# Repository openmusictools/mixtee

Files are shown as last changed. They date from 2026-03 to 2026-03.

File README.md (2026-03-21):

# MIXTEE

**Open-source 16-input / 8-output digital mixer with MIDI control and 16-track recording.**

Built around the Teensy 4.1, MIXTEE is a compact desktop mixer designed for electronic musicians, synth enthusiasts, and DIY audio builders. It handles mixing, monitoring, MIDI control, multitrack recording to SD card, and 16-in/8-out AES67 network audio — all in a 260 × 100 × 50 mm enclosure.

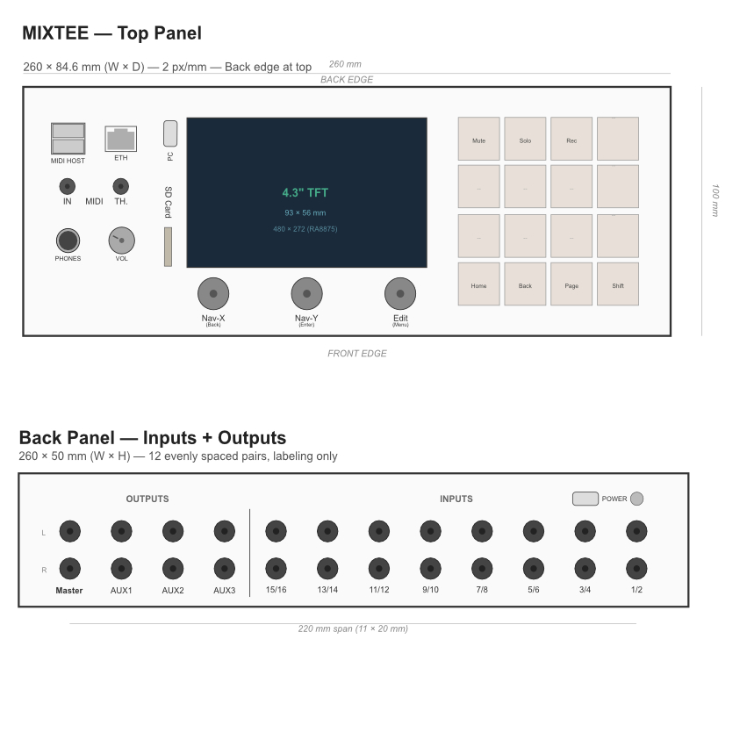
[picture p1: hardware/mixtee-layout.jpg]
MIXTEE Layout


## Features

- **16 mono inputs** (8 stereo pairs) with per-channel gain, pan, mute, solo
- **8 outputs** (master stereo + 3 aux/FX sends)
- **16-track recording** direct to SD card (48 kHz / 24-bit WAV, 8 MB PSRAM buffer)
- **DAW connectivity** (16-in / 8-out via AES67 over Ethernet)
- **MIDI control** via 2× USB host ports + TRS MIDI in/out
- **4.3" TFT display** with 3 dedicated encoders (NavX, NavY, Edit) and 16 illuminated CHOC keys
- **Compact form factor** — 260 × 100 × 50 mm, all controls on top, all audio on back

## Architecture

MIXTEE uses four AK4619VN codecs on two TDM buses, driven by the Teensy 4.1's Cortex-M7 at 600 MHz. The analog front-end features OPA1678 op-amps with Sallen-Key anti-alias and reconstruction filters. Power is supplied via USB-C (5V/5A USB PD, fallback 5V/3A). DAW connectivity uses AES67 network audio over Ethernet (100 Mbps, DP83825I PHY on Teensy).

## Repository Structure

```
mixtee/
├── README.md              ← you are here
├── LICENSE                ← MIT (firmware) + CERN-OHL-P v2 (hardware) + CC BY 4.0 (docs)
├── docs/                  ← system-level design specifications
│   ├── system-topology.md ← board summary, connector summary, back panel layout
│   ├── hardware.md        ← codecs, power system, BOM, target specs
│   ├── pin-mapping.md     ← Teensy 4.1 pin assignments, GPIO budget
│   ├── features.md        ← control interface, mixing, recording, MIDI, USB audio
│   ├── firmware.md        ← software architecture, libraries, state management
│   ├── ui-architecture.md ← view/page/module hierarchy, screen layouts
│   ├── enclosure.md       ← physical dimensions, panel layouts, jack spacing
│   ├── usb-audio.md       ← USB audio details + optional multitrack upgrade paths
│   ├── connector-parts.md ← connector MPN index
│   ├── pcb-design-rules.md ← trace widths, clearances, via sizes, manufacturing
│   └── pcbs-workflow.md   ← PCB design pipeline (SKiDL → FreeRouting → Gerbers)
├── hardware/              ← schematics, PCB, mechanical, BOM
│   ├── bom.csv            ← bill of materials
│   ├── mixtee-layout.*    ← panel layout (SVG, JPG, Affinity Designer)
│   ├── lib/               ← shared KiCad footprint library
│   └── pcbs/              ← per-board directories
│       ├── main/              ← Main Board (4-layer, not started)
│       ├── input-mother/      ← Input Mother Board (4-layer, routed)
│       ├── daughter-output/   ← Daughter/Output Board (2-layer, routed)
│       ├── io/                ← IO Board (2-layer, routed)
│       ├── keys4x4/           ← Keys4x4 PCB (2-layer, routed)
│       └── power/             ← Power Board (off-the-shelf)
│       Each board has: README.md, connections.md, architecture.md,
│       CLAUDE.md, and designs/ (KiCad files + gerbers)
└── firmware/              ← Teensy 4.1 firmware (coming in Phase 1)
```

## Documentation

### System-Level Docs

| Document | Description |
| --- | --- |
| [System Topology](docs/system-topology.md) | Board summary, connector summary, back panel layout, mechanical mounting |
| [Hardware](docs/hardware.md) | Codec architecture, power system, BOM tables, target specs |
| [Pin Mapping](docs/pin-mapping.md) | Teensy 4.1 pin assignments, GPIO budget |
| [Features](docs/features.md) | Mixing, routing, recording, MIDI control, DAW audio |
| [Firmware](docs/firmware.md) | Software architecture, audio pipeline, state management |
| [UI Architecture](docs/ui-architecture.md) | Display hierarchy, navigation model, screen layouts |
| [Enclosure](docs/enclosure.md) | Physical dimensions, panel layouts, connector placement |
| [Network Connectivity](docs/network-connectivity.md) | AES67 network audio, DAW integration, discovery protocols |
| [Connector Parts](docs/connector-parts.md) | Connector MPN index |
| [PCB Design Rules](docs/pcb-design-rules.md) | Trace widths, clearances, via sizes, stackup, manufacturing rules |

### Per-Board Docs

Each board under `hardware/pcbs/` has its own `README.md` (concept), `connections.md` (pinouts), and `architecture.md` (circuits). See the [System Topology](docs/system-topology.md) for the board summary table with links.

## Status

**Pre-prototype / Design phase.** Hardware and firmware specifications are being finalized. Phase 1 breadboard bring-up is next.

## License

MIXTEE is fully open source. Hardware is licensed under CERN-OHL-P v2 (permissive), firmware under MIT, and documentation under CC BY 4.0. See [LICENSE](LICENSE) for details.

**Author:** Juliusz Fedyk — [openaudiotools.com](https://openaudiotools.com)

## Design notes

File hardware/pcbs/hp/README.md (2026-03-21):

# PHONEE — Headphone Output Module

> **Note:** The canonical PHONEE specification lives in
> [openaudiotools/phonee](https://github.com/openaudiotools/phonee).
> This directory contains MIXTEE-specific integration context.
> Design changes should be made in PHONEE first and synced here.

**Dimensions:** ~30 × 20 mm | **Layers:** 2 | **Orientation:** Horizontal, under top panel (left zone) | **Instances:** 1

PHONEE is a **reusable headphone output module** — a standalone custom PCB designed for use across multiple audio devices (similar to [DESPEE](https://github.com/openaudiotools/despee) for displays). It carries a TPA6132A2 headphone amp, PCB-mount volume pot, and 1/4" TRS jack on a single board.

In MIXTEE, PHONEE sits in the **galvanically isolated analog domain**. It receives Master L/R audio and isolated power from Board 1-top (Input Mother TDM1) via a 4-pin JST-PH cable. Entire board runs on GND_ISO — no connection to system GND.

## Key Components

- TPA6132A2 headphone amplifier IC (SOT-23-8, ground-referenced, capless output)
- 10kΩ log potentiometer — PCB-mount (A10K)
- 1/4" TRS headphone jack (panel-mount, with detect switch)
- 4-pin JST-PH connector (signal + power input)

## Why a Reusable Module

- Keeps headphone output fully in the isolated analog domain without complicating the IO Board with split ground planes
- Single-board solution (amp + pot + jack) that can be dropped into any audio device needing a headphone output
- No off-the-shelf module combines all three components — this fills that gap
- Canonical source: [openaudiotools/phonee](https://github.com/openaudiotools/phonee)

## See Also

- [`connections.md`](connections.md) — connector pinouts (4-pin input cable, headphone jack)
- [`architecture.md`](architecture.md) — amp circuit, power, headphone detect routing
- [`../input-mother/connections.md`](../input-mother/connections.md) — Board 1-top HP cable pinout (source)

## Status

Not started. Design phase — will be developed in [openaudiotools/phonee](https://github.com/openaudiotools/phonee).

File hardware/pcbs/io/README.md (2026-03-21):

# IO Board

**Dimensions:** ~50 x 80 mm | **Layers:** 2 | **Orientation:** Horizontal, under top panel (left side) | **Instances:** 1

Handles Ethernet, USB MIDI host, and MIDI IN/OUT. All panel-mount components in the left column of the top panel. Headphone amp has moved to a standalone PHONEE module in the isolated analog domain.

## Key ICs

- FE1.1s USB 2.0 hub (SSOP-28) + 12 MHz crystal
- 2× TPS2051 USB host power switches (SOT-23-5)
- 6N138 optocoupler (DIP-8) — MIDI IN galvanic isolation

## Functional Zones

```
┌──────────────────────────────────────────────────────────────┐
│  USB-A (panel)   RJ45 (panel)                               │ y=0 (panel edge)
│                                                              │
│  FE1.1s + xtal   TPS2051x2   6N138                         │
│  15pF  15pF       caps         MIDI passives                │
│                                                              │
│  MIDI_IN (panel)  MIDI_OUT (panel)                          │
│                                                              │
│  [FFC ZIF 12-pin]  [6-pin ETH header]                      │ y=80 (interior edge)
└──────────────────────────────────────────────────────────────┘
 x=0                                                     x=50
```

## See Also

- [`connections.md`](connections.md) — FFC, Ethernet ribbon, panel-mount connector pinouts
- [`architecture.md`](architecture.md) — USB hub, MIDI, Ethernet circuit details

## Status

Fully routed via FreeRouting. Gerbers exported.

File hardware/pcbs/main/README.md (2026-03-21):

# Main Board

**Dimensions:** ~260 x 85 mm | **Layers:** 4 | **Orientation:** Horizontal, under top panel | **Instances:** 1

Central hub connecting all other boards. Houses the Teensy 4.1, galvanic isolation boundary, power management, I2C mux, and display interface. Panel-mount components (SD card) protrude through top panel cutouts. Encoders are on the DESPEE display PCB (not on this board).

## Key ICs

- Teensy 4.1 on socket headers (+ PSRAM)
- TCA9548A I2C mux (0x70) — isolates codec buses via FFC
- 2× Si8662BB-B-IS1 — 6-channel digital isolators (TDM signal isolation, 150 Mbps)
- 2× ISO1541DR — isolated bidirectional I2C (1 MHz)
- 2× Murata MEJ2S0505SC — isolated DC-DC 5V→5V_ISO (2W, 5.2 kV)
- 74LVC1G00 NAND soft-latch power circuit
- TPS22965 load switch (5A, soft-start)

## See Also

- [`connections.md`](connections.md) — all connector interfaces (FFC, JST, USB-C, display, SD, Ethernet ribbon)
- [`architecture.md`](architecture.md) — soft-latch, power distribution, I2C mux, galvanic isolation, pin assignments

## Status

Not started. Waiting on finalized pinout and input mother board validation.

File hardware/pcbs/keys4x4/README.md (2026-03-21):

# Keys4x4 PCB

**Dimensions:** ~72 x 80 mm | **Layers:** 2 | **Orientation:** Horizontal, mounted through top panel | **Instances:** 1

4×4 illuminated key grid with I2C-based matrix scanning. CHOC switches protrude through top panel cutouts, keycaps sit flush with panel surface.

## Components

- 16× Kailh CHOC hotswap sockets
- 16× WS2812B-2020 NeoPixels (daisy-chained)
- 16× 100nF ceramic decoupling caps
- 16× 1N4148 signal diodes (anti-ghosting)
- 1× MCP23017 I2C GPIO expander (0x20)
- 1× 6-pin JST-PH connector to Main Board

## See Also

- [`connections.md`](connections.md) — JST-PH pinout, NeoPixel chain
- [`architecture.md`](architecture.md) — MCP23017 key matrix wiring, key-switch mapping, NeoPixel daisy-chain

## Status

Fully routed via FreeRouting (139/139 nets). Gerbers exported.

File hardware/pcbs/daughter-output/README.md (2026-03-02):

# Daughter / Output Board (Universal)

**Dimensions:** 80 x 20 mm | **Layers:** 2 | **Orientation:** Vertical, below mother/output board | **Instances:** 5

Simplest board in the system — same PCB used for all 5 instances (2× input daughter, 2× output top, 1× output bottom). Jacks + ESD diodes + connector, no active signal processing.

## Components

- 4× 1/4" TS jacks (Switchcraft 112BPC)
- 4× BAT54 ESD clamp diodes (SOD-323)
- 1× 100nF decoupling cap (0603)
- 1× 6-pin JST-PH connector (to mother/output board above)

## See Also

- [`connections.md`](connections.md) — JST-PH pinout, jack nets
- [`architecture.md`](architecture.md) — design reuse, signal flow, routing summary

## Status

**Routing complete.** DRC 0 errors, 0 unconnected. Gerbers exported.

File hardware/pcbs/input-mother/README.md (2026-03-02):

# Input Mother Board

**Dimensions:** ~80 x 40 mm | **Layers:** 4 | **Orientation:** Vertical, mounted to back panel | **Instances:** 2

Board 1-top handles channels 1–8 (TDM1), Board 2-top handles channels 9–16 (TDM2). Same PCB design for both — I2C address selection via solder jumpers. Board 1-top also carries 4× output reconstruction filters + line drivers; Board 2-top leaves output section unpopulated.

## Key ICs

- 2× AK4619VN codec (4-in/4-out each, 8 ADC channels per board)
- 8× OPA1678 input buffer op-amps + 8× Sallen-Key anti-alias filters
- 8× ESD clamp diodes
- ADP7118 LDO (5V → 3.3V_A, per-board analog supply)

## See Also

- [`connections.md`](connections.md) — FFC, JST, jack pinouts (interface contract)
- [`architecture.md`](architecture.md) — analog stage design, LDO, I2C addressing, BOM variant
- [`ak4619-wiring.md`](ak4619-wiring.md) — AK4619VN codec reference (pin table, registers, TDM)

## Status

Routed via FreeRouting (4 unrouted, 5 DRC unconnected — plane fills resolve most). Gerbers exported.

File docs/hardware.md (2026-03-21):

# MIXTEE: Hardware

*← Back to [README](../README.md) | See also: [Features](features.md) · [Firmware](firmware.md) · [UI Architecture](ui-architecture.md) · [System Topology](system-topology.md)*

------

## Audio Codec Architecture

- **Codec:** 4× AK4619VN (4-in / 4-out per chip, unified vendor)
  - Total capacity: 16 ADC channels + 16 DAC channels (8 DAC outputs used)
  - Single vendor simplifies TDM formatting, clock distribution, and register configuration
  - TDM/I2S serial audio interface
  - I2C control interface (2 addresses via single CAD pin; TCA9548A I2C mux on main board isolates each codec board — see [AK4619VN Wiring](../hardware/pcbs/input-mother/ak4619-wiring.md))
  - 48 kHz / 24-bit target
- **Digital Interface:** TDM over I2S to Teensy 4.1

## TDM Bus Assignment

- **TDM1 (SAI1):** Codecs U1 + U2 (ADC channels 1-8, DAC channels 1-8)
  - U1: TDM slots 0-3 on SAI1_RX_DATA0 (pin 8) — inputs 1-4; slots 0-3 TX — outputs 1-4 (Main L/R + Aux1 L/R)
  - U2: TDM slots 0-3 on SAI1_RX_DATA1 (pin 32) — inputs 5-8; slots 0-3 TX — outputs 5-8 (Aux2 L/R + Aux3 L/R)
  - Each codec transmits on its own SDOUT line — no bus contention
- **TDM2 (SAI2):** Codecs U3 + U4 (ADC channels 9-16, DAC unused)
  - U3: TDM slots 0-3 on SAI2_RX_DATA0 (pin 5) — inputs 9-12
  - U4: TDM slots 0-3 on SAI2_RX_DATA1 (pin 34, bottom pad) — inputs 13-16
  - DAC sections on U3/U4 unused (available for future expansion)
- **Clock:** Teensy generates MCLK (256fs = 12.288 MHz), BCLK, and LRCLK as TDM master
  - All four codecs slave to shared clock tree
  - BCLK = 48 kHz × 16 slots × 32 bits = 24.576 MHz per TDM bus
- **Audio Library modification required:** Enable SAI multi-data-line receive via SAI_RCR3 register to read both RX_DATA0 and RX_DATA1 per bus

## MCU / DSP Core

- **Teensy 4.1** (ARM Cortex-M7 @ 600 MHz)
  - 2× I2S/TDM interfaces for 16-in/8-out audio
  - USB host capability for MIDI controllers
  - Extensive GPIO for encoders/buttons/display
  - PJRC Audio Library ecosystem (mixer objects, effects, routing)
- **DAW connectivity:** Via Ethernet (AES67) — 16-in / 8-out network audio using virtual soundcards on the host PC. See [network-connectivity.md](network-connectivity.md) §9 for DAW integration details.

------

*Analog stage design (input stage, output stage, op-amp selection): see [Input Mother Board architecture](../hardware/pcbs/input-mother/architecture.md).*

------

## Power System

5V @ 5A via USB PD (off-the-shelf STUSB4500 breakout). Worst-case draw ~2.91A, ~50% headroom. See **[Power System](power.md)** for full details (input, budget, distribution, protection, soft-latch circuit).

- **DAW connectivity:** Via Ethernet (AES67) — 16-in / 8-out network audio via RJ45 MagJack on IO Board. See [network-connectivity.md](network-connectivity.md) §9 for stream layout and recommended software.

*USB host hub details: see [IO Board architecture](../hardware/pcbs/io/architecture.md).*

*Headphone amplifier details: see [PHONEE architecture](../hardware/pcbs/hp/architecture.md).*

*Ethernet details: see [IO Board architecture](../hardware/pcbs/io/architecture.md).*

*MIDI IN circuit details: see [IO Board architecture](../hardware/pcbs/io/architecture.md).*

*MIDI OUT circuit details: see [IO Board architecture](../hardware/pcbs/io/architecture.md).*

*Galvanic isolation details: see [Main Board architecture](../hardware/pcbs/main/architecture.md#galvanic-isolation).*

------

## PCB Layer Stackup

| Board | Layers | Stackup | Rationale |
|---|---|---|---|
| Main Board | **4-layer** | Sig / GND / PWR / Sig | TDM clock integrity (24.576 MHz BCLK), galvanic isolation boundary (GND + GND_ISO islands), power distribution |
| IO Board | **2-layer** | Sig / GND | USB Full-Speed (12 Mbps), post-PHY Ethernet analog, MIDI — no high-speed digital |
| Power Module | Off-the-shelf | — | STUSB4500 USB PD breakout (purchased module, no custom PCB) |
| Input Mother Board | **4-layer** | Sig / GND_ISO / PWR_ISO / Sig | AK4619VN codecs + analog input stages + TDM signals; entirely on GND_ISO (isolated domain) |
| Input Daughter Board | **2-layer** | Sig / GND_ISO | Simple board: jacks + ESD diodes + connector; inherits isolation from mother board |
| Output Board | **2-layer** | Sig / GND_ISO | Simple board: jacks + ESD diodes + connector; inherits isolation from mother board |
| PHONEE | **2-layer** | Sig / GND_ISO | TPA6132A2 headphone amp + PCB-mount volume pot + TRS jack; entirely on GND_ISO; reusable external module ([openaudiotools/phonee](https://github.com/openaudiotools/phonee)) |
| Keys4x4 PCB | **2-layer** | Sig / GND | Switches + LEDs only, no high-speed signals |

------

## Noise Mitigation Strategy

### Galvanic Isolation (Primary)

The primary noise mitigation is **galvanic isolation** between the digital domain (Main Board, IO Board, Keys4x4 PCB) and the analog domain (Input Mother Boards, Daughter/Output Boards, PHONEE). No shared copper between domains — all signals and power cross the boundary through isolators:

- **Si8662BB-B-IS1** digital isolators (×2) for TDM signals (150 Mbps, 6-channel)
- **ISO1541DR** isolated I2C (×2) for codec/MCP23008 control
- **MEJ2S0505SC** isolated DC-DC converters (×2) for analog domain power

This eliminates USB ground loops, switching noise, and NeoPixel current spikes from the analog signal path entirely — not just attenuated, but physically absent.

### Power Integrity

1. **Bulk capacitor (1000–2200 µF)** across 5V/GND near NeoPixels (buffers current spikes from up to 960 mA worst-case draw)
2. **Isolated DC-DC (MEJ2S0505SC)** provides galvanic separation between digital and analog power — replaces ferrite bead approach
3. **Post-filter on analog boards:** ferrite bead (600Ω @ 100 MHz) + 10 µF ceramic after 5V_ISO, before ADP7118 LDO input. Combined PSRR >100 dB at DC-DC switching frequency
4. **Local decoupling** at every IC and subsystem boundary (0.1 µF ceramic + bulk)
5. **NeoPixel series resistor (300–500 Ω)** in data line near first pixel (reduces ringing)

### Grounding

- **Digital domain (Main Board):** Single continuous GND plane with star topology for high-current returns (USB, NeoPixels, TFT backlight)
- **Analog domain (Mother Boards, PHONEE):** Continuous GND_ISO plane, entirely isolated from digital GND
- **Main Board isolation boundary:** GND_ISO exists only as small copper islands around isolator Side 2 pins and FFC pads. **≥1 mm clearance** between GND and GND_ISO copper on all layers
- **No ground connection** between domains — isolation integrity must be maintained through layout

### Layout

- **Physical separation:** USB hub/switching away from audio codecs and outputs (on separate boards)
- **Isolation component placement:** MEJ2S0505SC, Si8662BB, ISO1541 placed near each FFC connector on Main Board
- **Keep DC-DC away from signal isolators:** MEJ2S0505SC switching noise could couple into Si8662BB signal pins
- **Short audio traces:** minimize analog signal path length on Mother Boards

### Firmware-Based Noise Mitigation

- **Cap NeoPixel global brightness** (30% default recommended — reduces noise and power; hardware is sized for uncapped operation in case builders remove the limit)
- **Smooth parameter changes** (no abrupt steps in gain/pan)
- **USB host power management** (ability to power-cycle ports via software)
- **I2C mute sequencing:** MCP23008 mute outputs held low during boot; high after DSP stabilizes (~500 ms)

------

## Bill of Materials

The canonical BOM is [`hardware/bom.csv`](../hardware/bom.csv). Per-board component details are in each board's `architecture.md`.

------

## Target Specifications

### Audio Performance (Target Goals)

- **Sample Rate:** 48 kHz
- **Bit Depth:** 24-bit
- **Latency:** <5 ms round-trip (ADC → processing → DAC)
- **THD+N:** <0.01% (codec-dependent, AK4619VN: 0.001% typ at 1 kHz)
- **Dynamic Range:** >100 dB (codec-dependent)
- **Crosstalk:** <-80 dB @ 1 kHz

### Recording Performance (Target Goals)

- **Channels:** 16 simultaneous (post-ADC, pre-mixer)
- **Format:** 48 kHz / 24-bit WAV (RF64 for files >4 GB)
- **Data Rate:** 2.3 MB/s sustained
- **Max Session Length:** Limited by SD card capacity (~3.5 hrs on 32 GB, ~7 hrs on 64 GB)
- **Buffer Tolerance:** >3 seconds of SD write stall without dropout (8 MB PSRAM)
- **Zero-dropout target:** No missed samples during normal operation with recommended SD card class

### Physical (Estimated)

- **Dimensions:** 260×100×50 mm (W×D×H) — compact desktop format
- **Weight:** ~1-1.5 kg (depending on enclosure material)
- **Power Consumption:** 5V @ ~2.2A typical, ~2.91A worst-case (uncapped NeoPixels); 5A supply via USB PD

### Panel Layout (v2.0)

**Enclosure:** 260 × 100 × 50 mm (W × D × H). See [enclosure.md](enclosure.md) for full detail.

**Top panel (260 × 84.6 mm — all controls and connectivity):**

Left zone (Main Board):
- Full-size SD card slot (left of display, vertically aligned with bottom edge of screen, slot opens upward)
- 1× Custom display PCB (ESP32-S3-WROOM-1-N16R8 + 4.3" 800×480 LCD panel; designed to MIXTEE enclosure dimensions)
- 3× rotary encoders (NavX + NavY + Edit): horizontal row below display, mounted on DESPEE display PCB (not wired to Main Board)

Center:
- 16× CHOC key switches (4×4 grid): top-aligned with display

Left column (IO Board + PHONEE):
- MIDI HOST dual USB-A (stacked)
- ETH RJ45 (Ethernet)
- MIDI IN + MIDI OUT (3.5mm TRS Type A)
- Headphone output (from PHONEE module, isolated analog domain)
- PHONES label + VOL pot (PCB-mount on PHONEE)

**Back panel (260 × 50 mm — all audio I/O + USB-C + power):**

- 24× 1/4" TS jacks: 12 evenly spaced stereo pairs (L top row, R bottom row), 20 mm center-to-center
- Order left to right (looking at back): Master, AUX1, AUX2, AUX3, 15/16, 13/14, 11/12, 9/10, 7/8, 5/6, 3/4, 1/2
- No physical gaps between output and input groups — separation by labeling only
- PWR USB-C (power only, 5V/5A USB PD): right side of back panel, on dedicated Power Board
- POWER button (momentary, screw-collar): next to PWR USB-C on back panel, wired to Main Board soft-latch

**No front, left, or right side panels with connectors.** All I/O accessible from top and back.

**Validate** with 1:1 panel template printout during Phase 1 before committing to enclosure fabrication. See [`mixtee-layout.svg`](../hardware/mixtee-layout.svg) for detailed panel drawings.

### User Experience

- **Boot Time:** <3 seconds to ready
- **UI Responsiveness:** <50 ms encoder/button to visual feedback (encoders are local to DESPEE — sub-frame LVGL latency for navigation; semantic events forwarded to Teensy over UART)
- **MIDI Latency:** <10 ms CC message to parameter change
- **Hot-plug:** MIDI controllers safe to connect/disconnect during operation

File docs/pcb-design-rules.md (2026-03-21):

# MIXTEE: PCB Design Rules

*← Back to [README](../README.md) | See also: [System Topology](system-topology.md) · [Hardware](hardware.md)*

------

## Manufacturing Target

Primary: **JLCPCB** or **PCBWay** standard capabilities. All design rules chosen to be within standard process limits (no advanced/special process charges).

------

## Trace Widths

| Net Class | Trace Width | Use |
|---|---|-----|
| Default (digital signal) | 0.25 mm (10 mil) | General digital signals, I2C, SPI, GPIO |
| Audio_Analog | 0.30 mm (12 mil) | Codec analog I/O, op-amp paths, reconstruction filter traces |
| Power | 0.5–1.0 mm (20–40 mil) | 5V, 3.3V, GND power distribution; width depends on current |
| USB_Diff | 0.2 mm (8 mil) | USB D+/D- differential pair; width set by 90Ω impedance target |

------

## Clearances

| Parameter | Value | Notes |
|---|---|---|
| Trace-to-trace (minimum) | 0.15 mm (6 mil) | JLCPCB standard minimum |
| Trace-to-pad | 0.15 mm | |
| Pad-to-pad | 0.15 mm | |
| USB differential pair gap | Per impedance calculator | Target 90Ω differential; use stackup-specific calculator |
| Analog-to-digital signal spacing | ≥0.5 mm preferred | Keep analog traces away from digital switching signals |
| Courtyard-to-courtyard | 0.25 mm | Component placement clearance |

------

## Via Sizes

| Via Type | Drill Diameter | Annular Ring | Use |
|---|---|---|-----|
| Standard signal | 0.3 mm (12 mil) | 0.15 mm | General signal vias |
| Power | 0.4 mm (16 mil) | 0.2 mm | 5V, 3.3V, GND power vias |
| Thermal via array | 0.3 mm | 0.15 mm | Under QFN exposed pads (AK4619VN, STUSB4500); 4-9 vias per pad |

------

## Copper Weight

| Layer Position | Weight | Notes |
|---|---|---|
| Outer layers (Top, Bottom) | 1 oz (35 µm) | Standard, sufficient for power and signal |
| Inner layers (GND, PWR) | 0.5 oz (17.5 µm) | Standard 4-layer inner core |

**4-layer stackup (Main Board, Input Mother Board):**

| Layer | Function | Copper |
|---|---|---|
| L1 (Top) | Signal + components | 1 oz |
| L2 | GND plane (continuous) | 0.5 oz |
| L3 | Power plane (5V / 3.3V) | 0.5 oz |
| L4 (Bottom) | Signal + components | 1 oz |

**2-layer stackup (IO Board, Daughter/Output, Keys4x4 PCB):**

| Layer | Function | Copper |
|---|---|---|
| L1 (Top) | Signal + components | 1 oz |
| L2 (Bottom) | GND plane + some signal routing | 1 oz |

------

## USB Differential Pair

| Parameter | Target |
|---|---|
| Impedance | 90Ω differential |
| Trace width | Per stackup calculator (~0.2 mm typical on 4-layer) |
| Pair spacing (edge-to-edge) | Per stackup calculator |
| Length matching | ±0.1 mm between D+ and D- |
| Routing | Avoid vias; route on single layer if possible |
| Keep-out | No other traces within 3× trace width of pair edges |

------

## Grounding Strategy

### Digital Domain (Main Board, IO Board, Keys4x4 PCB)

- **Single continuous GND plane** on L2 (4-layer) or L2 (2-layer)
- **Star topology** for high-current returns: USB host VBUS, NeoPixels, TFT backlight returns converge near power entry point
- **Component placement** enforces separation: power/USB at one end → Teensy/UI center → isolation boundary at opposite end

### Analog Domain (Input Mother Boards, Daughter/Output, PHONEE)

- **Single continuous GND_ISO plane** — entirely isolated from digital GND
- **Short return paths** for audio signals — keep analog traces close to their ground reference
- All boards in the analog domain have no copper connection to system GND

### Isolation Boundary (Main Board only)

- GND_ISO exists on the Main Board as **small copper islands** around isolator Side 2 output pins and FFC pads
- **≥1 mm clearance** between GND and GND_ISO copper on all layers (creepage requirement)
- Place MEJ2S0505SC, Si8662BB, ISO1541 near each FFC connector
- Keep MEJ2S0505SC (switching DC-DC) physically separated from Si8662BB signal pins

### General

- **Thermal relief** on through-hole pads connected to ground plane (4 spokes, 0.3 mm spoke width)

------

## QFN Pad Design

For QFN packages (AK4619VN QFN-32, STUSB4500 QFN-24):

- **Exposed pad:** Solder paste coverage ~60-70% (windowed stencil pattern to prevent tombstoning)
- **Thermal vias:** 4-9 vias (0.3mm drill) in exposed pad, connected to ground plane
- **Via-in-pad:** Fill and cap if budget allows; otherwise use via tenting on bottom side
- **Pad extension:** Per manufacturer recommendation; no solder mask on exposed pad area

------

## Silkscreen

- **Minimum line width:** 0.15 mm (6 mil)
- **Minimum text height:** 1.0 mm
- **Reference designators:** On all components
- **Board markings:** Board name, revision, date, CERN-OHL-P v2 notice, openaudiotools.com
- **Polarity indicators:** On all polarized components (diodes, electrolytic caps, ICs)
- **Pin 1 markers:** On all ICs

------

## Board Outline

- **Edge clearance:** ≥0.3 mm from board edge to nearest copper
- **Mounting holes:** M3 (3.2 mm drill) or M2.5 (2.7 mm drill) with 6 mm pad, connected to GND
- **Corner radius:** 1.0 mm minimum on all boards (prevents stress cracks)
- **Panel tabs:** V-score or tab-route for production panels (discuss with fab house)

------

## Design Rule Check (DRC) Settings

Apply these as KiCad net class rules:

```
Net class: Default
  Track width: 0.25mm
  Clearance: 0.2mm
  Via size: 0.6mm (0.3mm drill)

Net class: Power
  Track width: 0.5mm
  Clearance: 0.2mm
  Via size: 0.8mm (0.4mm drill)

Net class: Audio_Analog
  Track width: 0.3mm
  Clearance: 0.25mm
  Via size: 0.6mm (0.3mm drill)

Net class: USB_Diff
  Track width: 0.2mm
  Clearance: 0.15mm
  Differential pair gap: (per impedance calc)
```

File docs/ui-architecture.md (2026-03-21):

# MIXTEE: UI Architecture

*← Back to [README](../README.md) | See also: [Features](features.md) · [Hardware](hardware.md) · [Firmware](firmware.md)*

------

## Overview

> **The [DESPEE](https://github.com/openaudiotools/despee) display module (ESP32-S3) is a device-agnostic LVGL display engine.** It has no knowledge of MIXTEE, channels, or mixing — it only knows how to render widgets. The Teensy is the brain: it reads UI definitions from `ui.json` on the SD card, translates them into binary widget commands, and streams them to the ESP32 over UART. This architecture is reusable across MIXTEE, SYNTEE, and future devices.

> For the binary serial protocol specification, see [Display Protocol](display/protocol.md). For the SD card update mechanism, see [SD Update](sd-update.md).

The MIXTEE display UI is built on a modular, hierarchical framework designed for two goals: fast access to the most-used mixing parameters (gain, level, mute) with minimal button presses, and extensibility so that community contributors can add new processing modules without reworking the navigation engine.

The signal path is hardcoded in the DSP audio graph (fixed at compile time). UI modules provide windows into different points of that fixed graph — rearranging or adding modules on screen does not affect DSP processing order.

No internal FX for now. The mixer does not include built-in effects (reverb, delay, compression). Aux sends route to external FX gear. Internal FX may be added in a future revision as additional modules.

------

## Display Engine Architecture

### Rendering Split

| Responsibility | Owner | Notes |
|---|---|---|
| UI layout definitions | `ui.json` on SD card | Parsed by Teensy at boot |
| Widget creation commands | Teensy | Translates JSON → binary CREATE_WIDGET protocol |
| Focus group definitions | Teensy | Defines encoder groups via CREATE_FOCUS_GROUP / ADD_TO_GROUP at boot |
| LVGL widget rendering | ESP32-S3 display engine | Generic renderer, no device knowledge |
| Encoder input + navigation/focus | ESP32-S3 display engine | 3× on-board encoders drive LVGL encoder groups natively; forwards semantic events |
| Meter data streaming | Teensy | METER_BATCH at 30 Hz (~4.6 KB/s) |
| Parameter updates | Teensy | SET_VALUE/SET_TEXT/SET_STATE on change |
| Touch input | ESP32-S3 → Teensy | Coordinate-based events (TOUCH_DOWN/UP/DRAG) |
| Touch interpretation | Teensy | Maps coordinates to UI elements via widget bindings |
| UI state sync | Teensy | Processes SELECTION_CHANGED/VALUE_CHANGED/PAGE_CHANGED from ESP32 → updates internal state (DSP params, selected channel, current page) |
| State replication | Teensy | Continuous push: every parameter change → SET_VALUE to display, regardless of visible page. Periodic sync: cycles all widgets every ~6s as insurance against dropped frames. See [Display Protocol § State Synchronization](display/protocol.md#state-synchronization-model) |

### ui.json Format

The UI layout is defined in a JSON file on the SD card (`/SYSTEM/ui.json`), loaded by the Teensy at boot. This is what makes the same display engine work for different devices — MIXTEE, SYNTEE, etc. each ship their own `ui.json`.

```json
{
  "device": "MIXTEE",
  "version": "1.0.0",
  "display": { "width": 800, "height": 480 },
  "colors": { "bg": "#000000", "fg": "#FFFFFF", "accent": "#FF0000" },
  "pages": [
    {
      "id": 0, "name": "overview",
      "widgets": [
        { "id": 100, "type": "label", "x": 10, "y": 5, "w": 40, "h": 20, "text": "CH1" },
        { "id": 101, "type": "bar", "x": 10, "y": 30, "w": 20, "h": 200, "min": 0, "max": 1000 },
        { "id": 102, "type": "meter", "x": 35, "y": 30, "w": 15, "h": 200, "min": 0, "max": 1000 }
      ]
    }
  ],
  "bindings": {
    "meters": [{ "channel": 0, "widget": 102 }],
    "params": [{ "param": "ch1_gain", "widget": 110, "type": "value" }]
  }
}
```

**Key fields:**
- `pages[]` — each page contains widget definitions with absolute positioning
- `bindings.meters[]` — maps audio channel indices to meter widget IDs (for METER_BATCH routing)
- `bindings.params[]` — maps Teensy-side parameter names to widget IDs (for SET_VALUE/SET_TEXT routing)

**Focus groups:** `ui.json` also defines encoder focus groups — which widgets belong to each group and in what order. The Teensy sends CREATE_FOCUS_GROUP and ADD_TO_GROUP commands after widget creation, then SET_ENCODER_CONFIG to assign physical encoders to roles. At runtime, SET_ACTIVE_GROUP switches encoder targets as the user navigates between views/pages.

```json
{
  "focus_groups": [
    {
      "id": 0, "name": "overview_nav",
      "widgets": [100, 101, 102, 103, 104, 105, 106, 107]
    },
    {
      "id": 1, "name": "overview_edit",
      "widgets": [110, 111, 112, 113, 114, 115, 116, 117]
    }
  ],
  "encoders": [
    { "index": 0, "role": "navigation", "default_group": 0 },
    { "index": 1, "role": "navigation", "default_group": 0 },
    { "index": 2, "role": "editing", "default_group": 1 }
  ]
}
```

**Size:** ~15–25 KB for full MIXTEE UI. ArduinoJson streaming parser handles this in ~5 ms.

### Widget Types

| Type | LVGL mapping | Use case |
|---|---|---|
| Container | lv_obj | Grouping, backgrounds |
| Label | lv_label | Channel names, values, headers |
| Meter | lv_bar (vertical) | Level meters (peak + RMS) |
| Knob | lv_arc | Gain, pan controls |
| Slider | lv_slider (horizontal) | Pan sliders |
| Bar | lv_bar (vertical) | EQ bands, send levels |
| Button | lv_btn | Mute, solo, rec indicators |
| Icon | lv_img | Status icons |
| Rect | lv_obj + style | Colored rectangles, separators |
| Page | lv_obj (screen) | Full-screen page containers |

### Boot-Time Widget Creation

All pages and widgets are created at startup via CREATE_WIDGET commands. Pages are switched at runtime via SET_VISIBLE — no dynamic widget creation during operation. This avoids LVGL memory fragmentation.

The widget table on the ESP32 is a flat array indexed by widget ID (max ~128 entries), providing O(1) lookup for 30 Hz meter updates.

------

## Hierarchy

```
View
  └→ Page
       └→ Module
            └→ Component
                 └→ Param
```

**View:** A top-level screen context representing a major section of the mixer. Views are navigated at the Global level using the Nav encoder.

**Page:** A vertical layer within a view. Each page fills the full 480×272 display. Pages within a view are scrolled using PAGE + Nav. All pages in a view share a persistent channel name strip header.

**Module:** A self-contained UI block within a page, representing one stage of signal processing for one channel. Modules are laid out horizontally (one per channel) within a page. At the Page level, Nav encoder selects between modules.

**Component:** A single processing element within a module (e.g., the Low band of an EQ module). At the Module level, Nav encoder selects between components.

**Param:** An individual adjustable value within a component (e.g., level, frequency, Q). At the Component level, Nav encoder selects params, Edit encoder adjusts the selected param.

------

## Views

| View | Contents | Pages |
| --- | --- | --- |
| Overview | Read-only metering of all 16 inputs + 4 output buses | 1 (no sub-pages) |
| Inputs 1–8 | Channel strips for inputs 1–8 | Page 1: Main strip, Page 2: EQ + Sends |
| Inputs 9–16 | Channel strips for inputs 9–16 | Page 1: Main strip, Page 2: EQ + Sends |
| Outputs | Output bus strips (Aux1, Aux2, Aux3, Main) | Page 1: Main strip |
| Recorder Setup  | Recording configuration and status | Page 1: Settings |

------

## Overview (Read-Only)

The Overview is a non-interactive display of all channels and buses. It shows vertical level meters (peak + RMS) for all 16 inputs plus Aux1, Aux2, Aux3, and Master. Mute/solo status and record arm indicators are visible per channel. No parameter editing from this view — it is purely visual for monitoring the full mix at a glance.

The Overview is the Home destination. Pressing the Home button from any depth returns here immediately (hard reset, navigation stack cleared).

When recording is active, the Overview shows elapsed time, file size, and buffer health.

For output buses, all except Master are FX sends. The Overview distinguishes these visually.

------

## Input Views (Inputs 1–8 / Inputs 9–16)

Each input view displays 8 channels. The two input views are structurally identical, just controlling different channel groups.

### Page 1: Main Strip

Each channel shows (top to bottom):

- **Channel name/number** (persistent header row, always visible across all pages)
- **Gain knob** (radial indicator; default param for this module — Edit encoder adjusts immediately at Page level)
- **Pan slider** (horizontal bar, center-detented)
- **Peak indicator** (P)
- **Level meter** (vertical bar, peak + RMS with horizontal tick marks)
- **Mute button** (M): hollow = disengaged, filled = muted
- **Solo button** (S): only visible on stereo-linked channels in place of second Mute
- **Record arm** (O): hollow circle = not armed, filled red circle = armed

**Mono vs. Stereo layout:**

- Mono pair: two independent channel strips side by side, each 60 px wide within a 120 px pair slot
- Stereo pair: single combined strip at 120 px, shared gain knob (displayed as split circle indicating L/R balance), single pan (becomes balance), shared mute, solo visible, single record arm

### Page 2: EQ + Sends

Accessed by PAGE + Nav down from Page 1. The channel name/number header persists.

**EQ Module (upper section):**

- 3 vertical bars per channel labeled L, M, H (Low, Mid, High)
- Bar height represents gain (center = flat/0 dB, up = boost, down = cut)
- Range: ±12 dB

**Send Module (lower section):**

- 3 vertical bars per channel labeled A1, A2, A3 (Aux 1, Aux 2, Aux 3)
- Bar height represents send level (bottom = off, top = full)

Maybe up to 2 modules per page — the exact vertical split between EQ and Sends depends on available pixel height after the header.

------

## Output View

Each output bus (Aux1, Aux2, Aux3, Main) has a simplified channel strip:

- Bus name header
- Peak indicators (L/R)
- Stereo level meter (L + R vertical bars)
- Mute indicator
- Record arm (for stem recording, future)

Output strips are wider than input strips since there are only 4 buses to fill the display width.

------

## Recorder Setup View

Full-screen settings page showing a parameter/value list:

- Record mode (Immediate / Armed)
- Arm threshold level
- File format info (channels, sample rate, bit depth)
- SD card status (capacity, free space)
- Current session info when recording

------

## Navigation Details

Navigation logic runs on the ESP32-S3 via LVGL encoder groups. The Teensy defines focus groups at boot and switches them at runtime via SET_ACTIVE_GROUP commands. The ESP32 handles focus traversal, value editing, and page switching locally, sending data updates (SELECTION_CHANGED, VALUE_CHANGED, PAGE_CHANGED) to the Teensy over UART.

### View Boundary Crossing

When the Nav encoder moves past the last channel in an input view, it seamlessly crosses into the neighboring view:

- **Inputs 1–8, right past ch 8** → Inputs 9–16, focus channel 9
- **Inputs 9–16, right past ch 16** → Outputs, focus first bus
- **Inputs 9–16, left past ch 9** → Inputs 1–8, focus channel 8
- **Outputs, left past first bus** → Inputs 9–16, focus channel 16

The current **page level is preserved** across boundary crossings. If you are on the EQ+Sends page for Inputs 1–8 and cross into Inputs 9–16, you land on the EQ+Sends page. If the destination view has fewer pages than the current page index, clamp to the last available page.

Navigation stops at the outer boundaries (left edge of Inputs 1–8, right edge of Outputs/Recorder Setup).

### Channel Name Strip

Every page within an input or output view displays a persistent channel name strip as the top row. For now, names are simply channel numbers (1, 2, 3/4, 5, 6, 7/8 for inputs; AUX1, AUX2, AUX3, MST for outputs). This header is the spatial anchor — it remains constant as you scroll through pages, so you always know which channels you are editing.

### Depth-Independent Buttons

**Mute, Solo, and Record** buttons always act on the currently selected channel, regardless of navigation depth. The "selected channel" is a global state variable set whenever a channel strip is focused at the Page level, and it persists as you drill into modules and components.

### Context Behavior Summary

| Context | Nav ↻ | PAGE + Nav ↻ | Push Nav | Edit ↻ | Push Edit |
| --- | --- | --- | --- | --- | --- |
| Global | Navigate views | Navigate pages | Enter page | × | × |
| Page | Select modules | Navigate pages | Enter module | Edit default module param | Enter module |
| Module | Select components  | Navigate pages | Enter component | Edit default component param | Enter component |
| Component | Select params | Navigate pages | × | Edit selected param | × |

------

## Module Architecture (Firmware)

Modules are self-contained UI+parameter units. Each module knows:

- Its component count (e.g., EQ module has 3: Low, Mid, High)
- Its default parameter (the param adjusted by Edit encoder at Page level without drilling in)
- How to draw its channel strip segment
- How to handle Edit encoder input at each depth

This architecture supports community extensibility. A contributor adds a new Module subclass, registers it on a page, and it integrates with the existing navigation engine automatically.

### Current Modules

**Input channels:**

| Module | Components | Default Param | Signal Stage |
| --- | --- | --- | --- |
| Main (Gain/Pan) | Gain, Pan | Gain | Input gain + panning |
| Level/Mute | Level, Mute, Solo | Level | Output level + muting |
| EQ | Low, Mid, High | — | 3-band fixed EQ |
| Sends | Send 1, Send 2, Send 3  | Send 1 | Aux bus send levels  |

*Note: The Main module is an exception — it holds both input-side (Gain, Pan) and output-side (Level, Mute) params for fast access. The signal path order (Gain → Pan → EQ → Sends → Level → Mute → Bus) is hardcoded in the DSP graph regardless of module display order.*

**Output buses:**

| Module | Components | Default Param | Signal Stage |
| --- | --- | --- | --- |
| Bus Master | Level, Mute | Level | Bus output level |

------

## Design Principles

### Modularity

The UI framework is designed so that open-source contributors can add new pages and modules for further signal processing without modifying the navigation engine. The module interface is the extension point.

### Signal Path Encoding

The signal path should be hardcoded. The order of both modules and components on screen does not have to match the DSP processing order — just the separation of signal stages matters for the user's mental model. The actual processing order is fixed in the audio graph.

### Minimal Chrome

The display prioritizes channel data over navigation UI. The channel name strip and module content fill the screen. Navigation state is communicated through which elements are highlighted/focused, not through dedicated nav bars or breadcrumbs.

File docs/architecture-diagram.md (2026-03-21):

# MIXTEE: Hardware Architecture Diagram

*Back to [README](../README.md) | See also: [System Topology](system-topology.md) | [Hardware](hardware.md)*

------

## System Block Diagram

```mermaid
%%{init: {"flowchart": {"curve": "stepAfter"}} }%%
graph TB
    subgraph DIGITAL["Digital Domain - GND"]
        direction TB

        subgraph POWER_MOD["Power Module - off-the-shelf"]
            STUSB4500["STUSB4500\nUSB PD 5V/5A"]
        end

        subgraph MAIN["Main Board - 4-layer"]
            direction TB
            TPS22965["TPS22965\nLoad Switch"]
            MAIN_IO["SD Card SDIO\n74LVC1G00 Soft-Latch\nPC USB-C"]
            TEENSY["Teensy 4.1\nCortex-M7 600 MHz\nSAI1 + SAI2 TDM\nI2C - SPI0 - SDIO"]
            TCA["TCA9548A\nI2C Mux 0x70"]

            subgraph ISO_BLOCK["Isolation Boundary - x2 each"]
                direction LR
                SI8662["Si8662BB\nTDM Isolator\n6-ch 150 Mbps"]
                ISO1541["ISO1541\nI2C Isolator"]
                MEJ2["MEJ2S0505SC\nIsolated DC-DC\n5V to 5V_ISO"]
            end
        end

        subgraph IO["IO Board - 2-layer"]
            direction TB
            USB_HOST["FE1.1s Hub\n2x TPS2051\nDual USB-A"]
            MIDI["6N138 Opto\n3.5mm TRS\nMIDI IN + OUT"]
            RJ45["RJ45 MagJack\nEthernet"]
        end

        subgraph KEY["Keys4x4 PCB - 2-layer"]
            KEY_CONTENTS["MCP23017 0x20\n16x WS2812B NeoPixels\n16x CHOC Switches"]
        end

        subgraph PERIPHERALS["Peripherals"]
            direction TB
            ESP32["ESP32-S3\nCustom Display PCB\nWROOM-1-N16R8\n4.3in 800x480 LCD\n3x Encoders (NavX/NavY/Edit)"]
            PWR_BTN["Power Button\nmomentary"]
        end
    end

    subgraph ANALOG["Analog Domain - GND_ISO - galvanically isolated"]
        direction TB

        subgraph MOTHER1["Board 1-top - Input Mother TDM1 - 4-layer"]
            ADP_1["ADP7118 LDO\n5V_ISO to 3.3V_A"]
            U1["AK4619VN U1\nADC 1-4 / DAC 1-4"]
            U2["AK4619VN U2\nADC 5-8 / DAC 5-8"]
            MCP23008["MCP23008 0x21"]
            TS5A["TS5A3159\n4x Analog Mute Switch"]
            OPAMP_1["OPA1678 Op-Amps\nInput + Output stages"]
        end

        subgraph MOTHER2["Board 2-top - Input Mother TDM2 - 4-layer\n(input only, output DNP)"]
            ADP_2["ADP7118 LDO\n5V_ISO to 3.3V_A"]
            U3["AK4619VN U3\nADC 9-12"]
            U4["AK4619VN U4\nADC 13-16"]
            OPAMP_2["OPA1678 Op-Amps\nInput stages"]
        end

        subgraph DAUGHTERS["Daughter / Output Boards - 2-layer - ESD only"]
            D_IN["1-bot + 2-bot\nInput Daughters\n8x TS input jacks\nESD protection"]
            D_OUT["O-top + O-bot\nOutput Boards\n8x TS output jacks\nESD protection"]
        end

        HP_BOARD["PHONEE - 2-layer\nTPA6132A2 Amp\nPCB-mount Pot - 1/4in TRS"]
    end

    %% Power distribution
    STUSB4500 -. "2-pin JST-PH\n5V + GND" .-> TPS22965
    TPS22965 -. "5V_DIG" .-> MAIN_IO
    TPS22965 -. "5V_DIG" .-> TEENSY
    TPS22965 -. "5V" .-> MEJ2
    MEJ2 -. "5V_ISO isolated" .-> ADP_1
    MEJ2 -. "5V_ISO isolated" .-> ADP_2

    %% TDM audio (SAI1 / TDM1)
    TEENSY == "SAI1 TDM1\nBCLK 24.576 MHz\nLRCLK MCLK TX0 RX0 RX1" ==> SI8662
    SI8662 == "FFC 20-pin #1\nTDM1 isolated" ==> U1
    SI8662 == "TDM1" ==> U2

    %% TDM audio (SAI2 / TDM2)
    TEENSY == "SAI2 TDM2\nBCLK 24.576 MHz\nLRCLK MCLK TX0 RX0 RX1" ==> SI8662
    SI8662 == "FFC 20-pin #2\nTDM2 isolated" ==> U3
    SI8662 == "TDM2" ==> U4

    %% I2C topology
    TEENSY -- "I2C Wire\nSDA/SCL" --> TCA
    TCA -- "Ch 0" --> ISO1541
    ISO1541 -- "Isolated I2C\nvia FFC #1" --> U1
    ISO1541 -- "I2C" --> U2
    ISO1541 -- "I2C" --> MCP23008
    TCA -- "Ch 1" --> ISO1541
    ISO1541 -- "Isolated I2C\nvia FFC #2" --> U3
    ISO1541 -- "I2C" --> U4

    %% Keys4x4 PCB (single 6-pin cable)
    TEENSY -- "6-pin JST-PH\nI2C + NeoPixel + INT + 5V" --> KEY_CONTENTS

    %% IO Board cables
    TEENSY -- "12-pin FFC\nUSB Host + MIDI + ETH + 5V" --> IO
    TEENSY -- "6-pin ribbon\nETH TX/RX diff pairs" --> RJ45

    %% Peripherals
    TEENSY -- "Serial1 UART\npins 0/1\nwidgets + encoder events" --> ESP32
    PWR_BTN -- "sense\npins 40/41" --> TEENSY

    %% Analog input path
    D_IN -- "JST-PH 6-pin\nanalog in" --> OPAMP_1
    D_IN -- "JST-PH 6-pin\nanalog in" --> OPAMP_2
    OPAMP_1 -- "buffered" --> U1
    OPAMP_1 -- "buffered" --> U2
    OPAMP_2 -- "buffered" --> U3
    OPAMP_2 -- "buffered" --> U4

    %% Analog output path (Board 1-top)
    U1 -- "DAC out" --> OPAMP_1
    U2 -- "DAC out" --> OPAMP_1
    OPAMP_1 -- "line driver out" --> TS5A
    MCP23008 -. "GPIO mute control" .-> TS5A
    TS5A -- "10-pin JST-PH\n8ch post-mute" --> D_OUT
    TS5A -- "4-pin JST-PH\nMaster L/R + 5V_ISO" --> HP_BOARD

    %% Headphone detect return
    HP_BOARD -. "HP detect\nvia 4-pin cable" .-> MCP23008

    classDef digital fill:#1a1a2e,stroke:#4a9eff,color:#e0e0e0
    classDef analog fill:#1a2e1a,stroke:#4aff7f,color:#e0e0e0
    classDef isolation fill:#2e1a1a,stroke:#ff4a4a,color:#ffe0e0,stroke-width:3px
    classDef power fill:#2e2e1a,stroke:#ffcc4a,color:#e0e0e0

    class TEENSY,TCA,MAIN_IO digital
    class USB_HOST,RJ45,MIDI digital
    class KEY_CONTENTS digital
    class ESP32,PWR_BTN digital

    class U1,U2,U3,U4,OPAMP_1,OPAMP_2,ADP_1,ADP_2 analog
    class MCP23008,TS5A analog
    class D_IN,D_OUT analog
    class HP_BOARD analog

    class SI8662,ISO1541,MEJ2 isolation
    class STUSB4500,TPS22965 power
```

------

## Legend

| Line style | Meaning |
|---|---|
| `==` thick solid | TDM audio (24.576 MHz BCLK) |
| `--` solid | Control / data (I2C, SPI, USB, Serial, GPIO) |
| `-.` dotted | Power distribution, passive connections, detect signals |

| Node color | Domain |
|---|---|
| Blue border | Digital domain (GND) |
| Green border | Analog domain (GND_ISO) |
| Red border, thick | Galvanic isolation boundary components |
| Yellow border | Power entry / switching |

------

## Signal Path Summary

**Audio input:** 1/4" TS jack > ESD diode (daughter board) > JST-PH cable > op-amp buffer + anti-alias filter (mother board) > AK4619VN ADC > TDM > Si8662BB isolator > FFC 20-pin > Teensy SAI RX

**Audio output:** Teensy SAI TX > FFC 20-pin > Si8662BB isolator > AK4619VN DAC > reconstruction filter + output op-amp > TS5A3159 mute switch > 10-pin JST-PH cable > 1/4" TS jack (output board)

**Headphone:** DAC output (Board 1-top) > TS5A3159 > 4-pin JST-PH > PHONEE module (TPA6132A2 amp > PCB-mount volume pot > 1/4" TRS jack). Detect switch returns to MCP23008 GP6 via same cable.

**DAW audio:** Ethernet (AES67) > RJ45 MagJack (IO Board) > 6-pin ribbon > Teensy DP83825I PHY > QNEthernet stack > RTP encode/decode. 16-in / 8-out to DAW via virtual soundcard. See [network-connectivity.md](network-connectivity.md) §9.

**Isolation boundary:** 2x Si8662BB (TDM), 2x ISO1541 (I2C), 2x MEJ2S0505SC (power) -- all on Main Board, crossing via FFC 20-pin cables to mother boards

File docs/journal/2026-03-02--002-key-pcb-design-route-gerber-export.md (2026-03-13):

## 2026-03-02 — Key PCB: Design, Route, Gerber Export

### What was done
Created the Key PCB from scratch using `gen_pcb.py` (programmatic KiCad S-expression generator), routed via FreeRouting autoroute, and exported Gerbers. Board is fully routed with 0 errors and 0 unconnected items.

### Board specs
- **Dimensions:** 72 × 80 mm, 2-layer (originally 72×72, extended to 80mm to fit MCP23017 in bottom strip)
- **Components (67):** 16 Kailh CHOC hotswap sockets, 16 WS2812B-2020 NeoPixels, 16 NeoPixel decoupling caps (0603), 16 1N4148 anti-ghosting diodes (SOD-123), 1 MCP23017 GPIO expander (SOIC-28), 1 MCP decoupling cap, 1 JST-PH 6-pin connector
- **Nets (45):** GND, 5V, SDA, SCL, INT, NEO_DIN, NEO_D0–D14, COL0–3, ROW0–3, SW1_D–SW16_D
- **GND zone:** B.Cu full pour

### Layout
- 4×4 switch grid at 18mm pitch, centered in upper 72×72 area
- NeoPixels + caps below each switch center (3.5mm offset)
- Diodes to the right of each switch (rightmost column rotated 90° to avoid board edge)
- MCP23017 (U1) in bottom 8mm strip at (36, 73) rotated 90°
- JST-PH connector (J1) at (5, 75)
- NeoPixel chain: serpentine order [1,2,3,4,8,7,6,5,9,10,11,12,16,15,14,13]

### Pipeline
1. **gen_pcb.py** → generates `.kicad_pcb`, `.kicad_pro`, `fp-lib-table`
2. **pcbnew Python** → `ExportSpecctraDSN()`
3. **DSN patch** → split `kicad_default` into `Default` (0.2mm trace, 0.21mm clearance) and `Power` (0.4mm trace)
4. **FreeRouting** → autoroute (139/139 connections, 8.4 seconds)
5. **pcbnew Python** → `ImportSpecctraSES()`
6. **kicadmixelpixx MCP** → `open_project`, `refill_zones`, `save_project`
7. **kicad-cli** → DRC, Gerber + drill export

### Bugs found and fixed

**1. KiCad pad `(size)` is NOT rotated by footprint rotation**

When MCP23017 was placed at 90° rotation, pads defined as `(size 1.55 0.6)` stayed 1.55mm in board X — but pins were now spaced 1.27mm in board X. Adjacent pads overlapped by 0.28mm (10 shorts, 14 clearance violations, 24 solder mask bridge errors).

Verified via pcbnew Python: `pad.GetBoundingBox()` showed 1.55mm width in board X regardless of footprint rotation. `pad.GetOrientationDegrees()` returned 0° (absolute), not 90°.

Fix: swap pad size to `(size 0.6 1.55)` when footprint rotation is 90°/270°. The `(size)` in `.kicad_pcb` S-expressions is in **board coordinates**, not the footprint's local frame — pad positions `(at)` DO transform with rotation, but `(size)` does NOT.

**2. MCP23017 placement collisions (3 iterations)**

Initially placed U1 at board center (36, 36) — pins overlapped with SW10, D10, C7. Extended board from 72×72 to 72×80mm and moved U1 to bottom strip at (36, 73) rotated 90° (pins along X axis).

**3. LED/cap placement near board edge**

Bottom row LEDs at y=70.5 (switch y=63 + 7.5mm offset) too close to y=72 edge. Reduced LED_OFFSET from (0, 7.5) to (0, 3.5).

**4. FreeRouting clearance rounding**

First FreeRouting run with 0.2mm DSN clearance produced one trace at 0.198mm from SW14 pad (0.002mm under DRC threshold). Bumped DSN clearance to 0.21mm for margin — second run passed cleanly.

### DRC breakdown (post-route)

| Type | Count | Notes |
|---|---|---|
| **Errors** | **0** | (1 starved_thermal on J1 GND, cosmetic) |
| **Unconnected** | **0** | All 139 connections routed |
| text_height | 49 | Generated ref text sizes |
| lib_footprint_mismatch | 35 | Custom vs library footprints |
| lib_footprint_issues | 32 | Custom lib path resolution |
| silk_over_copper | 9 | Silk on exposed pads |
| silk_overlap | 2 | Adjacent component silk |
| silk_edge_clearance | 1 | Edge silk proximity |

### Files produced
- `hardware/pcbs/key/gen_pcb.py` — PCB generator script
- `hardware/pcbs/key/mixtee-key-pcb.kicad_pcb` — routed PCB
- `hardware/pcbs/key/mixtee-key-pcb.kicad_pro` — project file
- `hardware/pcbs/key/mixtee-key-pcb.dsn` — Specctra DSN
- `hardware/pcbs/key/mixtee-key-pcb.ses` — FreeRouting session
- `hardware/pcbs/key/gerbers/` — 29 Gerber layers + drill file

### Next steps
- Add NPTH mounting holes back to CHOC socket footprints (omitted for routing)
- Consider adding courtyard outlines and silkscreen labels to custom footprints
- Review NeoPixel chain signal integrity (serpentine path lengths)

---

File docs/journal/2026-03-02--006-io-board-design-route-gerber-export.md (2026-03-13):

## 2026-03-02 — IO Board: Design, Route, Gerber Export

### What was done
Created the IO Board from scratch using `gen_pcb.py`, routed via FreeRouting autoroute with multi-class DSN patching, and exported Gerbers. Board handles USB MIDI host hub, Ethernet, MIDI IN/OUT, and headphone amp connectivity.

### Board specs
- **Dimensions:** 50 x 80 mm, 2-layer
- **Components (33):** FE1.1s USB hub (SSOP-28), 2x TPS2051 USB power switches (SOT-23-5), 6N138 optocoupler (DIP-8), 12MHz crystal (3225), 12 capacitors, 5 resistors, 1 diode (SOD-123), USB-A dual stacked, RJ45 MagJack, 2x 3.5mm TRS MIDI jacks, FFC 12-pin ZIF, 6-pin ETH header, 4-pin HP header, HP TRS jack, 3-pin HP amp output header, dual-gang volume pot
- **Nets (37):** GND, 5V_DIG, V33, USB_UP/DN1/DN2 D+/D-, VBUS1/2, XTAL, ETH pairs (pre/post coupling cap), MIDI signals, HP signals
- **GND zone:** B.Cu full pour

### Layout zones (y=0 panel edge, y=80 interior)
- **y=0–15:** Panel-mount connectors — USB-A (12,8), RJ45 (38,10)
- **y=16–35:** ICs — FE1.1s (14,24), TPS2051 x2 (30/38,22), 6N138 (38,34), crystal + decoupling
- **y=36–55:** MIDI — SJ-3523 jacks (10/30,42), MIDI resistors/diode
- **y=55–65:** Headphone — TRS jack (6,58), volume pot (28,56), HP headers (42,48/62)
- **y=70–80:** Interior connectors — FFC 12-pin (14,76), ETH header (32,76), ETH coupling caps

### Net class strategy
Three DSN net classes with different clearances to handle SSOP-28 pin pitch constraints:

| Class | Nets | Trace width | Clearance (DSN) | Clearance (DRC) |
|---|---|---|---|---|
| Default | 25 signal nets | 0.25mm | 0.22mm | 0.20mm |
| Power | GND, 5V_DIG, V33, 5V_A, VBUS1/2 | 0.5mm | 0.22mm | 0.20mm |
| USB_Diff | USB_UP/DN1/DN2 D+/D- | 0.2mm | 0.16mm | 0.15mm |

USB nets need tighter clearance (0.16mm DSN / 0.15mm DRC) because FE1.1s SSOP-28 has 0.65mm pin pitch — only 0.25mm gap between pads, too tight for 0.2mm clearance. USB nets assigned to USB_Diff class in `.kicad_pro` so KiCad DRC uses 0.15mm clearance instead of Default 0.2mm.

### Pipeline
1. **gen_pcb.py** → `.kicad_pcb`, `.kicad_pro` (with net-to-class assignments), `fp-lib-table`
2. **pcbnew Python** → `ExportSpecctraDSN()`
3. **DSN patch** → split into Default/Power/USB_Diff with per-class clearances
4. **FreeRouting** → autoroute (0 unrouted, 5 passes, ~5 seconds)
5. **pcbnew Python** → `ImportSpecctraSES()`
6. **kicadmixelpixx MCP** → `open_project`, `refill_zones`, `save_project`
7. **kicad-cli** → DRC, Gerber + drill export

### Bugs found and fixed

**1. J7/J9 header overlap (first routing attempt)**

HP breakout header J7 (4-pin, 42,58, rot=90) and HP amp output header J9 (3-pin, 42,52, rot=90) had through-hole pads overlapping — only 0.92mm between pad centers with 1.75mm diameter pads. FreeRouting: 19 unrouted.

Fix: moved J7 from y=58 to y=62, J9 from y=52 to y=48. Second FreeRouting run: 0 unrouted.

**2. R4/J9 clearance violation (persistent across iterations)**

R4 (MIDI_OUT_SRC resistor) too close to J9 pad 3 (GND). KiCad rotation convention (90° = clockwise) places J9 pin 3 closer than expected. Initially at (40,46), moved to (40,42) — still 0.069mm clearance. Final fix: moved R4 to (34,46), well clear of J9 pad envelope.

**3. USB clearance vs SSOP-28 pitch conflict**

FreeRouting with 0.21mm clearance for all classes: 2 unrouted USB connections. SSOP-28 0.65mm pitch - 0.4mm pad width = 0.25mm gap, too narrow for 0.21mm clearance + trace. Solution: separate USB_Diff class with 0.16mm clearance in DSN, and net assignments in `.kicad_pro` so KiCad DRC applies 0.15mm clearance to USB nets.

### DRC breakdown (post-route)

| Type | Count | Severity | Notes |
|---|---|---|---|
| clearance | 1 | error | 5V_DIG track vs J4 pad: 0.1977mm vs 0.20mm (2.3um under, FreeRouting rounding) |
| copper_edge_clearance | 1 | error | ETH_RXP via near board edge: 0.375mm vs 0.50mm default |
| starved_thermal | 3 | error | J1 GND pads + VR1 GND: zone can't create enough thermal spokes |
| unconnected | 1 | — | VR1 pad A3 (GND) — zone fill isolation |
| lib_footprint_mismatch | 25 | warning | Generated vs library footprints (expected) |
| silk_over_copper | 15 | warning | Silk on exposed pads |
| silk_overlap | 14 | warning | Adjacent component silk |
| lib_footprint_issues | 8 | warning | Custom lib path |
| silk_edge_clearance | 4 | warning | Edge silk proximity |
| track_dangling | 1 | warning | Short GND track fragment |

All errors are cosmetic/marginal — 0 shorts, 0 USB clearance violations, all connections routed.

### Files produced
- `hardware/pcbs/io/gen_pcb.py` — PCB generator (33 components, 37 nets)
- `hardware/pcbs/io/mixtee-io-board.kicad_pcb` — routed PCB
- `hardware/pcbs/io/mixtee-io-board.kicad_pro` — project with USB_Diff net assignments
- `hardware/pcbs/io/mixtee-io-board.dsn` — Specctra DSN
- `hardware/pcbs/io/mixtee-io-board.ses` — FreeRouting session
- `hardware/pcbs/io/gerbers/` — 29 Gerber layers + drill file

### Next steps
- Verify FE1.1s pinout against actual datasheet (marked NEEDS VERIFICATION in gen_pcb.py)
- Consider moving ETH_RXP via inward to resolve edge clearance
- Add GND vias near J1/VR1 to fix starved thermal connections
- Main Board and Input Mother Board designs remain

---

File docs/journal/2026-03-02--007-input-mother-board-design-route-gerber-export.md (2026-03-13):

## 2026-03-02 — Input Mother Board: Design, Route, Gerber Export

### What was done
Created the Input Mother Board from scratch using `gen_pcb.py`, routed via FreeRouting autoroute with 3-class DSN patching, and exported Gerbers. This is the project's first 4-layer board. It handles 8 ADC channels (4 L + 4 R) via 2× AK4619VN codecs with Sallen-Key anti-alias filters.

### Board specs
- **Dimensions:** 80 × 40 mm, 4-layer (F.Cu signal, In1.Cu GND plane, In2.Cu V33_A plane, B.Cu signal)
- **Components (71):** 2× AK4619VN codecs (QFN-32, 5×5mm, 0.5mm pitch), 4× OPA1678 dual op-amps (SOIC-8), 1× ADP7118 LDO (SOIC-8), 4× Switchcraft 112BPC TS jacks, 1× FFC 16-pin ZIF, 1× JST-PH 6-pin, 8× ESD diodes (SOD-323), 4× AC coupling caps (0805), 32× filter passives (0603), 8× codec decoupling caps, 4× LDO caps, 2× PDN pull-up resistors
- **Nets (65):** Audio (40): AIN_*_AC, JACK_*, FN1_*, FOUT_*, DAIN_R*, FILT_IN_*, U*_AVDRV/VCOM; Power (4): GND, 5V_A, 5V_DIG, V33_A; Digital (8): MCLK, BCLK, LRCLK, SDIN1, SDOUT1/2, SDA, SCL
- **Zone fills:** GND on In1.Cu + B.Cu, V33_A on In2.Cu
- **2 instances:** Board 1-top (ch 1–8) and Board 2-top (ch 9–16) — same PCB, different TDM bus

### New footprints (vs previous boards)
- **QFN-32** — 5×5mm body, 0.5mm pitch, 32 pads (0.3×0.8mm) + 3.5×3.5mm exposed ground pad with 3×3 thermal via array (9 vias, 0.3mm drill)
- **SOIC-8** — 1.27mm pitch, 5.4mm pad-to-pad span, 1.5×0.6mm pads
- **FFC-16** — adapted from IO Board's 12-pin (16 pads at 1.0mm pitch + 2 mounting pads)

### Layout (y=0 interior, y=40 panel edge)

```
x=0                                                              x=80
┌──────────────────────────────────────────────────────────────────────┐
│  U3(LDO,6,3)  J5(FFC-16,30,2)           J6(JST-PH-6,65,2)        │ y=0
│  R17(16,4)     U1(AK4619,20,7)   R18(56,4)  U2(AK4619,60,7)      │
│  decoupling                       decoupling           D5-D8(77,y) │
│  C1-C4(AC coupling, y=12)                                          │
│                                                                     │
│  U4(OPA,8,17)  U5(OPA,24,17)  U6(OPA,44,17)  U7(OPA,64,17)      │ y=17
│  filter passives in columns ±6mm from each op-amp                   │
│                                                                     │
│  J1(10,40)    J2(30,40)         J3(50,40)     J4(70,40)           │ y=40
└──────────────────────────────────────────────────────────────────────┘
```

### Net class strategy
Three DSN net classes:

| Class | Nets | Trace width | Clearance (DSN) |
|---|---|---|---|
| Audio_Analog | 40 signal nets | 0.3mm | 0.26mm |
| Power | GND, 5V_A, 5V_DIG, V33_A | 0.5mm | 0.21mm |
| Default | MCLK, BCLK, LRCLK, SDIN1, SDOUT1/2, SDA, SCL | 0.25mm | 0.21mm |

### Pipeline
1. **gen_pcb.py** → `.kicad_pcb`, `.kicad_pro`, `fp-lib-table` (71 components, 65 nets, 4-layer)
2. **pcbnew Python** → `ExportSpecctraDSN()`
3. **DSN patch** → split into Audio_Analog/Power/Default with per-class widths and clearances
4. **FreeRouting** → autoroute (4 unrouted — FreeRouting 4-layer bugs, 30 passes, ~38 sec)
5. **pcbnew Python** → `ImportSpecctraSES()`
6. **kicadmixelpixx MCP** → `open_project`, `refill_zones` (3 zones), `save_project`
7. **kicad-cli** → DRC, Gerber + drill export (4 copper layers + silk/mask/paste/edge)

### Bugs found and fixed

**1. Board resized from 80×30mm to 80×40mm**

Original 30mm depth placed 112BPC jack tip pads at y≈12 (17.78mm from barrel at y=30), right in the codec/filter zone. With passive columns at y=14–21, there was no clearance. Extended to 40mm, pushing jacks to y=40 and tip pads to y≈22, well clear of the filter zone at y=14–21.

**2. QFN-32 exposed pad thermal vias**

AK4619VN requires thermal connection from exposed ground pad to ground plane. Added 3×3 grid of 0.3mm drill vias through all 4 layers, spaced 1.05mm apart within the 3.5mm pad area.

**3. KiCad pad size rotation (again)**

Same bug as Key PCB: `(size sx sy)` in `.kicad_pcb` is in board coordinates, doesn't rotate with footprint. Fixed fp_c0805, fp_c0603, fp_r0603 to swap pad dimensions when rotation is 90°/270°.

**4. AC coupling cap overlap (CW rotation convention)**

C1 at (13,12) with rot=90 — KiCad CW convention places pad 2 at board (13,11) not (13,13). C25 at (15,10) pad overlapped C1. Fixed by moving C25 to (16,10) and C27 to (56,10).

**5. Multiple pad overlap fixes**

- C29 at (2,5) overlapped U3 pin 4 → moved to (2,6.5)
- C30/C31 pads touching at x=13.5 → moved C31 from (15,2) to (16,2)
- D5-D8 overlapping filter passives → moved to vertical column at x=77, y=4/6/8/10

### DRC breakdown (post-route)

| Type | Count | Notes |
|---|---|---|
| **Shorts** | **0** | All pad overlaps resolved |
| **Clearance** | **0** | |
| **Unconnected** | **5** | U1 GND pad (track gap), V33_A ×3 (track gaps), SCL ×1 (track gap) — plane fills handle GND/V33_A |
| copper_edge_clearance | 5 | FreeRouting vias near board edge (0.32–0.42mm vs 0.50mm) |
| lib_footprint_mismatch | 66 | Custom footprints vs KiCad library |
| silk_over_copper | 58 | Silk on exposed pads |
| silk_overlap | 32 | Adjacent component silk |
| silk_edge_clearance | 17 | Edge silk proximity |
| lib_footprint_issues | 5 | Custom lib path |

### FreeRouting 4-layer notes

First multi-layer board in this project. FreeRouting has known bugs with 4-layer boards:
- `ArrayIndexOutOfBoundsException: Index 4 out of bounds for length 4` — intermittent
- `NullPointerException` in expansion room handling — intermittent
- `p_index out of range` warnings during optimization

Results are non-deterministic: same DSN produces 2–63 unrouted depending on which errors are hit. Best run achieved 4 unrouted. The remaining 5 DRC unconnected items are minor track gaps that copper plane fills resolve (3× V33_A, 1× GND) or can be hand-touched in KiCad (1× SCL).

### Files produced
- `hardware/pcbs/input-mother/gen_pcb.py` — PCB generator (~1250 lines, 71 components, 65 nets)
- `hardware/pcbs/input-mother/mixtee-input-mother.kicad_pcb` — routed 4-layer PCB
- `hardware/pcbs/input-mother/mixtee-input-mother.kicad_pro` — project file
- `hardware/pcbs/input-mother/mixtee-input-mother.dsn` — Specctra DSN with net classes
- `hardware/pcbs/input-mother/mixtee-input-mother.ses` — FreeRouting session
- `hardware/pcbs/input-mother/gerbers/` — 11 Gerber layers + drill + job file (14 files)

### Next steps
- Hand-fix SCL track gap in KiCad (0.42mm gap near U1 pad 28)
- Phase 2: Output reconstruction section for Board 1-top variant (+~20 components)
- Main Board design remains

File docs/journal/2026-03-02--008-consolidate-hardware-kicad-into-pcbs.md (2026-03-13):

# Consolidate `hardware/kicad/` into `hardware/pcbs/`

### What was done
Eliminated the `hardware/kicad/` directory by merging all KiCad project files into `hardware/pcbs/{board}/` alongside existing README.md files. Each board folder now has everything in one place (docs + design files + gerbers).

### Moves

| Source | Destination |
|---|---|
| `hardware/kicad/lib/` | `hardware/lib/` |
| `hardware/kicad/mixtee-daughter-output/*` | `hardware/pcbs/daughter-output/` |
| `hardware/kicad/mixtee-input-mother/*` | `hardware/pcbs/input-mother/` |
| `hardware/kicad/mixtee-io-board/*` | `hardware/pcbs/io/` |
| `hardware/kicad/mixtee-key-pcb/*` | `hardware/pcbs/key/` |

### Path updates
- **fp-lib-table** (4 files): `${KIPRJMOD}/../lib/` → `${KIPRJMOD}/../../lib/`
- **gen_pcb.py** (4 files): same fp-lib-table path fix in writer code
- **DSN files** (4 files): absolute path on line 1
- **Journal entries** (5 files): all `hardware/kicad/mixtee-*` → `hardware/pcbs/*`

### Removed
- `hardware/kicad/mixtee-power/` (empty placeholder — power board is off-the-shelf, `pcbs/power/README.md` exists)
- `hardware/kicad/` directory entirely

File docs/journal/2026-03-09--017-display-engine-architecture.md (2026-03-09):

# Display Engine Architecture

**Date:** 2026-03-09

## Summary

Designed and documented the display engine architecture for MIXTEE. The ESP32-S3 becomes a **device-agnostic LVGL widget rendering engine** with no device-specific knowledge. The Teensy is the brain: reads UI definitions from SD card, streams binary widget commands to the display over UART, and handles all firmware updates (including reflashing the ESP32 itself).

## Key Decisions

| Decision | Rationale |
|---|---|
| Device-agnostic display engine | Same ESP32 firmware reusable across MIXTEE, SYNTEE, and future devices |
| COBS-encoded binary protocol at 921600 baud | Unambiguous framing, 15x headroom over meter data rate |
| All widgets created at boot, switched via SET_VISIBLE | Avoids LVGL memory fragmentation |
| Flat widget table (array indexed by ID, max ~128) | O(1) lookup for 30 Hz meter updates |
| ui.json on SD card parsed by Teensy | Decouples UI layout from firmware; UI-only updates without reflash |
| Single SD card update mechanism (FlasherX + esp-serial-flasher) | Non-technical users (musicians) can update by copying files to SD |
| Pins 9/10 for ESP32 EN/GPIO0 bootloader control | Enables Teensy-controlled ESP32 reflash without external tools |
| 6-pin display header (was 4-pin) | Added ESP32_EN + GPIO0 for reflash; spare pins drop 11 → 9 |

## Pin Changes

| Pin | Old | New |
|-----|-----|-----|
| 9 | Spare | ESP32_EN (display reset) |
| 10 | Spare | ESP32_GPIO0 (display boot mode) |

Spare pins: 11 → 9 (pins 11, 12, 13, 14, 30, 35, 37, 38, 39).

## Protocol Summary

| Range | Category | Key commands |
|---|---|---|
| 0x01-0x07 | Lifecycle | HANDSHAKE, READY, CLEAR_ALL, BOOT_COMPLETE, HEARTBEAT, ACK/NACK |
| 0x10-0x16 | Widget creation | CREATE_WIDGET, DELETE_WIDGET, SET_PROPERTY, SET_VISIBLE, CREATE_PAGE, SWITCH_PAGE |
| 0x20-0x24 | Runtime data | METER_BATCH, SET_VALUE, SET_TEXT, SET_STATE, SET_COLOR |
| 0x30-0x32 | Touch (ESP32 to Teensy) | TOUCH_DOWN, TOUCH_UP, TOUCH_DRAG |
| 0x40-0x41 | Update | ENTER_BOOTLOADER, UPDATE_PROGRESS |

METER_BATCH: 24 meters x 6 bytes = 144 bytes/frame at 30 Hz = ~4.6 KB/s.

## SD Card Update Flow

1. User copies `/UPDATE/` folder (manifest.json, teensy.hex, display.bin, ui.json) to SD card
2. Teensy boots, detects manifest, verifies device ID + checksums
3. Teensy self-updates via FlasherX (writes upper flash first, vector table last)
4. Teensy reflashes ESP32 via esp-serial-flasher (GPIO0 LOW + EN pulse + UART stream, ~16s)
5. Copies ui.json to `/SYSTEM/ui.json`, renames `/UPDATE/` to `/UPDATE_DONE/`
6. Normal boot resumes

## Files Changed

| File | Change |
|---|---|
| `docs/pin-mapping.md` | Pins 9/10 assigned, spare count 11 to 9 |
| `hardware/pcbs/main/connections.md` | Display header 4-pin to 6-pin |
| `hardware/pcbs/main/architecture.md` | Added ESP32 reflash circuit section, updated GPIO table |
| `docs/firmware.md` | Added FlasherX, esp-serial-flasher, display engine protocol, SD update boot sequence |
| `docs/ui-architecture.md` | Added display engine architecture, widget types, ui.json format |
| `docs/features.md` | Added SD card update feature, updated display section |
| `docs/hardware.md` | Updated display module BOM entry (6-pin header) |
| `docs/system-topology.md` | Updated connector summary (display 4 to 6 pin) |
| `docs/usb-audio.md` | Updated stale pin 9/10 spare references |
| `CLAUDE.md` | Updated architecture summary, libraries, cross-references |

## New Files

| File | Content |
|---|---|
| `docs/display-engine.md` | Full protocol spec: COBS framing, command set, widget types, property keys, error handling |
| `docs/sd-update.md` | Update mechanism: package format, manifest, boot sequence, FlasherX, esp-serial-flasher, error handling |

## Risks

| Risk | Mitigation |
|---|---|
| ESP32 module doesn't expose EN/GPIO0 | Verify before module selection (Waveshare 4.3" does expose these) |
| Power loss during FlasherX | Upper-flash-first write + HalfKay ROM = always USB-recoverable |
| ESP32 reflash too slow | 921600 baud = ~16s for 1.5 MB; NeoPixel progress indicator |
| ui.json parse slows boot | ~5 ms parse + ~200 ms UART stream = <500 ms total |

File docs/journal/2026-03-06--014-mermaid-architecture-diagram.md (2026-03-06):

# 014 - Mermaid Hardware Architecture Diagram

**Date:** 2026-03-06

## Summary

Created a comprehensive Mermaid flowchart diagram at `docs/architecture-diagram.md` showing the full MIXTEE hardware architecture. Consolidated nodes to reduce horizontal spread.

## What was done

- Single Mermaid `graph TB` diagram covering all 7 board types + off-the-shelf modules
- Two top-level subgraphs: Digital Domain (GND) and Analog Domain (GND_ISO)
- Galvanic isolation boundary clearly shown via red-bordered Si8662BB, ISO1541, MEJ2S0505SC nodes
- Signal paths differentiated by line style: thick (TDM audio), solid (control/data), dotted (power)
- Node color-coding: blue (digital), green (analog), red (isolation), yellow (power)
- Signal path summary section for quick reference

### Node consolidation (width fix)

Merged related items into multi-line nodes to reduce horizontal pressure:

| Area | Before | After |
|---|---|---|
| IO Board | 6 nodes (FE1.1s, USB-A, RJ45, 6N138, TPS2051, MIDI jacks) | 3 nodes (USB_HOST, MIDI, RJ45) |
| Key PCB | 3 nodes (MCP23017, NeoPixels, CHOC) | 1 node (KEY_CONTENTS) |
| Daughters | 4 nodes (1-bot, 2-bot, O-top, O-bot) | 2 nodes (D_IN, D_OUT) |
| HP Board | 3 nodes (amp, pot, jack) | 1 node (HP_BOARD) |
| Main Board | 8 nodes + ISO block | 5 nodes + ISO block (SD/LDO/Latch/USB-C merged into MAIN_IO) |
| Mother boards | MCP23008 + TS5A3159 separate | merged into single MCP23008 node |
| Loose nodes | ESP32, encoders, PWR_BTN floating | grouped in PERIPHERALS subgraph |

Total nodes reduced from ~37 to ~24.

## File modified

- `docs/architecture-diagram.md`

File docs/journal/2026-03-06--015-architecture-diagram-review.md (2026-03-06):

# Architecture Diagram Review & Corrections

**Date:** 2026-03-06
**Scope:** `docs/architecture-diagram.md`
**Source docs cross-referenced:** All board `connections.md` files, `main/connections.md` (XMOS section)

## Correctness Fixes

| # | Issue | Before | After |
|---|---|---|---|
| 1 | HP Board connection source | `MCP23008 -- "HP audio" --> HP_BOARD` | `TS5A -- "4-pin JST-PH" --> HP_BOARD` |
| 2 | TS5A3159 missing as node | Audio routed through MCP23008 (I2C expander) | Separate `TS5A` node; MCP23008 sends GPIO control, TS5A carries audio |
| 3 | 10-pin output cable unlabeled | `MCP23008 -- "unmuted out" --> D_OUT` | `TS5A -- "10-pin JST-PH\n8ch post-mute" --> D_OUT` |
| 4 | Key PCB cable split into two lines | Separate `I2C 0x20` and `NeoPixel pin 6` lines | Single `6-pin JST-PH\nI2C + NeoPixel + INT + 5V` line |
| 5 | IO Board cable topology | Individual signal lines (ETH, USB, MIDI) direct to components | `12-pin FFC` to IO subgraph + separate `6-pin ribbon` for ETH diff pairs |
| 6 | HP detect return missing | No return path shown | `HP_BOARD -. "HP detect\nvia 4-pin cable" .-> MCP23008` |

## Completeness Improvements

| # | Addition |
|---|---|
| 7 | MCP23008 address label: `0x21` (was embedded in mute text) |
| 8 | Board 2-top labeled `(input only, output DNP)` |
| 9 | TCA9548A channel labels: Ch 0 / Ch 1 (already present, kept) |
| 10 | TDM tap label: `9-signal TDM tap\n(pre-isolator, high-Z)` |
| 11 | XMOS return audio: `Return audio (8ch)\nTBD: pin 9 SAI1_RX_DATA2?` |
| 12 | BCLK frequency on TDM lines: `BCLK 24.576 MHz` |
| 13 | D_IN/D_OUT clarified: `Input Daughters` / `Output Boards` |

## Legend Update

- Dotted line meaning expanded: "Power distribution, passive connections, detect signals"
- MCP23008 GPIO mute control now uses dotted line (control, not audio)

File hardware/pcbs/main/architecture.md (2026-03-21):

# Main Board — Architecture

---

## Power

Soft-latch circuit, load switch, rail distribution (5V_DIG / 5V_ISO), protection, and power sequencing are documented in **[Power System](../../docs/power.md)**.

---

## TCA9548A I2C Mux

- Address **0x70** on main I2C bus (Wire, pins 18/19)
- Isolates each Input Mother Board onto its own channel:
  - **Ch 0** → FFC to Board 1-top (U1 @ 0x10, U2 @ 0x11)
  - **Ch 1** → FFC to Board 2-top (U3 @ 0x10, U4 @ 0x11)
- Resolves AK4619VN 2-address limitation
- MCP23017 (0x20, Keys4x4 PCB) sits upstream — always accessible
- External pull-ups: 4.7k ohm to 3.3V upstream of mux

---

## Galvanic Isolation (Digital ↔ Analog Domain Boundary)

The FFC cables to the Input Mother Boards are the **galvanic isolation boundary**. No shared copper exists between the digital domain (Main Board) and the analog domain (Mother Boards, Daughter/Output Boards, PHONEE). All isolation components sit on the Main Board side, near each FFC connector.

### Per-FFC Isolation Set (×2 — one per TDM bus)

| Component | Function | Key Spec |
|---|---|---|
| **Murata MEJ2S0505SC** | Isolated DC-DC 5V→5V_ISO | 2W (400 mA), 5.2 kV isolation, SIP-7 TH |
| **Si8662BB-B-IS1** | 6-channel digital isolator (TDM) | 150 Mbps, 4 forward + 2 reverse, SOIC-16W |
| **ISO1541DR** | Isolated bidirectional I2C | 1 MHz, SOIC-8 |

### Si8662BB Channel Assignment

| Channel | Direction | Signal |
|---|---|---|
| A (fwd) | Main→Analog | MCLK |
| B (fwd) | Main→Analog | BCLK |
| C (fwd) | Main→Analog | LRCLK |
| D (fwd) | Main→Analog | TDM TX_DATA (Teensy→codec SDIN) |
| E (rev) | Analog→Main | TDM RX_DATA0 (codec 1 SDOUT) |
| F (rev) | Analog→Main | TDM RX_DATA1 (codec 2 SDOUT) |

### Timing

BCLK = 24.576 MHz → 40.7 ns period, 20.3 ns half-period. Si8662BB propagation = ~7.5 ns typical. Round-trip (BCLK out + SDOUT back) = ~15 ns + codec internal delay (~10 ns) = ~25 ns. Valid within the 40.7 ns BCLK period. The BB (high-speed) grade is mandatory.

### ISO1541 I2C Isolation

Bidirectional I2C isolator on SDA/SCL lines. Connects between TCA9548A mux output (per-channel) and the FFC. Supports 1 MHz — adequate for AK4619VN and MCP23008 I2C traffic.

### MEJ2S0505SC Isolated Power

5V system rail → 5V_ISO (isolated output). 400 mA capacity per converter. Board 1-top fully populated draws ~200 mA (2× codecs 40 mA + 12× op-amps 60 mA + ADP7118 + MCP23008 + 4× TS5A3159 + HP amp ~50 mA) — provides 2× margin.

### GND_ISO

GND_ISO exists on the Main Board only as small copper islands around isolator Side 2 output pins and FFC pads. **≥1 mm clearance** between GND and GND_ISO copper on all layers. Keep MEJ2S0505SC (switching DC-DC) physically separated from Si8662BB signal pins to minimize switching noise coupling.

---

## ESP32-S3 Reflash Circuit

Teensy pins 9 and 10 provide hardware control over the ESP32-S3 display module's boot mode, enabling firmware updates from SD card without user intervention.

### Circuit

| Teensy Pin | Signal | Connection | Notes |
|---|---|---|---|
| 9 | ESP32_EN | Module EN pin | Active-high enable (module has internal pull-up). Teensy drives LOW to hold reset, releases (HIGH-Z or HIGH) to boot. |
| 10 | ESP32_GPIO0 | Module GPIO0/BOOT pin | Drive LOW before EN release → UART bootloader mode. Leave HIGH/float → normal app boot. |

### Reflash Sequence (triggered by SD card update)

1. Teensy asserts ESP32_GPIO0 LOW (pin 10)
2. Teensy pulses ESP32_EN LOW for ~100 ms, then releases (pin 9)
3. ESP32-S3 boots into UART download mode
4. Teensy streams `display.bin` via Serial1 at 921600 baud using `esp-serial-flasher` library
5. Flash time: ~16 seconds for 1.5 MB binary
6. Teensy releases ESP32_GPIO0 (HIGH-Z), pulses ESP32_EN to reboot into normal app mode
7. Normal display engine handshake resumes

### Header Change

Display header expanded from 4-pin to 6-pin JST-PH to carry ESP32_EN and ESP32_GPIO0 signals. See [connections.md](connections.md#esp32-s3-display-header-6-pin).

---

## TS5A3159 Pop Suppression — Moved to Input Mother Board

The 4× TS5A3159 analog mute switches have been **moved to Board 1-top** (Input Mother Board, TDM1) to keep the entire analog output signal path within the isolated domain. They are controlled via a **MCP23008 I2C GPIO expander** (address 0x21) on Board 1-top, accessed through the already-isolated I2C bus. Board 2-top (input-only) does not populate the MCP23008/TS5A3159 section.

**Freed Teensy GPIO pins:** 30, 35, 37, 38, 39 (5 pins returned to spare pool — 4 mute + 1 headphone detect via MCP23008).

See [Input Mother Board architecture](../input-mother/architecture.md) for TS5A3159 and MCP23008 details.

---

## Teensy Pin Assignments

### Peripheral pins (fixed)

- **SAI1 (TDM1):** pins 7, 8, 20, 21, 23, 32
- **SAI2 (TDM2):** pins 2, 3, 4, 5, 33 (bottom), 34 (bottom)
- **SPI0:** pins 11, 12, 13 *(spare — XMOS removed)*; pin 10 reassigned to ESP32_GPIO0
- **I2C (Wire):** pins 18, 19
- **Serial3 RX (MIDI IN):** pin 15
- **Serial4 TX (MIDI OUT):** pin 17
- **SDIO (SD card):** bottom pads 42–47
- **USB Host:** bottom pads (D+, D-, VBUS, GND)
- **Ethernet:** bottom pads (TX+/-, RX+/-, LED, GND)

### GPIO assignments

| Pin | Function |
|-----|---|
| 0, 1 | Serial1 — ESP32-S3 display UART |
| 6 | NeoPixel data out |
| 9 | ESP32_EN (display reset) |
| 10 | ESP32_GPIO0 (display boot mode) |
| 14 | *(spare — was RA8875 RESET)* |
| 16 | *(spare — was Encoder 3 Edit push, moved to DESPEE)* |
| 22 | MCP23017 INT |
| 24, 25, 28 | *(spare — was Encoder 1 NavX A/B/push, moved to DESPEE)* |
| 26, 27 | *(spare — was Encoder 3 Edit A/B, moved to DESPEE)* |
| 29, 31, 36 | *(spare — was Encoder 2 NavY A/B/push, moved to DESPEE)* |
| 30 | *(spare — was TS5A3159 mute, moved to isolated domain)* |
| 35 | *(spare — was TS5A3159 mute AUX1, bottom pad)* |
| 37 | *(spare — was TS5A3159 mute AUX2)* |
| 38 | *(spare — was TS5A3159 mute AUX3)* |
| 39 | *(spare — was headphone detect, now via MCP23008 on Board 1-top)* |
| 40 | Power button sense |
| 41 | KEEP_ALIVE |

**Total edge pins:** 42. **Consumed by peripherals:** 18 (SAI ×12, I2C ×2, Serial1/ESP32 ×2, Serial3 RX ×1, Serial4 TX ×1). **GPIO:** 6 used (4 original + 2 ESP32 boot control), 18 spare (pins 11, 12, 13, 14, 16, 24, 25, 26, 27, 28, 29, 30, 31, 35, 36, 37, 38, 39). Encoders moved to DESPEE display module — ESP32-S3 reads them locally via GPIO.

---

[Back to README](README.md)

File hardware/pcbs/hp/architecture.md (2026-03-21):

# PHONEE — Architecture

*← Back to [README](README.md)*

------

## Headphone Amplifier

- **TPA6132A2** (TI, SOT-23-8) — ground-referenced stereo headphone driver
- Capless output — no AC coupling caps needed on jack
- 25 mW into 32 Ω, 0.01% THD+N typical
- Single 3.3–5V supply (from 5V_ISO via input cable)
- Output through PCB-mount 10kΩ log pot (volume) to headphone TRS jack

### BOM (amp section)

| Part | Quantity | Package | Notes |
|---|---|---|---|
| TPA6132A2 | 1 | SOT-23-8 | ~$1.50 |
| 10kΩ log pot (A10K) | 1 | PCB-mount | Volume control |
| 1/4" TRS jack (w/ detect) | 1 | Panel-mount TH | Switchcraft 35RASMT2BHNTRX or equiv |
| 0.1µF ceramic cap | 2 | 0402/0603 | Decoupling |
| 1µF ceramic cap | 2 | 0402/0603 | Input coupling |
| 10µF ceramic cap | 1 | 0805 | Bulk decoupling |

------

## Power

- **Input:** 5V_ISO via 4-pin JST-PH cable pin 3
- **Ground:** GND_ISO — entire board on isolated ground, no connection to system GND
- **Consumption:** ~30 mA (TPA6132A2 + minimal passives)
- Decoupling: 10 µF + 0.1 µF ceramic near IC power input

------

## Headphone Detect

The TRS jack includes a detect switch (normally closed to GND_ISO, open when plug inserted). In MIXTEE, the detect signal is routed back to Board 1-top where it connects to **MCP23008 GP6** (I2C GPIO expander at address 0x21). Teensy reads the detect state via I2C polling (~100 Hz).

This eliminates the need for a dedicated Teensy GPIO pin (pin 39 freed) and avoids routing a detect signal across the isolation barrier. Other devices using PHONEE can route the detect signal as needed.

------

## Design Notes

- 2-layer PCB, minimal routing
- Entire ground plane is GND_ISO (in MIXTEE; other devices may use system GND)
- No high-speed digital signals on this board
- Mounting: panel-mount via headphone jack nut + pot nut (both protrude through enclosure panel)
- Keep analog signal traces short — TPA6132A2 placed near input connector

------

[Back to README](README.md)

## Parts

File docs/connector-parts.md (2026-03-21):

# MIXTEE: Connector Part Numbers

*← Back to [README](../README.md) | See also: [System Topology](system-topology.md) · [Hardware](hardware.md)*

------

## MPN Index

Quick reference for connector part numbers across all boards. For detailed pinouts and usage, see each board's `connections.md`.

| Part | MPN | Manufacturer | Board(s) | Notes |
|---|-----|---|---|---|
| USB-C (PC) | USB4105-GF-A | GCT | Main | Data only, mid-mount SMD |
| USB-A dual stacked | 67298-4090 | Amphenol | IO | 2× MIDI host ports |
| FFC 20-pin ZIF | TBD (Molex 502586 series, 20-pin) | Molex | Main (×2), Input Mother (×2) | 1.0mm pitch, bottom-contact; galvanic isolation boundary |
| FFC 12-pin ZIF | TBD (Molex 502586 series) | Molex | Main, IO | 1.0mm pitch, bottom-contact |
| JST-PH 6-pin | B6B-PH-K-S | JST | Main, Keys4x4, Mother/Daughter | 2.0mm pitch, through-hole |
| JST-PH 10-pin | B10B-PH-K-S | JST | Input Mother (1-top), Daughter-Output (O-top) | Output analog cable |
| 1/4" TS jack | 112BPC | Switchcraft | Input Mother, Daughter-Output | 24× total (16 in + 8 out) |
| 1/4" TRS jack (HP) | 35RASMT2BHNTRX | Switchcraft | HP | Stereo headphone, detect switch |
| 3.5mm TRS (MIDI) | SJ-3523-SMT | CUI Devices | IO | MIDI IN + MIDI OUT Type A |
| RJ45 MagJack | TBD | TBD | IO | 10/100 Ethernet, integrated magnetics |
| 6-pin header (ETH) | TBD | TBD | Main, IO | 2.54mm, Ethernet ribbon |
| JST-PH 4-pin (HP cable) | B4B-PH-K-S | JST | Input Mother (1-top), HP | HP amp signal + power cable |
| SD card socket | 472192001 | Molex | Main | Full-size, panel-mount |
| Rotary encoder | PEC11R-4215F-S0024 | Bourns | DESPEE (×3) | 24 detents, push switch; mounted on DESPEE display PCB (moved from Main Board) |
| Power button | TBD | TBD | Back panel | Screw-collar momentary |
| CHOC hotswap | CPG135001S30 | Kailh | Keys4x4 (×16) | CHOC v1/v2 compatible |

## Cable Assemblies

| Cable | Type | Pins | Length |
|---|---|---|---|
| Main ↔ Input Mother (×2) | FFC 1.0mm | 20 | 40–50mm |
| Main ↔ IO Board | FFC 1.0mm | 12 | 100–120mm |
| Ethernet ribbon | 6-pin 2.54mm | 6 | ~100mm |
| Mother ↔ Daughter (×3) | JST-PH harness | 6 | 15–20mm |
| 1-top → O-top | JST-PH harness | 10 | ~80mm |
| Main ↔ Keys4x4 PCB | JST-PH harness | 6 | 30–40mm |
| 1-top → PHONEE | JST-PH harness | 4 | 40–60mm |

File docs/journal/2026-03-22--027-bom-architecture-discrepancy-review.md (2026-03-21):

# 027 — BOM architecture discrepancy review

**Date:** 2026-03-22
**Scope:** `hardware/bom.csv`, `docs/hardware.md`, board architecture docs

## Summary

Cross-referenced `hardware/bom.csv`, the markdown BOM tables in `docs/hardware.md`, and all per-board `architecture.md` files. Found 10 discrepancies — fixed 5 in code, deferred 2 to GitHub issues, resolved 3 by removing redundant tables. Key design change: moved the 2.5V virtual ground buffer from the Main Board to the Input Mother Boards, since it can't cross the galvanic isolation boundary.

## What changed

| Change | Files |
|---|---|
| Move virtual ground buffer to Input Mother Boards; remove Main Board ADP7118 LDO | `hardware/bom.csv`, `docs/hardware.md`, `hardware/pcbs/main/architecture.md`, `hardware/pcbs/main/README.md`, `hardware/pcbs/input-mother/architecture.md`, `hardware/pcbs/input-mother/ak4619-wiring.md`, `docs/system-topology.md`, `docs/architecture-diagram.md` |
| Correct OPA1678 count: 17/16 → 26 (Board 1-top: 17, Board 2-top: 9) | `hardware/bom.csv`, `docs/hardware.md` |
| ADP7118 count: 3 → 2; precision resistors: 2 → 4 | `hardware/bom.csv`, `docs/hardware.md` |
| Add missing MIDI IN jack | `docs/hardware.md` |
| Remove Ethernet coupling caps (MagJack has integrated magnetics) | `hardware/bom.csv`, `docs/hardware.md`, `hardware/pcbs/io/architecture.md`, `hardware/pcbs/io/connections.md` |
| Split Power & Connectivity into separate sections | `docs/hardware.md` |
| Replace duplicate BOM tables with pointer to `hardware/bom.csv` | `docs/hardware.md` |
| List PHONEE and DESPEE as external modules, not individual components | `hardware/bom.csv` |
| Schottky diodes 25 → 24 (HP jack ESD now in PHONEE BOM) | `hardware/bom.csv` |

## Deferred

- **Polyfuse location** (Main Board vs Power Board): [openaudiotools/about#17](https://github.com/openaudiotools/about/issues/17)
- **Power budget math** (line items don't sum to stated totals): [openaudiotools/about#18](https://github.com/openaudiotools/about/issues/18)

## Context

The virtual ground buffer was documented on the Main Board so it could serve both Input Mother Boards from one location. However, the mother boards are in the galvanically isolated analog domain — no analog signal can cross the FFC isolation boundary. Each mother board now generates its own 2.5V reference locally using a precision resistor divider + one OPA1678 section, powered by its existing ADP7118 LDO. This eliminated the Main Board's ADP7118 instance entirely.

The duplicate BOM tables in `docs/hardware.md` were a recurring source of drift (counts, categories, missing items). Replaced with a single pointer to `hardware/bom.csv` as the canonical source, with per-board details in each board's `architecture.md`.

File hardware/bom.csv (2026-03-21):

Category | Part | Quantity | Package | Alternate | Unit Cost (USD) Est. | Total Cost (USD) Est. | Notes
Core Processing | Teensy 4.1 | 1 | Module |  | 30.00 | 30.00 | ARM Cortex-M7 @ 600 MHz; USB host; 2x TDM/I2S; built-in SD slot (SDIO)
Core Processing | PSRAM 8 MB (QSPI) | 1 | QSPI BGA |  | 4.00 | 4.00 | IPS6404LSQ or APS6404L; solder to Teensy 4.1 bottom QSPI pads; multitrack recording buffer
Core Processing | AK4619VN | 4 | QFN-32 (5x5mm 0.5mm pitch) |  | 20.00-30.00 | 80.00-120.00 | 4-in/4-out audio codec; U1-U2 full (ADC+DAC); U3-U4 ADC only; I2C control; TDM audio
UI Components | DESPEE display module (4.3 inch) | 1 | Module |  | 15.00-20.00 | 15.00-20.00 | openaudiotools/despee — external module (ESP32-S3-WROOM-1-N16R8 + bare 800x480 LCD + 3x encoders); 6-pin JST-PH UART link to Teensy; own BOM in despee repo
UI Components | Custom key PCB | 1-2 | PCB |  | 5.00-10.00 | 5.00-10.00 | CHOC hotswap sockets + WS2812B-2020 + MCP23017 + 100nF caps; 4x4 grid
UI Components | Kailh CHOC hotswap sockets | 16 | SMD |  | 0.30 | 4.80 | Soldered to custom key PCB
UI Components | WS2812B-2020 NeoPixels | 16 | SMD |  | 0.25 | 4.00 | Daisy-chained DOUT-DIN; single data pin; per-key RGB LED
UI Components | 100nF ceramic cap (key LEDs) | 16 | 0402/0603 |  | 0.02 | 0.32 | Decoupling per WS2812B
UI Components | MCP23017 I2C GPIO expander | 1 | SOIC-28 / DIP-28 |  | 1.50 | 1.50 | 4x4 key scan matrix; on Keys4x4 PCB; address 0x20
UI Components | CHOC v2 key switches | 16 | Through-hole |  | 1.00 | 16.00 | User-supplied or included; hotswap into custom PCB
Power & Connectivity | TCA9548A I2C mux | 1 | TSSOP-24 |  | 1.50 | 1.50 | I2C bus switch; isolates codec boards; address 0x70
Power & Connectivity | STUSB4500 breakout module (off-the-shelf) | 1 | Module |  | 10.00-15.00 | 10.00-15.00 | SparkFun PD Board or equivalent; USB-C PWR input; back panel; NVM configured for 5V only
Power & Connectivity | FE1.1s USB 2.0 hub IC | 1 | SSOP-28 |  | 1.50 | 1.50 | IO Board; upstream via FFC from Teensy USB host; 2 downstream to USB-A
Power & Connectivity | 12 MHz crystal | 1 | HC49/SMD |  | 0.50 | 0.50 | IO Board; FE1.1s clock source; 15 pF load capacitors
Power & Connectivity | TPS2051 power switch | 2 | SOT-23-5 |  | 1.50 | 3.00 | IO Board; USB host port per-port VBUS current limiting (500 mA each)
Power & Connectivity | USB-A dual stacked socket | 1 | Through-hole (Amphenol 67298-4090) |  | 4.00 | 4.00 | IO Board; 2x USB-A host ports for MIDI controllers; top panel
Power & Connectivity | 3.5mm TRS jack (MIDI IN) | 1 | SMD (CUI SJ-3523-SMT) |  | 1.50 | 1.50 | IO Board; MIDI IN Type A (Tip=sink Ring=source Sleeve=shield); top panel
Power & Connectivity | FFC 20-pin ZIF connector (Main-Mother) | 4 | SMD 1.0mm pitch |  | 0.60 | 2.40 | Main Board (x2) + Input Mother Board (x2); 20-pin 1.0mm FFC for galvanically isolated interconnect
Power & Connectivity | FFC 20-pin cable (Main-Mother) | 2 | 1.0mm pitch 40-50mm |  | 0.60 | 1.20 | Main to Input Mother Board interconnect cables (x2)
Power & Connectivity | FFC 12-pin ZIF connector (Main-IO) | 2 | SMD 1.0mm pitch |  | 0.50 | 1.00 | Main Board (x1) + IO Board (x1); 12-pin 1.0mm FFC for Main-IO interconnect
Power & Connectivity | FFC 12-pin cable (Main-IO) | 1 | 1.0mm pitch 100-120mm |  | 0.50 | 0.50 | Main to IO Board interconnect cable
Power & Connectivity | RJ45 MagJack (integrated magnetics) | 1 | Through-hole panel-mount |  | 3.00-5.00 | 3.00-5.00 | IO Board; Ethernet 10/100 Mbps; integrated transformer + LEDs; top panel
Power & Connectivity | 6-pin header (Ethernet ribbon) | 2 | Through-hole 2.54mm pitch |  | 0.30 | 0.60 | Main Board + IO Board; carries ETH TX/RX differential pairs
Power & Connectivity | 6-pin ribbon cable (Ethernet) | 1 | 2.54mm pitch ~100mm |  | 0.50 | 0.50 | Main Board to IO Board Ethernet connection
Power & Connectivity | Momentary push button (panel mount screw-collar) | 1 | Panel mount screw-collar |  | 2.00-4.00 | 2.00-4.00 | Back panel; next to PWR USB-C; wired to Main Board soft-latch
Power & Connectivity | Full-size SD card socket | 1 | Through-hole/SMD (Molex 472192001) |  | 2.00-3.00 | 2.00-3.00 | SDIO routed from Teensy bottom pads 42-47; top panel; built-in micro-SD slot unused
Galvanic Isolation | Murata MEJ2S0505SC (isolated DC-DC) | 2 | SIP-7 TH |  | 6.00 | 12.00 | 5V to 5V_ISO; 2W (400 mA); 5.2 kV isolation; 1 per FFC on Main Board
Galvanic Isolation | Si8662BB-B-IS1 (6-ch digital isolator) | 2 | SOIC-16W |  | 4.00 | 8.00 | 150 Mbps; 4 fwd + 2 rev channels; TDM signal isolation; 1 per FFC on Main Board
Galvanic Isolation | ISO1541DR (isolated I2C) | 2 | SOIC-8 |  | 2.50 | 5.00 | Bidirectional I2C isolator; 1 MHz; 1 per FFC on Main Board
Audio I/O & Analog | Switchcraft 112BPC (1/4 inch TS jack) | 24 | PCB-mount through-hole |  | 1.25 | 30.00 | 16 inputs + 8 outputs; 12.7mm mounting hole; back panel
Audio I/O & Analog | PHONEE headphone module | 1 | Module |  | 8.00-12.00 | 8.00-12.00 | openaudiotools/phonee — external module (TPA6132A2 amp + 10k log pot + 1/4 inch TRS jack); 4-pin JST-PH from Board 1-top; own BOM in phonee repo
Audio I/O & Analog | OPA1678 (dual op-amp) | 26 | SOIC-8 |  | 1.20 | 31.20 | Board 1-top: 8 input buffer + 8 anti-alias + 8 reconstruction + 8 line driver + 1 VG buffer = 33 sections (17 ICs); Board 2-top: 8 input buffer + 8 anti-alias + 1 VG buffer = 17 sections (9 ICs); NJM4580 acceptable as budget substitute
Audio I/O & Analog | TS5A3159 analog switch | 4 | SOT-23-5 |  | 1.00 | 4.00 | Pop suppression; SPST per output stereo pair; on Board 1-top (isolated domain); controlled via MCP23008 I2C; low Ron ~1 ohm; 5V tolerant
Audio I/O & Analog | MCP23008 I2C GPIO expander | 1 | SOIC-18 |  | 1.00 | 1.00 | Board 1-top; controls TS5A3159 mute + codec PDN + headphone detect; address 0x21
Audio I/O & Analog | 6N138 optocoupler | 1 | DIP-8 |  | 1.00 | 1.00 | IO Board; MIDI IN galvanic isolation; industry standard at 31.25 kbaud
Audio I/O & Analog | 1N4148 signal diode (MIDI) | 1 | DO-35 / SOD-323 |  | 0.05 | 0.05 | IO Board; MIDI IN optocoupler LED reverse protection
Audio I/O & Analog | Resistor 220 ohm (MIDI IN) | 1 | 0603/0805 |  | 0.01 | 0.01 | IO Board; MIDI IN series current limiting resistor
Audio I/O & Analog | Resistor 470 ohm (MIDI IN pullup) | 1 | 0603/0805 |  | 0.01 | 0.01 | IO Board; 6N138 output pull-up to 3.3V
Power & Connectivity | 3.5mm TRS jack (MIDI OUT) | 1 | SMD (CUI SJ-3523-SMT) |  | 1.50 | 1.50 | IO Board; MIDI OUT Type A (Tip=sink Ring=source Sleeve=shield); top panel
Passives & Protection | Resistor 33 ohm (MIDI OUT) | 1 | 0603/0805 |  | 0.01 | 0.01 | IO Board; MIDI OUT series resistor (Tip to MIDI_TX via FFC)
Passives & Protection | Resistor 10 ohm (MIDI OUT) | 1 | 0603/0805 |  | 0.01 | 0.01 | IO Board; MIDI OUT source resistor (3.3V to Ring)
Power Regulation | ADP7118 LDO | 2 | SOIC-8 |  | 2.50 | 5.00 | 5V_ISO to 3.3V_A ultra-low-noise analog rail; <10 uV RMS; 1 per Input Mother Board
Power Regulation | TPS22965 load switch | 1 | SOT-23-6 / WSON-6 |  | 1.50 | 1.50 | Soft-start / inrush limiting; 5A continuous; controlled slew rate
Power Regulation | 10 mohm shunt resistor | 1 | 2512/2010 |  | 0.30 | 0.30 | Current measurement test point on main 5V rail
Power Regulation | 74LVC1G00 NAND gate | 1 | SOT-23-5 |  | 0.30 | 0.30 | Soft-latch power SR latch; cleaner than 2x BSS138; fewer parts
Power Regulation | Precision resistor 10k 0.1% | 4 | 0603/0805 |  | 0.10 | 0.40 | 2.5V virtual ground resistor divider (1 matched pair per Input Mother Board)
Passives & Protection | Electrolytic capacitor 1000-2200 uF | 2 | Through-hole |  | 0.75 | 1.50 | NeoPixel bulk capacitor + power entry bulk; sized for uncapped LED brightness
Passives & Protection | Ceramic capacitor 0.1 uF | 60 | 0402/0603/0805 |  | 0.02 | 1.20 | Local decoupling everywhere (ICs + op-amps + codec AVDD/DVDD)
Passives & Protection | Ferrite bead | 5 | 0805 |  | 0.15 | 0.75 | Post-isolation filter on each Mother Board (x2) + USB GND + misc
Passives & Protection | Resistor 300-500 ohm | 1 | 0805 |  | 0.02 | 0.02 | NeoPixel data line series resistor (reduces ringing)
Passives & Protection | Polyfuse 2.5A/5A | 1 | Through-hole/SMD |  | 0.50 | 0.50 | Main Board 5V rail input; overcurrent protection (power module may include its own)
Passives & Protection | 1N4148 signal diode (key matrix) | 16 | SOD-323 |  | 0.05 | 0.80 | Anti-ghosting diodes for 4x4 key matrix on Keys4x4 PCB
Passives & Protection | Schottky clamp diodes | 24 | SOD-323/SOT-23 |  | 0.10 | 2.40 | ESD protection on all audio TS jacks (16 input + 8 output); PHONEE headphone jack ESD is in phonee BOM
Passives & Protection | Film capacitors 3.3nF | 24 | 0603/0805 |  | 0.05 | 1.20 | Anti-alias + reconstruction Sallen-Key filters
Passives & Protection | Film capacitors 6.8nF | 24 | 0603/0805 |  | 0.05 | 1.20 | Anti-alias + reconstruction Sallen-Key filters
Passives & Protection | Resistors 1k ohm | 60 | 0603/0805 |  | 0.01 | 0.60 | Filter networks; input voltage dividers; misc
Passives & Protection | Resistors misc values | 20 | 0603/0805 |  | 0.01 | 0.20 | Input attenuation dividers; output series (100 ohm); misc
Passives & Protection | AC coupling caps 10 uF | 16 | 0805/through-hole |  | 0.10 | 1.60 | Input DC blocking (10 uF + 10k = ~1.6 Hz HPF)
Passives & Protection | AC coupling caps 47 uF | 8 | Through-hole |  | 0.15 | 1.20 | Output DC blocking
Passives & Protection | Ceramic capacitor 10 uF (post-isolation filter) | 2 | 0805 |  | 0.10 | 0.20 | Post-MEJ2S0505SC filter on each Mother Board; before ADP7118 LDO input
Passives & Protection | Ceramic capacitor 15 pF | 2 | 0402/0603 |  | 0.02 | 0.04 | IO Board; FE1.1s crystal load capacitors
Passives & Protection | Soft-latch passives (R + C misc) | 1 | 0603/0805 |  | 0.50 | 0.50 | Debounce cap; RC timeout network; pull-up/pull-down resistors for latch
Fabrication | PCB fabrication (prototype) | 1 |  |  | 35.00-70.00 | 35.00-70.00 | Main (4L) + IO (2L) + input mother (4L) + daughter/output (2L) + keys4x4 (2L); prototype qty; PHONEE + DESPEE + power module are external/off-the-shelf
Fabrication | Enclosure (DIY/3D print or kit) | 1 |  |  | 20.00-50.00 | 20.00-50.00 | 260x100x50 mm (WxDxH)
User Supplied | SD card (UHS-I U3 / V30) | 1 | Full-size SD |  | 8.00-15.00 |  | User-supplied; 32-64 GB recommended; pre-format 64 KB clusters

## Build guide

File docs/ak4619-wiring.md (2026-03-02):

# AK4619VN Codec Wiring

This document has moved to the Input Mother Board directory:

**[hardware/pcbs/input-mother/ak4619-wiring.md](../hardware/pcbs/input-mother/ak4619-wiring.md)**

The codec wiring reference is board-specific to the Input Mother Board. All pin tables, I2C addressing, TDM interface details, register initialization, and per-codec connection tables are in the linked file.

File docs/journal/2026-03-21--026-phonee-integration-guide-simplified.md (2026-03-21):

# 026 — PHONEE integration guide simplified

**Date:** 2026-03-21
**Scope:** `d:\projects\openaudiotools\phonee\docs\integration-guide.md`

## Summary

Simplified the PHONEE integration guide from a tutorial-style document with three grounding strategy subsections and three detect routing options down to a concise reference. The guide now describes what the connector exposes, what the board expects, and recommends galvanic isolation since PHONEE is an analog signal output stage where ground noise is directly audible. Also removed the `hardware/` directory from the phonee repo (no PCB files yet — docs only for now).

## What changed

| File | Change |
|---|---|
| `phonee/docs/integration-guide.md` | Replaced ~150-line tutorial with ~60-line reference: input connector table, detect switch behavior, isolation recommendation, mechanical notes, MIXTEE example |
| `phonee/hardware/` | Removed (premature — no KiCad files yet; BOM table already in `docs/architecture.md`) |
| `phonee/README.md` | Removed BOM link (pointed to deleted `hardware/bom.csv`) |

## Context

The original guide enumerated grounding strategies (shared, star, isolated) and detect routing options (GPIO, I2C expander, ignore) as if teaching PCB design. The user's feedback was clear: just describe the interface and recommend isolation. Host-specific integration details belong in the host project's docs (e.g., MIXTEE's `hardware/pcbs/hp/`), not in PHONEE's canonical repo.

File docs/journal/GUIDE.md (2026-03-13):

## Journal

This project maintains a development journal in `docs/journal/`.
Entries are named `YYYY-MM-DD--NNN-description.md` (e.g., `2026-03-13--004-fix-plugin-installation.md`).

### Commands

| Command | What it does |
|---|---|
| `/journal` | Write a new entry — title is auto-generated from the conversation |
| `/journal <title>` | Write a new entry with an explicit title |
| `/journal search <query>` | Search entries by filename and content |
| `/journal last [N]` | Show the last N entries (default 1) |
| `/journal check` | Find entries relevant to the current conversation |
| `/journal init` | Set up the journal directory and CLAUDE.md @import |
| `/journal help` | Print command reference |

### When to use the journal

- **Before starting work:** Run `/journal check` to surface past decisions relevant to the files or topics you're about to touch.
- **Before architectural decisions:** Run `/journal search <topic>` to see if the topic was discussed before.
- **After completing work:** Run `/journal` to capture what was done and why.

### Examples

```
/journal                          # auto-title from conversation
/journal Switched to monorepo     # explicit title
/journal search auth              # find past auth decisions
/journal last 3                   # review last 3 entries
/journal check                    # what's relevant right now?
```

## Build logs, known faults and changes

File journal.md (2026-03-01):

# MIXTEE Development Journal

## 2026-03-01 — Daughter/Output Board Trace Routing

### What was done
Added programmatic trace routing to `hardware/kicad/gen_daughter_output.py`. The board has 6 nets (AIN1–4, +5VA, GND) across 10 components on an 80×20mm 2-layer PCB.

### Routing strategy
- **AIN1**: All F.Cu — L-route from J1 to J2.T, vertical down to D1.K
- **AIN2–4**: F.Cu stub from J1 → via → B.Cu hop → via → F.Cu fan-out to jack T pad and diode K pad
- **+5VA**: F.Cu L-route from J1 to C1
- **GND**: Short F.Cu stubs from SMD diode/cap pads to vias connecting to B.Cu ground zone

Helper functions added: `trace_seg()` and `via_pad()` for generating KiCad S-expression segments and vias.

### Bugs found and fixed

**1. J1 rotation convention (rotation=90 → 270)**

KiCad uses **clockwise** rotation for positive angles in PCB coordinates. With `rotation=90`, J1's pins were mirrored — pin 1 (AIN1) ended up at y=115 (bottom) instead of y=105 (top). Every trace shorted to the wrong J1 pin.

Fix: changed J1 rotation from 90° to 270°. With 270°, the pin-to-absolute transform is `(px, py) → (-py, px)` giving pin 1 at (104, 105) as intended.

**2. Jack S pads extending beyond board edge (jack_y 104 → 106)**

With jacks at y=104, the top S pads (at relative `(0, -3)`) had centers at y=101 — their 3mm diameter circles extended 0.5mm above the board edge (y=100). DRC flagged board-edge clearance violations.

Fix: moved jacks from `jack_y = oy + 4.0` to `oy + 6.0`. Top S pad centers now at y=103, fully inside the board with 1.5mm margin. All trace coordinates updated to match.

### Current state
- Signal traces and vias: all 6 nets routed, 0 unconnected after zone fill
- Remaining DRC items: 2 shorting violations (AIN1 trace at y=106 passes through J2.S pad at (108.92, 106); AIN2 B.Cu hop at y=107 passes near J3.S pad) — need to reroute AIN1 horizontal and AIN2 B.Cu to avoid jack S pad areas
- GND vias flagged as "dangling" because `kicad-cli` DRC doesn't fill zones — these resolve when zones are filled in KiCad GUI
- lib_footprint_mismatch warnings are expected (our simplified footprints vs full KiCad library)

### Next steps
- ~~Fix AIN1 horizontal trace to avoid J2.S pad~~ → resolved via FreeRouting (see 2026-03-02)
- ~~Fix AIN2 B.Cu hop to avoid J3.S pad~~ → resolved via FreeRouting
- ~~Verify clean DRC (0 errors) after fixes~~ → done
- Consider adding silkscreen labels and courtyard outlines to custom footprints

---

## 2026-03-02 — Daughter/Output Board: FreeRouting Autoroute + Gerber Export

### What was done
Scrapped the manual trace routing from gen_pcb.py (which had 2 shorting errors at jack S pads) and replaced it with a FreeRouting autoroute via Specctra DSN/SES round-trip. Fixed silkscreen clipping DRC warnings in the process. Board is now fully routed and Gerbers are exported.

### Pipeline used

1. **Silkscreen fix** — Custom `Switchcraft_112BPC` footprint silk rectangle extended past all 4 board edges when jacks were placed at y=20 with 90° rotation. Clipped from `(-4, -6.35)→(22, 10)` to `(0.5, -6.35)→(19.5, 9.5)` in both the `.kicad_mod` library file and all 4 inline instances in the `.kicad_pcb`. Also moved board title text from y=22 to y=18.5.

2. **DSN export** — Used KiCad's pcbnew Python API (`pcbnew.ExportSpecctraDSN()`) since `kicad-cli` doesn't support DSN export. Patched the DSN to split the single `kicad_default` net class into three classes matching the project settings:
   - `Audio_Analog` (AIN1-4): 0.3mm width, 0.25mm clearance
   - `Power` (+5VA): 0.5mm width
   - `kicad_default` (GND): 0.25mm width

3. **FreeRouting** — Loaded DSN, ran autoroute, exported SES. FreeRouting produced 44 trace segments using both F.Cu and B.Cu with vias, correctly respecting net class widths.

4. **SES import** — `pcbnew.ImportSpecctraSES()` to bring routes back into the PCB.

5. **Post-routing validation** — Opened project via kicadmixelpixx MCP (`open_project`), refilled GND zone (`refill_zones`), saved (`save_project`), verified components (`get_component_list`), queried traces (`query_traces`). DRC via kicad-cli: **0 errors, 0 unconnected, 26 cosmetic warnings**.

6. **Gerber export** — `kicad-cli pcb export gerbers` + `pcb export drill`. 7 Gerber layers + drill + job file in `gerbers/`.

### Tooling notes

- **kicadmixelpixx MCP (SWIG backend)**: works well for `open_project`, `get_component_list`, `refill_zones`, `save_project`, `query_traces`. DRC and Gerber export tools wrap `kicad-cli` and fail if it's not on PATH. `get_board_2d_view` needs Cairo DLL.
- **kicad-cli** (at `D:\programs\KiCad\9.0\bin\kicad-cli.exe`): not on PATH by default. Used with full path for DRC and Gerber export. No DSN export subcommand in KiCad 9.
- **pcbnew Python** (at `D:\programs\KiCad\9.0\bin\python.exe`): has `ExportSpecctraDSN()` and `ImportSpecctraSES()` — the only scriptable path for Specctra round-trip.

### DRC breakdown (post-route)

| Type | Count | Notes |
|---|---|---|
| silk_overlap | 10 | Adjacent jack silkscreens + board title text |
| lib_footprint_mismatch | 6 | Generated footprints vs KiCad library |
| silk_edge_clearance | 4 | J2/J3 ref text at board edge, J5 silk past top |
| lib_footprint_issues | 4 | Custom lib path resolution in kicad-cli |
| silk_over_copper | 2 | Silk segments over exposed pads |
| **Errors** | **0** | |
| **Unconnected** | **0** | |

### Files produced
- `hardware/kicad/mixtee-daughter-output/mixtee-daughter-output.dsn` — Specctra DSN with net classes
- `hardware/kicad/mixtee-daughter-output/mixtee-daughter-output.ses` — FreeRouting session
- `hardware/kicad/mixtee-daughter-output/gerbers/` — 7 Gerber + drill + job (9 files)

---

## 2026-03-02 — Key PCB: Design, Route, Gerber Export

### What was done
Created the Key PCB from scratch using `gen_pcb.py` (programmatic KiCad S-expression generator), routed via FreeRouting autoroute, and exported Gerbers. Board is fully routed with 0 errors and 0 unconnected items.

### Board specs
- **Dimensions:** 72 × 80 mm, 2-layer (originally 72×72, extended to 80mm to fit MCP23017 in bottom strip)
- **Components (67):** 16 Kailh CHOC hotswap sockets, 16 WS2812B-2020 NeoPixels, 16 NeoPixel decoupling caps (0603), 16 1N4148 anti-ghosting diodes (SOD-123), 1 MCP23017 GPIO expander (SOIC-28), 1 MCP decoupling cap, 1 JST-PH 6-pin connector
- **Nets (45):** GND, 5V, SDA, SCL, INT, NEO_DIN, NEO_D0–D14, COL0–3, ROW0–3, SW1_D–SW16_D
- **GND zone:** B.Cu full pour

### Layout
- 4×4 switch grid at 18mm pitch, centered in upper 72×72 area
- NeoPixels + caps below each switch center (3.5mm offset)
- Diodes to the right of each switch (rightmost column rotated 90° to avoid board edge)
- MCP23017 (U1) in bottom 8mm strip at (36, 73) rotated 90°
- JST-PH connector (J1) at (5, 75)
- NeoPixel chain: serpentine order [1,2,3,4,8,7,6,5,9,10,11,12,16,15,14,13]

### Pipeline
1. **gen_pcb.py** → generates `.kicad_pcb`, `.kicad_pro`, `fp-lib-table`
2. **pcbnew Python** → `ExportSpecctraDSN()`
3. **DSN patch** → split `kicad_default` into `Default` (0.2mm trace, 0.21mm clearance) and `Power` (0.4mm trace)
4. **FreeRouting** → autoroute (139/139 connections, 8.4 seconds)
5. **pcbnew Python** → `ImportSpecctraSES()`
6. **kicadmixelpixx MCP** → `open_project`, `refill_zones`, `save_project`
7. **kicad-cli** → DRC, Gerber + drill export

### Bugs found and fixed

**1. KiCad pad `(size)` is NOT rotated by footprint rotation**

When MCP23017 was placed at 90° rotation, pads defined as `(size 1.55 0.6)` stayed 1.55mm in board X — but pins were now spaced 1.27mm in board X. Adjacent pads overlapped by 0.28mm (10 shorts, 14 clearance violations, 24 solder mask bridge errors).

Verified via pcbnew Python: `pad.GetBoundingBox()` showed 1.55mm width in board X regardless of footprint rotation. `pad.GetOrientationDegrees()` returned 0° (absolute), not 90°.

Fix: swap pad size to `(size 0.6 1.55)` when footprint rotation is 90°/270°. The `(size)` in `.kicad_pcb` S-expressions is in **board coordinates**, not the footprint's local frame — pad positions `(at)` DO transform with rotation, but `(size)` does NOT.

**2. MCP23017 placement collisions (3 iterations)**

Initially placed U1 at board center (36, 36) — pins overlapped with SW10, D10, C7. Extended board from 72×72 to 72×80mm and moved U1 to bottom strip at (36, 73) rotated 90° (pins along X axis).

**3. LED/cap placement near board edge**

Bottom row LEDs at y=70.5 (switch y=63 + 7.5mm offset) too close to y=72 edge. Reduced LED_OFFSET from (0, 7.5) to (0, 3.5).

**4. FreeRouting clearance rounding**

First FreeRouting run with 0.2mm DSN clearance produced one trace at 0.198mm from SW14 pad (0.002mm under DRC threshold). Bumped DSN clearance to 0.21mm for margin — second run passed cleanly.

### DRC breakdown (post-route)

| Type | Count | Notes |
|---|---|---|
| **Errors** | **0** | (1 starved_thermal on J1 GND, cosmetic) |
| **Unconnected** | **0** | All 139 connections routed |
| text_height | 49 | Generated ref text sizes |
| lib_footprint_mismatch | 35 | Custom vs library footprints |
| lib_footprint_issues | 32 | Custom lib path resolution |
| silk_over_copper | 9 | Silk on exposed pads |
| silk_overlap | 2 | Adjacent component silk |
| silk_edge_clearance | 1 | Edge silk proximity |

### Files produced
- `hardware/kicad/mixtee-key-pcb/gen_pcb.py` — PCB generator script
- `hardware/kicad/mixtee-key-pcb/mixtee-key-pcb.kicad_pcb` — routed PCB
- `hardware/kicad/mixtee-key-pcb/mixtee-key-pcb.kicad_pro` — project file
- `hardware/kicad/mixtee-key-pcb/mixtee-key-pcb.dsn` — Specctra DSN
- `hardware/kicad/mixtee-key-pcb/mixtee-key-pcb.ses` — FreeRouting session
- `hardware/kicad/mixtee-key-pcb/gerbers/` — 29 Gerber layers + drill file

### Next steps
- Add NPTH mounting holes back to CHOC socket footprints (omitted for routing)
- Consider adding courtyard outlines and silkscreen labels to custom footprints
- Review NeoPixel chain signal integrity (serpentine path lengths)

---

## 2026-03-02 — Split Main Board into Main Board + IO Board

### What was done
Architectural split: moved headphone, USB hub (MIDI host), and MIDI I/O circuits from the Main Board onto a new dedicated IO Board. Updated 8 documentation files to reflect the change.

### Motivation
- Main board (~260×85mm) had all processing, power, UI, and IO on one PCB
- IO-facing components (headphone, USB hub, MIDI) are physically clustered in the top panel right column
- Splitting simplifies main board layout, shortens panel-mount wiring, and allows independent revision

### Key design decisions

| Decision | Rationale |
|---|---|
| SD card stays on Main Board (left of display) | Near Teensy SDIO pads, avoids routing high-speed SDIO over FFC |
| PC USB-C stays on Main Board (back panel) | Avoids routing 480 Mbps USB HS over FFC; placed next to PWR USB-C |
| IO Board gets HP amp, USB hub, MIDI only | All USB Full-Speed (12 Mbps) or low-speed serial — FFC-friendly |
| 12-pin 1.0mm FFC interconnect | Analog HP L/R (guarded by GND), USB FS D+/D−, MIDI RX/TX, HP detect, power |
| IO Board is 2-layer (~50×80mm) | No high-speed digital; USB FS + headphone analog + MIDI serial |

### Board count change
- Before: 5 unique PCB designs, 9 physical boards
- After: **6 unique PCB designs, 10 physical boards**

### Main ↔ IO FFC pinout (12-pin 1.0mm)

| Pin | Signal | Notes |
|-----|---|---|
| 1 | HP_L | Analog, codec DAC output |
| 2 | HP_R | Analog, codec DAC output |
| 3 | GND (guard) | Between analog and digital |
| 4 | USB_HOST_D+ | FE1.1s upstream, 12 Mbps FS |
| 5 | USB_HOST_D− | FE1.1s upstream |
| 6 | GND (USB) | USB return |
| 7 | MIDI_RX | Serial3 pin 15, 31.25 kbaud |
| 8 | MIDI_TX | Serial4 pin 17, 31.25 kbaud |
| 9 | HP_DETECT | GPIO pin 39 |
| 10 | 5V_DIG | USB hub, MIDI circuits |
| 11 | 5V_A | HP amp clean power |
| 12 | GND | Main return |

### Files updated (8)

| File | Changes |
|---|---|
| `docs/pcb-architecture.md` | New IO Board section, updated overview/summary/connectors/mounting, back panel diagram with 2× USB-C |
| `docs/hardware.md` | USB hub/HP amp/MIDI sections annotated IO Board, PCB stackup table, BOM tables (~15 lines), panel layout |
| `docs/enclosure.md` | Back panel: added PC USB-C. Left zone: added SD slot. Right column: simplified as IO Board |
| `docs/pin-mapping.md` | MIDI/USB Host/HP detect annotated with FFC routing, new Main↔IO FFC pinout table |
| `hardware/bom.csv` | 16 lines updated with "IO Board", 2 new lines (FFC connector + cable), fabrication updated |
| `docs/connector-parts.md` | USB-A/HP TRS/MIDI TRS → IO Board, PC USB-C → back panel, new FFC 12-pin rows |
| `docs/ak4619-wiring.md` | Power architecture paragraph: HP amp on IO Board via FFC |
| `docs/pcb-design-rules.md` | IO Board added to 2-layer stackup list |
| `CLAUDE.md` | Architecture summary: 6 PCBs, IO Board, PC USB-C back panel |

### Verification
- Grepped all docs for stale "5 unique" / "9 physical" references — none found
- FFC pinout in `pin-mapping.md` matches `pcb-architecture.md` exactly (12 pins)
- All IO Board components in `bom.csv` have "IO Board" annotation
- PC USB-C consistently says "back panel" (not "top panel") across all files

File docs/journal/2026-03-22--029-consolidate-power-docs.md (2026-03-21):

# 029 — Consolidate power documentation into docs/power.md

**Date:** 2026-03-22
**Scope:** `docs/power.md`, `docs/hardware.md`, `hardware/pcbs/main/architecture.md`, `hardware/pcbs/power/`, `docs/system-topology.md`, `CLAUDE.md`

## Summary

Consolidated all power-related documentation from 6+ locations into a single `docs/power.md`. Deleted the `hardware/pcbs/power/` directory (4 files) since the power board is an off-the-shelf STUSB4500 breakout with no custom PCB. Also fixed two open issues: reconciled power budget math (openaudiotools/about#18) and resolved polyfuse board location conflict (openaudiotools/about#17).

## What changed

| Change | Detail |
|---|---|
| Created `docs/power.md` | Consolidated power reference: USB PD input, power path diagram, budget table, rail distribution, protection, soft-latch circuit, power button wiring |
| Added "Why 5V?" info block | GitHub `> [!NOTE]` admonition explaining why higher PD voltage offers no benefit |
| Slimmed `docs/hardware.md` | Replaced full Power System section (~45 lines) with 2-line summary + link to `docs/power.md` |
| Slimmed `main/architecture.md` | Removed soft-latch, power distribution, protection, and power sequencing sections; replaced with link to `docs/power.md` |
| Deleted `hardware/pcbs/power/` | Removed README.md, architecture.md, connections.md, CLAUDE.md (content absorbed into `docs/power.md`) |
| Updated `system-topology.md` | Power Module row and connector summary now link to `docs/power.md` |
| Updated `CLAUDE.md` | Board table, documentation loading guide, and cross-reference table updated for new power doc location |
| Fixed power budget (issue #18) | Worst-case: 2.67A → 2.91A; reserve: 3.20A → 3.49A; target specs: 3.4A → 2.91A |
| Fixed polyfuse location (issue #17) | Documented on Main Board (matches BOM); was incorrectly listed as Power Board in `main/architecture.md` |

## Context

Power documentation was scattered across `hardware/pcbs/power/` (4 lightweight files for an off-the-shelf module), `docs/hardware.md` (budget, distribution, input), and `hardware/pcbs/main/architecture.md` (soft-latch, TPS22965, protection, sequencing). This made it hard to get a complete picture without reading 3+ files. Since the power board has no custom PCB, a dedicated board directory was unnecessary. The new `docs/power.md` is the single canonical reference for all power system documentation.

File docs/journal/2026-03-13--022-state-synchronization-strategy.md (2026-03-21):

# 022 — State synchronization strategy for Teensy↔ESP32

**Date:** 2026-03-13
**Scope:** `despee/docs/protocol.md`, `despee/docs/integration-guide.md`, `docs/display/protocol.md`, `docs/firmware.md`, `docs/ui-architecture.md`

## Summary

Documented the state synchronization strategy between Teensy (source of truth for DSP parameters) and ESP32 (LVGL display engine). Chose a "continuous push + periodic full sync" model that keeps all widget values current regardless of which page is visible, eliminating stale-value problems on page switch.

## What changed

| File | Change |
|---|---|
| `despee/docs/protocol.md` | Added "State Synchronization Model" section: continuous push, periodic sync, bandwidth budget table, encoder echo rules, PAGE_CHANGED handling |
| `despee/docs/integration-guide.md` | Added "State Synchronization" section with code examples for continuous push, encoder value clamping, and periodic sync_tick() |
| `docs/display/protocol.md` | Mirrored state sync section from DESPEE canonical with Teensy-specific language |
| `docs/firmware.md` | Expanded UI Update Loop with continuous push and periodic sync bullet points |
| `docs/ui-architecture.md` | Added "State replication" row to Rendering Split table |

## Context

The problem: when state changes on the Teensy side (MIDI CC, state restore, etc.) while the ESP32 shows a different page, widget values go stale. Four options were analyzed:

- **A. Pull model** — rejected (adds request-response complexity to fire-and-forget protocol)
- **B. Push-on-navigate** — rejected (visible pop-in, doesn't handle gradual drift)
- **C. Continuous replication** — chosen (simple, zero page-switch latency, trivial bandwidth cost)
- **D. Periodic full sync** — chosen as insurance layer on top of C

Key design decisions:
- Encoder-originated changes are NOT echoed back (ESP32 already shows correct value), unless Teensy clamps/quantizes
- Periodic sync spreads one widget per 50 ms (~20/sec), completing full UI cycle every ~6s
- Total bandwidth: ~5.6% of UART capacity (including meters + sync + sporadic param changes)
- No new protocol commands needed — uses existing SET_VALUE/SET_TEXT/SET_STATE

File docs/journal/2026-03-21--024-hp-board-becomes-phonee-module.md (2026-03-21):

# 024 — HP Board becomes PHONEE reusable headphone module

**Date:** 2026-03-21
**Scope:** `hardware/pcbs/hp/`, all cross-referencing docs, `hardware/bom.csv`

## Summary

Redesigned the HP Board as **PHONEE** — a reusable headphone output module (like DESPEE for displays). Replaces the off-the-shelf TPA6132/MAX97220 breakout approach with a custom PCB carrying TPA6132A2 IC, PCB-mount 10kΩ log pot, and 1/4" TRS jack on a single board. PHONEE will live in its own repo at [openaudiotools/phonee](https://github.com/openaudiotools/phonee).

## What changed

| File(s) | Change |
|---|---|
| `hardware/pcbs/hp/{README,architecture,connections,CLAUDE}.md` | Renamed to PHONEE; replaced breakout module with TPA6132A2 IC; updated pot to PCB-mount; added BOM table |
| `CLAUDE.md` | Updated board table, key hardware ICs, module descriptions |
| `docs/system-topology.md` | Board summary, connector summary, reuse section, mounting section |
| `docs/hardware.md` | Stackup table, noise mitigation, grounding, BOM tables, panel layout |
| `docs/architecture-diagram.md` | Mermaid subgraph label, signal path summary |
| `docs/enclosure.md` | Section heading and module description |
| `docs/connector-parts.md` | Cable table |
| `docs/pcb-design-rules.md` | Analog domain grounding section |
| `hardware/bom.csv` | Replaced breakout module line with TPA6132A2 IC; updated pot and jack notes; updated fabrication line |
| `hardware/pcbs/io/{README,architecture,connections,CLAUDE}.md` | Updated HP Board references to PHONEE |
| `hardware/pcbs/input-mother/{connections,architecture}.md` | Updated HP Board references to PHONEE |
| `hardware/pcbs/main/architecture.md` | Updated HP Board references to PHONEE |

## Decisions

| Decision | Choice | Rationale |
|---|---|---|
| Module vs in-repo | Own project (like DESPEE) | Reusable across devices; same pattern as display module |
| Amp IC | TPA6132A2 | Best balance: capless output, SOT-23-8 (smallest), ~$1.70 total amp BOM, fewest components |
| Volume pot | PCB-mount | Single-board solution; board positions at panel via jack nut + pot nut |
| Name | PHONEE | Follows DESPEE naming convention |

## Context

No off-the-shelf module combines headphone amp + volume pot + 1/4" TRS jack on one small PCB. The previous plan used a breakout module mounted on a carrier board, but this was neither compact nor reusable. PHONEE fills the gap as a drop-in headphone output module for any audio device.

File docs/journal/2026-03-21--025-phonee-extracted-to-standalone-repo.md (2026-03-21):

# 025 — PHONEE extracted to standalone repo

**Date:** 2026-03-21
**Scope:** `d:\projects\openaudiotools\phonee\` (new repo), `hardware/pcbs/hp/README.md` (canonical-source note)

## Summary

Extracted PHONEE headphone output module into its own standalone repository at `openaudiotools/phonee`, following the same pattern as DESPEE. The standalone repo contains device-agnostic documentation (architecture, connections, integration guide with grounding/isolation strategies). MIXTEE's `hardware/pcbs/hp/` retains device-specific integration context with a canonical-source note pointing to the standalone repo.

## What was created

| File | Content |
|---|---|
| `phonee/README.md` | Project overview, specs, links |
| `phonee/CLAUDE.md` | Agent guidance (passive analog module, no firmware) |
| `phonee/LICENSE` | Triple license (CERN-OHL-P v2, CC BY 4.0, MIT) |
| `phonee/docs/architecture.md` | TPA6132A2 circuit, signal path, BOM, power, PCB notes — device-agnostic |
| `phonee/docs/connections.md` | Input connector, TRS jack, pot pinouts — generic signal names (Audio L/R, VCC, GND) |
| `phonee/docs/integration-guide.md` | Power options, grounding strategies (shared/isolated/star), detect routing (GPIO/I2C/ignore), input requirements, mechanical integration, MIXTEE example |
| `phonee/hardware/bom.csv` | PHONEE-only BOM (~$5.60 total) |

## What changed in MIXTEE

| File | Change |
|---|---|
| `hardware/pcbs/hp/README.md` | Added canonical-source note pointing to openaudiotools/phonee |

## Key design decisions

- **Device-agnostic docs:** PHONEE docs use generic names (Audio L/R, VCC, GND) — no MIXTEE-specific terms (Master L/R, 5V_ISO, GND_ISO, Board 1-top)
- **Integration guide** covers three grounding strategies (shared, isolated, star) and three detect routing options (direct GPIO, I2C expander, ignore)
- **MIXTEE as example:** The integration guide includes a concrete example of how MIXTEE integrates PHONEE (isolated domain, MCP23008 detect)
- **Canonical-source pattern:** Same as DESPEE — design changes go to phonee repo first, MIXTEE syncs

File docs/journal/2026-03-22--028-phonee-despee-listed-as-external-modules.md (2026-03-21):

# 028 — PHONEE and DESPEE listed as external modules in BOM

**Date:** 2026-03-22
**Scope:** `hardware/bom.csv`

## Summary

Replaced individual PHONEE component lines (TRS jack, pot, TPA6132A2) and the DESPEE encoder stub with single module-level entries in the MIXTEE BOM. Each module's own repo now owns its component-level BOM. Schottky diode count dropped from 25 to 24 (headphone jack ESD moved to PHONEE BOM). Fabrication line updated to exclude PHONEE PCB.

## What changed

| Change | Detail |
|---|---|
| PHONEE in bom.csv | 3 component lines → 1 module line (`openaudiotools/phonee`) |
| DESPEE in bom.csv | Merged display line + removed stale encoder qty-0 line → 1 module line (`openaudiotools/despee`) |
| Schottky diodes | 25 → 24 (HP jack ESD is PHONEE's responsibility) |
| Fabrication line | Removed PHONEE (2L) from PCB fab list; noted as external alongside DESPEE and power module |

## Context

PHONEE and DESPEE are reusable modules with their own repositories. Listing their internal components in MIXTEE's BOM created dual-maintenance and drift risk. MIXTEE's BOM now treats them the same way it treats the off-the-shelf STUSB4500 power module — as a purchased/assembled unit with a cost estimate and a pointer to the canonical source.

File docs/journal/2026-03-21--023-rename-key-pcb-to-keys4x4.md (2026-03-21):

# 023 — Rename Key PCB to Keys4x4

**Date:** 2026-03-21
**Scope:** `hardware/pcbs/key/` → `hardware/pcbs/keys4x4/`, all cross-referencing docs

## Summary

Renamed the Key PCB board directory and all references across the codebase from "Key PCB" / `pcbs/key/` to "Keys4x4 PCB" / `pcbs/keys4x4/`. The rename avoids ambiguity between the board name and generic uses of "key" (e.g., key switches, keycaps). Journal entries were left unchanged as historical records.

## What changed

| File(s) | Change |
|---|---|
| `hardware/pcbs/key/` → `hardware/pcbs/keys4x4/` | Directory renamed via `git mv` |
| `hardware/pcbs/keys4x4/{README,architecture,connections,CLAUDE}.md` | Board title updated from "Key PCB" to "Keys4x4 PCB" |
| `hardware/pcbs/keys4x4/designs/gen_pcb.py` | Docstring and silk screen text updated |
| `CLAUDE.md` | Board table path, architecture summary, cross-ref table |
| `README.md` | Repo structure tree |
| `docs/system-topology.md` | Board summary table, connector summary, reuse section, mounting section |
| `docs/pin-mapping.md` | I2C section, GPIO key matrix section, architecture link, FFC link |
| `docs/architecture-diagram.md` | Mermaid subgraph label and comment |
| `docs/enclosure.md` | Section heading and scanning description |
| `docs/hardware.md` | Stackup table, noise mitigation, BOM tables (MCP23017, 1N4148) |
| `docs/features.md` | Key scanning reference |
| `docs/pcb-design-rules.md` | 2-layer stackup list, digital domain grounding |
| `docs/connector-parts.md` | MPN table (JST-PH, CHOC), cable table |
| `docs/pcbs-workflow.md` | PDF example path |
| `hardware/bom.csv` | MCP23017 and diode notes, fabrication line |
| `hardware/pcbs/main/{connections,architecture,CLAUDE}.md` | JST-PH section, I2C mux note, do-not-read path |
| `hardware/pcbs/{daughter-output,io,hp,input-mother,power}/CLAUDE.md` | Do-not-read path references |

## Context

The name "Key PCB" was ambiguous — "key" could refer to switches, keycaps, or the board itself. "Keys4x4" explicitly describes the 4×4 key matrix grid, making it immediately clear what the board does. This is a naming-only change with no functional impact.

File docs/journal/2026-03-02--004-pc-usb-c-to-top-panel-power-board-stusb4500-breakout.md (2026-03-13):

## 2026-03-02 — PC USB-C to Top Panel, Power Board, STUSB4500 Breakout

### What was done
Two commits (`acfc9be`, `76ba381`) restructured the power and PC USB-C layout:

1. **PC USB-C moved to top panel** — Data-only USB-C receptacle moved from back panel to top panel left zone (on Main Board, near SD card slot). Eliminates 480 Mbps USB HS routing to back panel.
2. **Dedicated Power Board added** — Originally power input was on the Main Board. Moved to a separate vertical back-panel PCB for mechanical isolation.
3. **Power Board → off-the-shelf STUSB4500 breakout** — Replaced custom Power Board PCB with a purchased STUSB4500 USB PD breakout module (SparkFun or equivalent). Simplifies build — no custom power PCB needed.
4. **SD card repositioned** — Full-size SD card slot moved to left of display, vertically aligned with bottom edge of screen.

### Key decisions

| Decision | Rationale |
|---|---|
| PC USB-C on top panel (not back) | Shorter USB HS traces; back panel now audio-only + power |
| STUSB4500 breakout (purchased) | USB PD negotiation is well-solved; no reason to design custom |
| SD left of display | Near Teensy SDIO bottom pads; intuitive user access |

### Files updated
12 files across docs, hardware, and layout images. Created `hardware/pcbs/power/README.md`.

---

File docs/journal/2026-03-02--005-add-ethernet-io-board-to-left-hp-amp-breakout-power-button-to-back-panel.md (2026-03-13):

## 2026-03-02 — Add Ethernet, IO Board to Left, HP Amp Breakout, Power Button to Back Panel

### What was done
Major layout revision (`77106c0`): added Ethernet, moved IO Board from right to left side of top panel, replaced on-board TPA6132A2 headphone amp with off-the-shelf breakout module, moved power button from top panel to back panel.

### Design changes

| Change | Before | After |
|---|---|---|
| IO Board position | Top panel, right side | Top panel, left side |
| Headphone amp | TPA6132A2 IC on IO Board | Off-the-shelf TPA6132/MAX97220 breakout module (~$2–5) |
| Power button | Top panel (IO Board) | Back panel, screw-collar momentary (next to PWR USB-C) |
| Ethernet | None | Native Teensy 4.1 (DP83825I PHY) via RJ45 MagJack on IO Board |

### New Main ↔ IO FFC pinout (12-pin 1.0mm)

| Pin | Signal | Notes |
|-----|---|---|
| 1 | ETH_TX+ | Differential pair, from Teensy bottom pads |
| 2 | ETH_TX- | Differential pair |
| 3 | GND (guard) | Shield between Ethernet pairs |
| 4 | ETH_RX+ | Differential pair |
| 5 | ETH_RX- | Differential pair |
| 6 | GND (guard) | Shield between Ethernet/USB |
| 7 | USB_HOST_D+ | FE1.1s upstream, USB FS 12 Mbps |
| 8 | USB_HOST_D- | FE1.1s upstream |
| 9 | MIDI_RX | Serial3 pin 15, 31.25 kbaud |
| 10 | MIDI_TX | Serial4 pin 17, 31.25 kbaud |
| 11 | 5V_DIG | USB hub, MIDI, Ethernet circuits |
| 12 | GND | Main return |

HP_L/HP_R now route from Main Board directly to breakout module (not via FFC). Headphone detect via short wire to Teensy GPIO pin 39.

### Ethernet architecture
- Teensy 4.1 has DP83825I 10/100 PHY on-board with bottom pads (TX+, TX-, RX+, RX-, LED, GND)
- 6-pin ribbon cable from Main Board header → IO Board header
- 0.1µF coupling caps on IO Board between PHY output and RJ45 MagJack transformer
- Post-PHY analog signals — cable-tolerant, 2-layer PCB sufficient, no impedance control needed

### Top panel layout (left to right)

```
LEFT (IO Board)    CENTER (Main Board)           RIGHT (Key PCB)
MIDI HOST (USB-A)  SD Card  ┌─────────────────┐  Mute Solo Rec  —
ETH (RJ45)                  │    4.3" TFT     │   —    —    —   —
MIDI IN  TH.               │  93×56mm RA8875 │   —    —    —   —
PHONES   VOL                └─────────────────┘  Home Back Page Shift
                   Nav-X    Nav-Y    Edit
```

### Files updated (14)

| File | Changes |
|---|---|
| `docs/pcb-architecture.md` | IO Board → left, Ethernet, new FFC pinout, power button back panel, board summary |
| `docs/pin-mapping.md` | Ethernet bottom pads section, new FFC pinout, GPIO notes |
| `docs/hardware.md` | Replaced TPA6132A2 with breakout, added Ethernet section, BOM, panel layout |
| `docs/enclosure.md` | IO Board left column, power button back panel |
| `docs/connector-parts.md` | RJ45 MagJack, Ethernet headers, HP breakout header, cable entries |
| `docs/ak4619-wiring.md` | Updated HP amp reference (breakout, not TPA6132A2 IC) |
| `docs/features.md` | Power button → back panel |
| `hardware/bom.csv` | Replaced TPA6132A2 line, added RJ45/Ethernet/breakout parts |
| `hardware/mixtee-layout.*` | Updated panel layout images (afdesign, jpg, svg) |
| `hardware/pcbs/main/README.md` | Ethernet routing section, 6-pin header, power button note |
| `hardware/pcbs/io/README.md` | **Created** — IO Board Stage 1 spec |
| `CLAUDE.md` | Architecture summary updated |

### Verification
- Grepped for stale "right side/column" IO Board references — none
- Grepped for stale TPA6132A2 references — all updated to breakout module
- Power button consistently "back panel" across all 14 files
- FFC pinout matches between `pcb-architecture.md` and `pin-mapping.md`
- Layout images match doc descriptions

### Next steps
- ~~IO Board SKiDL netlist (Stage 2) — FE1.1s pin mapping needs verification against KiCad symbol~~ → done (inline in gen_pcb.py)
- ~~IO Board gen_pcb.py (Stage 3–4) — 50×80mm, panel-mount components along left edge~~ → done
- ~~IO Board routing via FreeRouting (Stage 5–7)~~ → done

---

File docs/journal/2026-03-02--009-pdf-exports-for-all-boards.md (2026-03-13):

# PDF Exports for All Existing Boards

### What was done
Generated multi-layer PDF exports for all 4 completed boards using `kicad-cli pcb export pdf`. These sit next to each `.kicad_pcb` file so contributors can review layouts on GitHub without KiCad.

### Exports

| Board | Layers | Size |
|---|---|---|
| Daughter/Output (2L) | F.Cu, B.Cu, F.SilkS, B.SilkS, F.Mask, B.Mask, Edge.Cuts | 28 KB |
| Key PCB (2L) | same 7 layers | 128 KB |
| IO Board (2L) | same 7 layers | 107 KB |
| Input Mother (4L) | + In1.Cu, In2.Cu (9 layers) | 244 KB |

All exports used `--drill-shape-opt 2` (small drill marks).

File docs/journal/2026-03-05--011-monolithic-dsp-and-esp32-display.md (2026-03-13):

# Monolithic DSP Architecture + ESP32-S3 Display Offload

**Date:** 2026-03-05

## Summary

Research session analyzed Teensy 4.1 RAM usage, audio block pool mechanics, PSRAM speed limitations, and explored alternative platforms. Two concrete architectural decisions emerged:

1. **Monolithic ChannelStrip objects** — replace ~270 individual PJRC Audio Library objects with ~80 custom objects
2. **ESP32-S3 integrated display module** — offload all display rendering from Teensy to an ESP32-S3 module with built-in LCD

## Teensy 4.1 Memory Architecture

| Region | Size | Speed | Use |
|---|---|---|-----|
| DTCM (tightly coupled) | 512 KB | 0-wait-state | Audio buffers, stack, hot variables |
| OCRAM (FlexRAM) | 512 KB | ~2 cycle | General heap, large arrays |
| PSRAM (external QSPI) | 8 MB | ~330 cycles random | Recording ring buffer only |

**Key finding:** PSRAM is unsuitable for DSP buffers due to ~330-cycle random access latency. Current spec fits in ~1 MB (DTCM + OCRAM), but the audio object count (~270 in a naive implementation) is the real scalability risk — per-object dispatch overhead (virtual calls, block alloc/free, connection traversal) dominates at that count.

## Monolithic ChannelStrip Approach

Combine gain, pan, 3-band EQ (biquads), send taps, level, mute, and peak/RMS metering into a single `AudioChannelStrip` object per channel. Metering computed inline during processing — no separate AudioAnalyzePeak/AudioAnalyzeRMS objects.

| Metric | Before (naive) | After (monolithic) |
|---|---|---|
| Audio objects | ~270 | ~80 |
| Object dispatch overhead | ~50–100% of block time | ~2–3% |
| Block pool pressure | High (each connection = alloc + free) | Low (internal buffers) |

Object breakdown: 16 ChannelStrip + 40 AudioMixer4 (bus summing) + 2 AudioInputTDM + 2 AudioOutputTDM + 16 AudioRecordQueue + misc.

## ESP32-S3 Display Offload

Replace bare 4.3" TFT + RA8875 controller with an ESP32-S3 integrated display module (e.g., Waveshare ESP32-S3-Touch-LCD-4.3 or Elecrow 4.3" CrowPanel).

**What it frees on Teensy:**
- SPI0 bus (4 pins: CS, MOSI, MISO, SCK)
- 2 GPIO pins (RA8875 INT + RESET)
- 7–27% CPU (display rendering was the most intensive non-audio task)
- SPI bus contention with audio eliminated

**Communication:** UART (2 wires: TX/RX) at 30 Hz for meter data (~6 KB/s). Parameter state sent on change. Lightweight, non-blocking, DMA-capable.

**ESP32-S3 runs LVGL** — a professional embedded UI framework with hardware-accelerated rendering, smooth animations, and anti-aliased fonts. Resolution upgrade possible (800×480 on Waveshare vs. 480×272 on RA8875).

## Platform Comparison (Explored, Not Adopted)

| Platform | Verdict | Blocker |
|---|---|---|
| Raspberry Pi | Rejected | No native TDM/I2S multi-channel; Linux latency |
| STM32H7 | Best upgrade path | Only needed if internal effects required |
| XMOS | Pro/commercial tier | Overkill for current scope |
| Daisy Seed (STM32H750) | Blocked | Only 1 free SAI port (other used by onboard codec) |
| Double-Teensy | Deferred | Effects not in current scope; revisit if needed |

## Decisions

- **Adopt monolithic ChannelStrip DSP objects** for current phase
- **Adopt ESP32-S3 integrated display module** to replace RA8875 TFT
- **External effects only** via aux sends (no internal FX processing)
- **Second Teensy / Daisy Seed deferred** — effects expansion not in current scope

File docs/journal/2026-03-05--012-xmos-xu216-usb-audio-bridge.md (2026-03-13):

# XMOS XU216 USB Audio Bridge — 24ch Multichannel to DAW

**Date:** 2026-03-05

## Summary

Added an XMOS XU216 USB Audio Class 2 bridge to the Main Board design. MIXTEE now provides 24-in / 8-out multichannel audio + USB MIDI over a single USB-C connection to the PC. This replaces the previous plan of stereo-only USB audio (UAC1) via Teensy's native USB.

## Motivation

- All 24 channels (16 pre-mix inputs + 8 bus outputs) needed in DAW for multitrack recording and mixing
- Teensy-only USB audio limited to stereo (UAC1) or max 8ch on Windows (firmware UAC2 + native driver cap)
- XMOS is the industry-standard approach (used by Focusrite, MOTU, SSL, Behringer)
- Cross-platform: class-compliant on macOS/Linux, Thesycon ASIO driver on Windows (included in XMOS reference design)

## Architecture

| Aspect | Detail |
|---|---|
| Chip | XU216-256-TQ128-C20 (~$5, 128-pin TQFP, 256KB RAM) |
| Audio to PC | 24ch: 16 ADC inputs + 8 bus outputs via passive TDM tap |
| Audio from PC | 8ch return (data line TBD — pin 9 candidate) |
| MIDI | USB MIDI composite; forwarded to Teensy via SPI0 (pins 10–13) |
| USB port | PC USB-C re-routed from Teensy → XMOS |
| Clocking | Teensy stays TDM master; XMOS runs TDM slave / USB adaptive |
| Firmware | Open-source [xmos/sw_usb_audio](https://github.com/xmos/sw_usb_audio) |
| Total added cost | ~$8 (XU216 + crystals + flash + LDO + caps + ESD) |
| Power impact | +~200 mA on 5V rail (1.0V core + 3.3V I/O) |

## Pin Changes

| Pin(s) | Before | After |
|---|---|---|
| 0, 1 | Spare (Serial1 debug) | Serial1 — ESP32-S3 display UART |
| 9 | Spare (was RA8875 INT) | Candidate: XMOS return audio (SAI1_RX_DATA2) |
| 10–13 | Spare (freed SPI0) | SPI0 — XMOS control bus (MIDI forwarding) |

## Open Items

- [ ] Validate pin 9 IOMUX for SAI1_RX_DATA2 (return audio path)
- [ ] XMOS TDM slave configuration with 2 independent TDM buses (different BCLK sources from SAI1 vs SAI2)
- [ ] SPI MIDI forwarding protocol spec (packet format, error handling)
- [ ] PCB layout: XMOS placement near USB-C connector, crystal routing, power plane partitioning

## Files Updated

- `docs/usb-audio.md` — rewritten as XMOS-primary
- `docs/hardware.md` — BOM tables, power budget, PC USB-C description
- `docs/pin-mapping.md` — pin reassignments, XMOS connections, verification checklist
- `docs/firmware.md` — XMOS communication in priority model
- `docs/system-topology.md` — XMOS added to main board summary
- `hardware/pcbs/main/architecture.md` — XMOS subsystem section
- `hardware/pcbs/main/connections.md` — PC USB-C rerouting, XMOS↔Teensy connections
- `hardware/bom.csv` — XMOS + support components
- `docs/features.md` — USB audio section updated
- `CLAUDE.md` — architecture summary updated

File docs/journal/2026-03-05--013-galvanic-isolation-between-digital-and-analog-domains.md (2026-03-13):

## 2026-03-05 — Galvanic Isolation Between Digital and Analog Domains

Added galvanic isolation at the FFC boundary between Main Board (digital domain) and Input Mother Boards (analog domain). No shared copper between domains.

### Isolation Components (per FFC, ×2)

| Component | Purpose | Key Spec |
|---|---|---|
| Murata MEJ2S0505SC | Isolated DC-DC 5V→5V_ISO | 2W (400 mA), 5.2 kV, SIP-7 TH |
| Si8662BB-B-IS1 | 6-ch digital isolator (TDM) | 150 Mbps, 4 fwd + 2 rev, SOIC-16W |
| ISO1541DR | Isolated bidirectional I2C | 1 MHz, SOIC-8 |

**BOM addition:** ~$30 total (including passives and upgraded FFC connectors).

### Key Changes

| Change | Details |
|---|---|
| FFC 16→20 pin | 7× GND_ISO pins for low-impedance isolated return paths |
| TS5A3159 moved to Board 1-top | Output mute stays in isolated analog domain |
| MCP23008 added to Board 1-top | Controls mute (GP0-3), codec PDN (GP4-5), headphone detect (GP6); address 0x21 |
| HP Board (NEW) | Standalone headphone amp in isolated domain, powered from Board 1-top via 4-pin cable |
| HP amp removed from IO Board | IO Board now digital-only (USB hub, MIDI, Ethernet) |
| 5 Teensy GPIO pins freed | 30, 35, 37, 38 (mute), 39 (headphone detect) — now spare |
| XMOS TDM tap unchanged | Pre-isolator tap on Main Board digital side |

### Files Updated (27 files)

**Primary:** `input-mother/connections.md`, `main/connections.md`, `main/architecture.md`, `input-mother/architecture.md`, `io/architecture.md`, `io/connections.md`, `io/README.md`, `pin-mapping.md`, `hardware.md`, `system-topology.md`, `bom.csv`

**New:** `hp/README.md`, `hp/connections.md`, `hp/architecture.md`, `hp/CLAUDE.md`

**Secondary:** `pcb-design-rules.md`, `firmware.md`, `usb-audio.md`, `ak4619-wiring.md`, `enclosure.md`, `connector-parts.md`, `daughter-output/connections.md`

**CLAUDE.md files:** Root `CLAUDE.md`, `main/CLAUDE.md`, `input-mother/CLAUDE.md`, `io/CLAUDE.md`, `main/README.md`, `input-mother/README.md`

### Timing Check

BCLK = 24.576 MHz → 40.7 ns period. Si8662BB propagation ~7.5 ns. Round-trip (BCLK out + SDOUT back) ~25 ns including codec delay. Within 40.7 ns period — BB (high-speed) grade mandatory.

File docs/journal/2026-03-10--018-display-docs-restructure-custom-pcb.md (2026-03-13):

# 018 — Display Docs Restructure: Custom PCB Approach

**Date:** 2026-03-10
**Scope:** Documentation restructure + hardware approach change

## What Changed

### Hardware approach: integrated module → custom PCB

Replaced the off-the-shelf ESP32-S3 integrated display module (Waveshare/Elecrow dev board) with a **custom display PCB** design:

- **MCU:** ESP32-S3-WROOM-1-N16R8 (16 MB flash, 8 MB PSRAM)
- **LCD:** Bare 4.3" 800×480 capacitive touch panel (40-pin RGB interface)
- **Touch:** GT911 or CST340 (integrated in LCD FPC)

**Why custom PCB:**
- Guaranteed EN/GPIO0 access (critical for SD card update reflash)
- Board outline designed to MIXTEE enclosure dimensions
- PWM-dimmable backlight
- Lower BOM cost at volume (~$8–12 vs ~$20–25 for dev board)
- No single-vendor supply risk

### Documentation restructure

Created `docs/display/` directory and reorganized:

| Old path | New path | Notes |
|---|---|---|
| `docs/display-engine.md` | `docs/display/protocol.md` | Moved, nav links updated |
| `docs/display-rationale.md` | `docs/display/rationale.md` | Rewritten with custom PCB approach |

### New content in rationale.md

- Recommended hardware section (custom PCB specs, comparison table)
- PCB and firmware notes (FPC routing, backlight driver, boot control, decoupling)
- "Why not a secondary Teensy?" FAQ — HalfKay is USB-only (no UART reflash path), cost/capability comparison table
- Preserved detailed "Why a single update flow" section, updated for custom PCB

### Cross-reference updates

All files that referenced old paths or "integrated display module" updated:

- `docs/firmware.md` — links + terminology
- `docs/ui-architecture.md` — link
- `docs/sd-update.md` — link + risks table (EN/GPIO0 concern removed, custom PCB guarantees it)
- `docs/features.md` — display section rewritten
- `docs/hardware.md` — BOM table, power budget, panel layout
- `docs/architecture-diagram.md` — mermaid node label
- `hardware/pcbs/main/connections.md` — connector description
- `CLAUDE.md` — Architecture at a Glance, cross-ref table

## Verification

- Zero "Waveshare"/"Elecrow"/"integrated display module" in docs (except rationale.md historical context)
- Zero old paths (`display-engine.md`, `display-rationale.md`) in docs
- WROOM-1-N16R8 references confirmed in features, hardware, rationale, architecture-diagram

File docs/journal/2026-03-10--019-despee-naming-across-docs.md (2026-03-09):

# 019 — DESPEE naming across docs

**Date:** 2026-03-10
**Scope:** Documentation naming cleanup

## What changed

Named DESPEE explicitly everywhere the custom ESP32-S3 display PCB is referenced. Previously, docs described it generically as "ESP32-S3 custom display PCB" or "ESP32-S3 integrated display module" without naming the standalone project.

## Files modified

| File | Change |
|---|---|
| `hardware/bom.csv` | Display entry → "DESPEE display module", Custom PCB, updated price to $15–20 |
| `docs/features.md` | Added DESPEE name and link |
| `docs/firmware.md` | Added DESPEE reference for display offloading |
| `docs/hardware.md` | Power budget label → "DESPEE display module" |
| `docs/display/rationale.md` | Added DESPEE naming at Recommended Hardware heading |
| `docs/ui-architecture.md` | Added DESPEE name/link to display engine description |
| `docs/sd-update.md` | "ESP32-S3 display engine firmware" → "DESPEE display engine firmware" |
| `hardware/pcbs/main/connections.md` | Section heading → "DESPEE Display Header" |
| `CLAUDE.md` | Updated Architecture at a Glance, Key ICs, Key Libraries |

## Context

DESPEE (openaudiotools/despee) is the standalone display module project — same hardware/firmware across all Open Audio Tools devices. This change is part of a cross-repo effort to establish DESPEE as the standard display component (MIXTEE, SYNTEE, ABOUT repos updated together).

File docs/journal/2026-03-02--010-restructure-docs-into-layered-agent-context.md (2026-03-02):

# Restructure Docs into Layered Agent Context

Reorganized the flat `docs/` directory into a layered documentation architecture so AI agents load only board-relevant context instead of the entire ~150KB doc set.

## What Changed

### Per-board directories (`hardware/pcbs/{board}/`)

Each board now has:

| File | Purpose |
|---|---|
| `README.md` | Trimmed to essentials — dimensions, layers, key ICs, status |
| `connections.md` | Interface contract — connector pinouts, signal tables |
| `architecture.md` | Deep implementation — circuits, register configs, analog design |
| `CLAUDE.md` | Agent context guide — what to read, what to skip |
| `designs/` | All KiCad files, scripts, gerbers (moved from board root) |

Boards: input-mother, io, main, key, daughter-output, power.

### Design files moved to `designs/`

For daughter-output, input-mother, io, key: all KiCad files (`*.kicad_pcb`, `*.kicad_pro`, `*.dsn`, `*.ses`, `gen_pcb.py`, `fp-lib-table`, `gerbers/`, etc.) moved into `designs/` subdirectory. Updated `fp-lib-table` and `gen_pcb.py` relative paths (`../../lib/` → `../../../lib/`).

### Shared docs trimmed

| File | Change |
|---|---|
| `pcb-architecture.md` | Renamed → `system-topology.md`, trimmed from 355→~85 lines |
| `hardware.md` | Removed board-specific sections (analog stages, USB hub, MIDI, soft-latch, detailed power), added redirects. ~422→~287 lines |
| `pin-mapping.md` | Removed FFC pinouts, key matrix wiring, power sequencing, added redirects. ~380→~275 lines |
| `ak4619-wiring.md` | Replaced with 5-line redirect stub → `input-mother/ak4619-wiring.md` |
| `connector-parts.md` | Replaced with compact MPN index table |

### Root files updated

- `CLAUDE.md` — rewritten with new structure, Documentation Loading Guide, updated cross-references
- `README.md` — updated repo structure tree and documentation tables

### Global link audit

All references to `pcb-architecture.md` updated to `system-topology.md`. All `ak4619-wiring.md` links updated to new location. Journal entries left as historical records.

## Context Size Impact

| Agent task | Before | After |
|---|---|---|
| IO Board PCB work | ~69KB | ~18KB |
| Input Mother PCB work | ~90KB | ~30KB |
| Key PCB work | ~64KB | ~13KB |
| Cross-board interface check | ~20KB | ~2KB |

## Files Created/Modified

- 24 new files across 6 board directories (connections.md, architecture.md, CLAUDE.md, plus ak4619-wiring.md copy for input-mother)
- 4 boards' design files moved to `designs/` subdirectories
- 4 fp-lib-table + 4 gen_pcb.py path fixes
- 6 board READMEs trimmed
- 5 shared docs trimmed/renamed/replaced
- 2 root files (CLAUDE.md, README.md) updated
- Multiple cross-reference link fixes across docs

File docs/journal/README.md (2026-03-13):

# MIXTEE Development Journal

Chronological log of design decisions, implementation sessions, and architecture changes.

Entries are named `YYYY-MM-DD--NNN-description.md` where `NNN` is a global sequence number.

To add an entry: `/journal <title>`
To search: `/journal search <query>`
To review recent context: `/journal context [N]`

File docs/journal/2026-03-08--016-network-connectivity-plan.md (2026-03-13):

# Network Connectivity Plan (v1)

**Date:** 2026-03-08

## Summary

Drafted and documented the Teensy Network Connectivity Plan (v1) for MIXTEE and related devices (synths, controllers, hubs). The plan covers:

- Common network stack (IPv4/UDP, DHCP + link-local fallback)
- mDNS/DNS-SD discovery with `_jfa-audio._udp` and `_jfa-midi2._udp` service types
- PTP (IEEE 1588v2) time sync with mixer as grandmaster
- RTP audio streaming (AES67-style: 48 kHz, 24-bit, 1 ms packets)
- Network MIDI 2.0 (UDP + UMP)
- Patchbay "brain" for routing (runs on mixer/hub)

## Feasibility Assessment

| Resource | Used | Available | Verdict |
|---|---|---|---|
| CPU | ~40% (30% audio + 10% network) | ~60% headroom | OK |
| Ethernet bandwidth | ~18.4 Mbps (16ch RTP) | 100 Mbps link | OK |
| PSRAM | ~2 MB (recording) | ~6 MB for network buffers | OK |
| GPIO | 0 additional needed | 6 spare pins | OK |

**Key caveat:** PTP limited to ~10-100 us accuracy (software timestamping only; DP83825I PHY lacks hardware PTP support). Sufficient for studio use with 1 ms packet buffers.

## Files

- Created: `docs/network-connectivity.md`

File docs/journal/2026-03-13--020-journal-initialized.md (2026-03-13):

# 020 — Journal initialized

**Date:** 2026-03-13
**Scope:** Project tooling setup

## Summary

Formalized the development journal system with `/journal` skill integration and moved the journal directory from `journal/` to `docs/journal/`.

## What changed

| File | Change |
|---|---|
| `journal/` → `docs/journal/` | Moved journal directory under docs |
| `docs/journal/README.md` | Updated with standard journal template and usage commands |
| `CLAUDE.md` | Added Journal section with `/journal` workflow guidance |

## Context

The journal has been in use since 2026-03-01 (19 entries). This entry formalizes the `/journal` skill integration for consistent entry creation, search, and context retrieval.

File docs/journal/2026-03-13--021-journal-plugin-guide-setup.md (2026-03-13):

# 021 — Journal plugin GUIDE.md setup

**Date:** 2026-03-13
**Scope:** Project tooling, CLAUDE.md cleanup

## Summary

Removed the inline journal section from `CLAUDE.md` and replaced it with the plugin-driven `@docs/journal/GUIDE.md` import. Created `docs/journal/GUIDE.md` with the standard journal plugin template.

## What changed

| File | Change |
|---|---|
| `CLAUDE.md` | Removed the "## Journal" section (lines 138–144) that contained inline journal instructions |
| `CLAUDE.md` | Added `@docs/journal/GUIDE.md` import at the end of the file |
| `docs/journal/GUIDE.md` | Created with standard plugin template — commands, usage guidance, examples |

## Context

The previous journal setup embedded instructions directly in `CLAUDE.md`. The dev-journal plugin provides a `GUIDE.md` template that is imported via `@docs/journal/GUIDE.md`, keeping `CLAUDE.md` cleaner and letting the plugin manage its own documentation. This completes the journal init process started in entry 020.

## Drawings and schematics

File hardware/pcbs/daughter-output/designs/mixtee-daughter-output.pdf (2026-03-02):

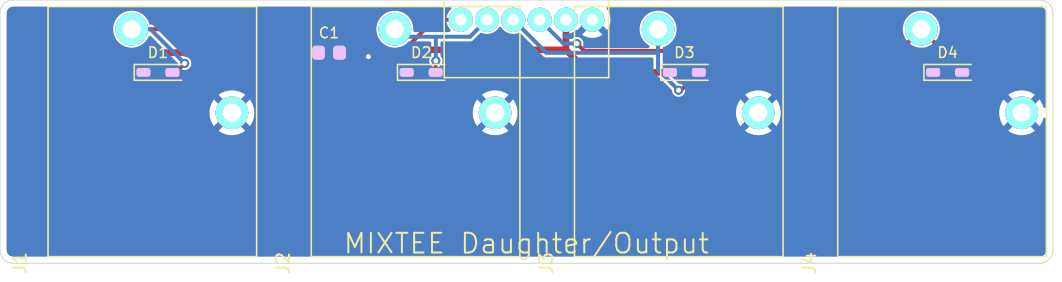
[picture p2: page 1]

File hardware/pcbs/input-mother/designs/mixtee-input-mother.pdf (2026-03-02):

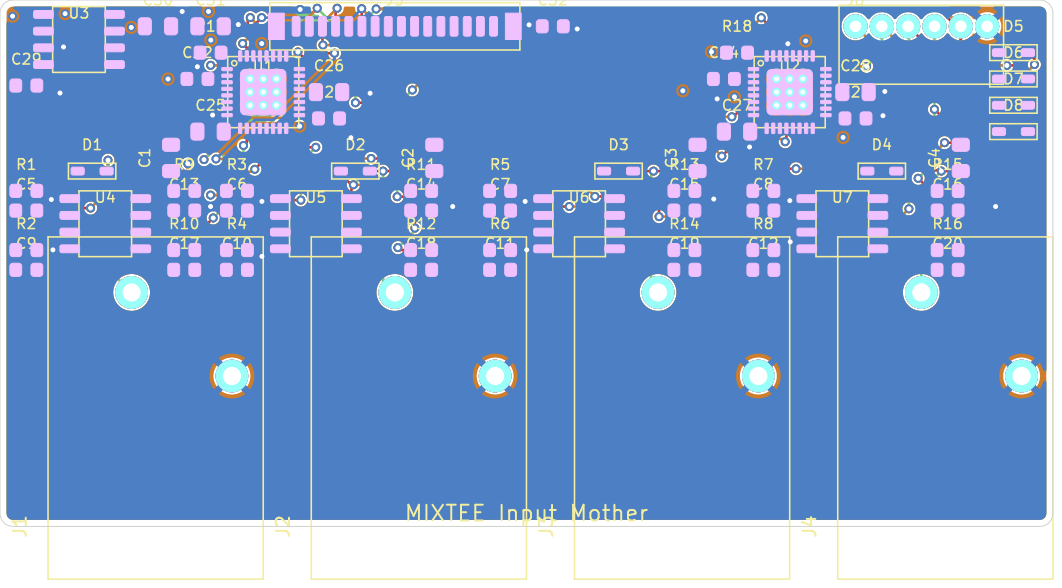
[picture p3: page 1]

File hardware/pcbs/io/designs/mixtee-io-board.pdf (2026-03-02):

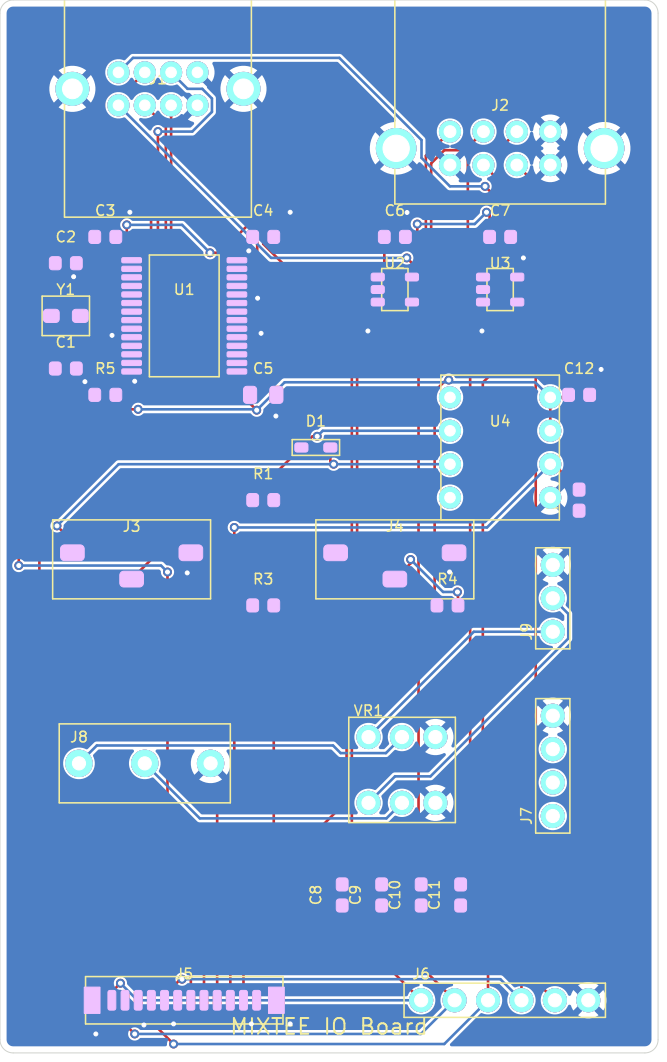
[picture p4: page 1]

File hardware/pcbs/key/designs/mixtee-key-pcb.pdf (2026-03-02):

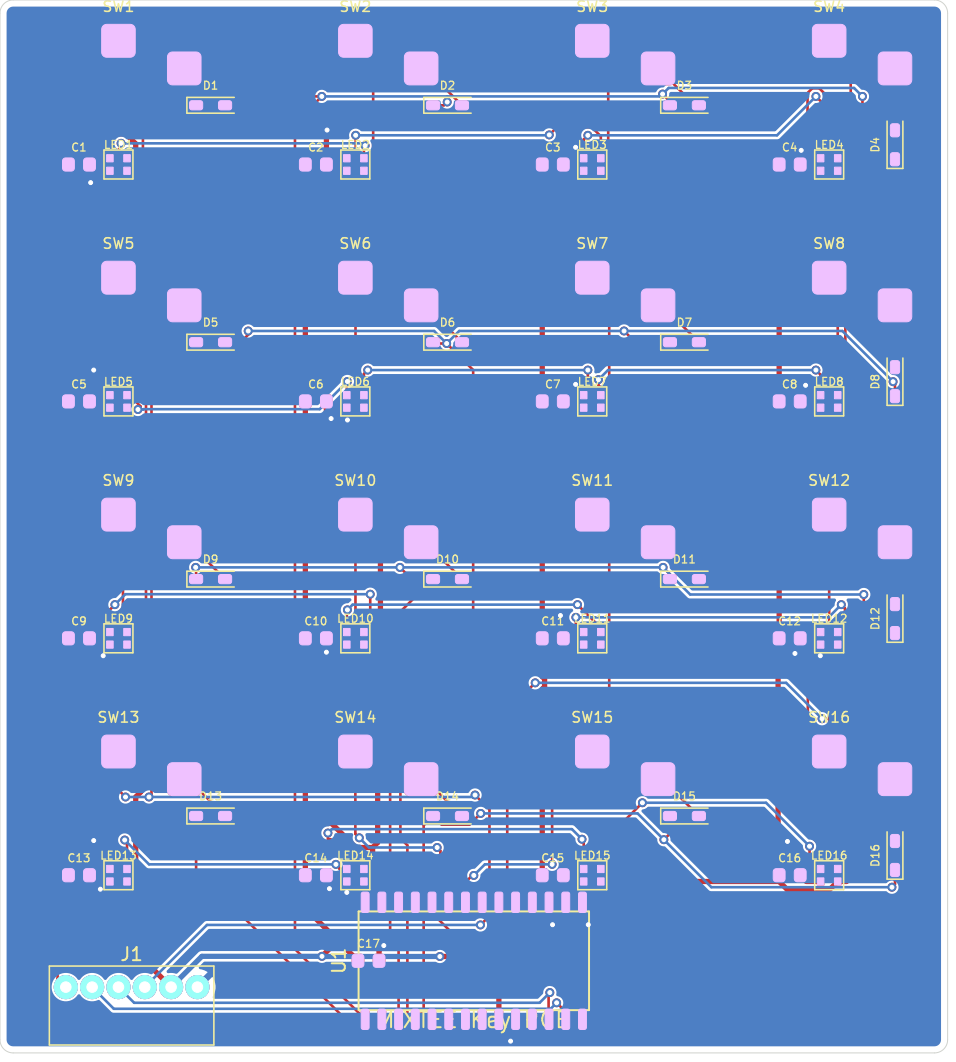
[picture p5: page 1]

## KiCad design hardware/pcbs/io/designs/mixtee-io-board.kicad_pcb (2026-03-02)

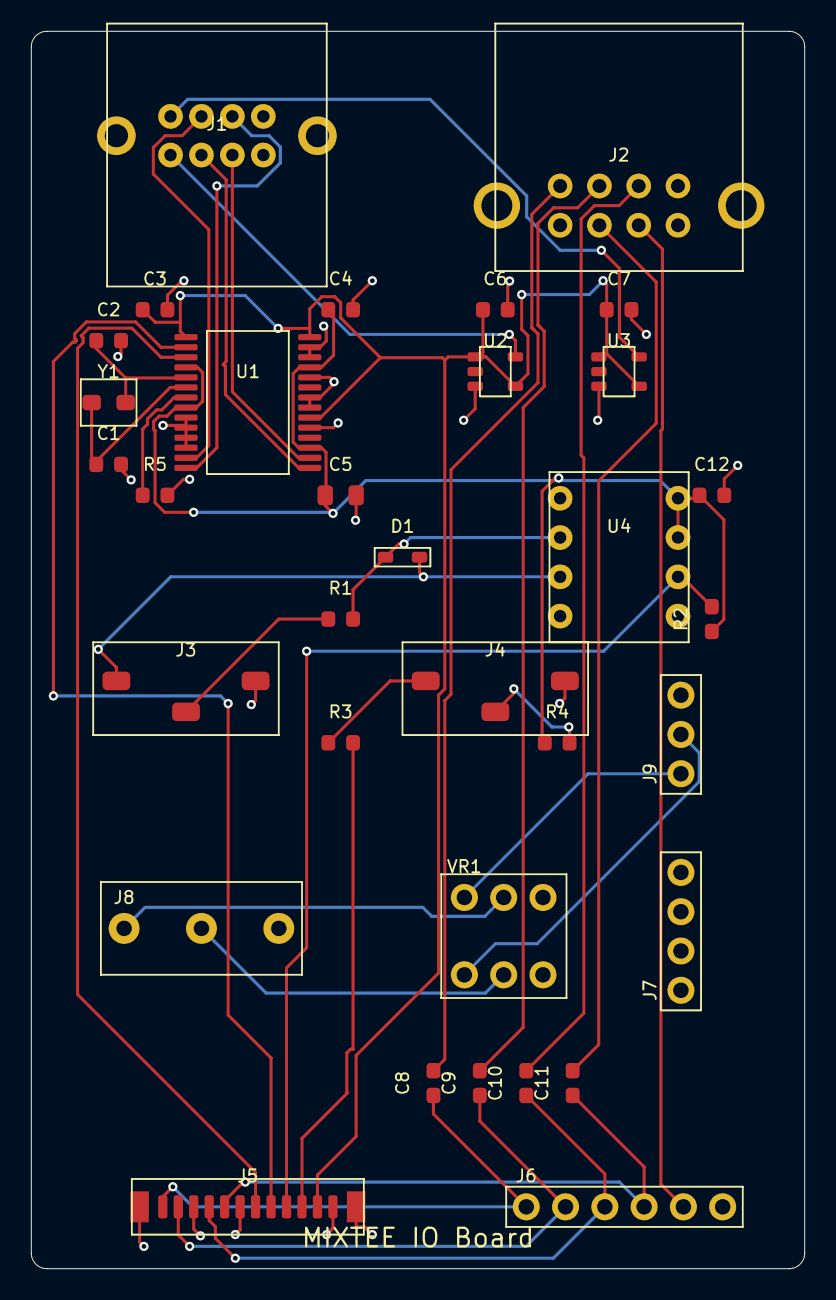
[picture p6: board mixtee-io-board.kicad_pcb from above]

Board: 2 copper layers, 50.0 x 80.0 mm, 33 parts (0 on the bottom side), 34 nets.

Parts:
C1, C2: 15pF; C_0603_1608Metric
C3, C4, C6, C7, C8, C9, C10, C11, C12: 100nF; C_0603_1608Metric
C5: 10uF; C_0805_2012Metric
D1: 1N4148; D_SOD-123
J1: 67298-4090; USB_A_Amphenol_67298-4090_Dual
J2: RJ45_MagJack
J3, J4: SJ-3523-SMT; CUI_SJ-3523-SMT
J5: FFC-12; FFC_12pin_1mm
J6: ETH_HDR; PinHeader_1x06_P2.54mm_Vertical
J7: HP_BRK; PinHeader_1x04_P2.54mm_Vertical
J8: HP_TRS; Jack_3.5mm_Switchcraft_35RASMT2BHNTRX
J9: HP_OUT; PinHeader_1x03_P2.54mm_Vertical
R1: 220; R_0603_1608Metric
R2: 470; R_0603_1608Metric
R3: 33; R_0603_1608Metric
R4: 10; R_0603_1608Metric
R5: 12k; R_0603_1608Metric
U1: FE1.1s; SSOP-28_5.3x10.2mm_P0.65mm
U2, U3: TPS2051; SOT-23-5
U4: 6N138; DIP-8_W7.62mm
VR1: 10k_Dual; Potentiometer_Dual
Y1: 12MHz; Crystal_SMD_3225-2Pin_3.2x2.5mm

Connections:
5V_DIG: C3.1, C6.1, C7.1, J5.11, U1.1, U1.20, U1.28, U2.1, U2.4, U3.1, U3.4
ETH_LED: J2.7, J6.5
ETH_RXN: C11.1, J5.5, J6.4
ETH_RXN_MJ: C11.2, J2.6
ETH_RXP: C10.1, J5.4, J6.3
ETH_RXP_MJ: C10.2, J2.3
ETH_TXN: C9.1, J5.2, J6.2
ETH_TXN_MJ: C9.2, J2.2
ETH_TXP: C8.1, J5.1, J6.1
ETH_TXP_MJ: C8.2, J2.1
GND: C1.2, C2.2, C3.2, C4.2, C5.2, C6.2, C7.2, C12.2, J1.4, J1.8, J1.S1, J1.S2, J2.4, J2.5, J2.8, J2.S1, J2.S2, J3.S, J4.S, J5.3, J5.6, J5.12, J5.MP, J6.6, J7.4, J8.S, J9.3, R5.2, U1.9, U1.10, U1.11, U1.12, U1.19, U1.21, U1.22, U1.24, U1.26, U1.27, U2.3, U3.3, U4.5, VR1.A3, VR1.B3
HP_AMP_L: J9.1, VR1.A1
HP_AMP_R: J9.2, VR1.B1
HP_OUT_L: J8.T, VR1.A2
HP_OUT_R: J8.R, VR1.B2
MIDI_IN_OA: D1.1, R1.2, U4.2
MIDI_IN_OK: D1.2, J3.T, U4.3
MIDI_IN_R: J3.R, R1.1
MIDI_OUT_SINK: J4.T, R3.1
MIDI_OUT_SRC: J4.R, R4.2
MIDI_RX: J5.9, R2.2, U4.6
MIDI_TX: J5.10, R3.2
REXT_N: R5.1, U1.7
USB_DN1_DM: J1.2, U1.15
USB_DN1_DP: J1.3, U1.16
USB_DN2_DM: J1.6, U1.13
USB_DN2_DP: J1.7, U1.14
USB_UP_DM: J5.8, U1.2
USB_UP_DP: J5.7, U1.3
V33: C4.1, C5.1, C12.1, R2.1, R4.1, U1.4, U1.8, U1.17, U1.25, U4.7, U4.8
VBUS1: J1.1, U2.5
VBUS2: J1.5, U3.5
XTAL_IN: C1.1, U1.6, Y1.1
XTAL_OUT: C2.1, U1.5, Y1.2

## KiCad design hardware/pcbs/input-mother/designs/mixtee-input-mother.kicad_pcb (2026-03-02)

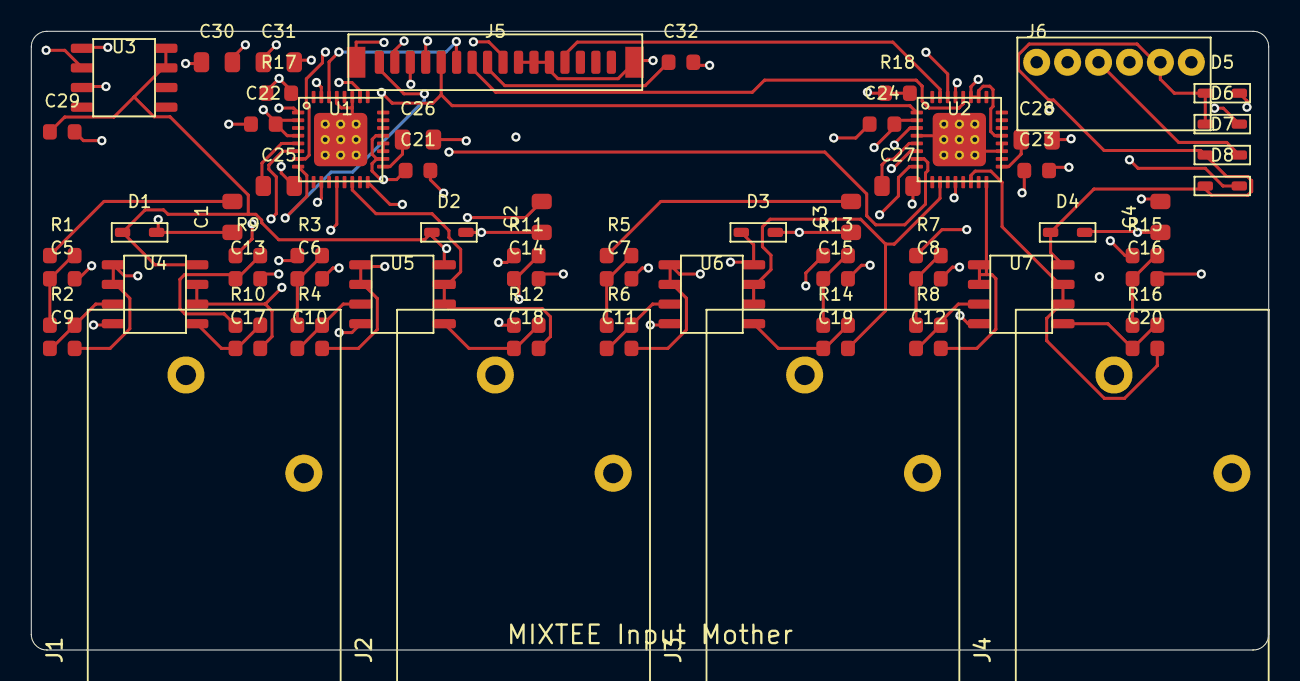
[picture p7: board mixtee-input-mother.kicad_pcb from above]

Board: 4 copper layers, 80.0 x 40.0 mm, 71 parts (0 on the bottom side), 52 nets.

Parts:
C1, C2, C3, C4, C31: 10uF; C_0805_2012Metric
C5, C6, C7, C8, C13, C14, C15, C16: 6.8nF; C_0603_1608Metric
C9, C10, C11, C12, C17, C18, C19, C20: 3.3nF; C_0603_1608Metric
C21, C22, C23, C24, C29, C32: 100nF; C_0603_1608Metric
C25, C26, C27, C28: 2.2uF; C_0805_2012Metric
C30: 1uF; C_0805_2012Metric
D1, D2, D3, D4, D5, D6, D7, D8: ESD; D_SOD-323
J1, J2, J3, J4: 112BPC; Switchcraft_112BPC
J5: FFC-16; FFC_16pin_1mm
J6: B6B-PH-K-S; JST_PH_B6B-PH-K_1x06_P2.00mm_Vertical
R1, R2, R3, R4, R5, R6, R7, R8, R9, R10, R11, R12, R13, R14, R15, R16: 1k; R_0603_1608Metric
R17, R18: 10k; R_0603_1608Metric
U1, U2: AK4619VN; QFN-32-1EP_5x5mm_P0.5mm_EP3.45x3.45mm
U3: ADP7118; SOIC-8_3.9x4.9mm_P1.27mm
U4, U5, U6, U7: OPA1678; SOIC-8_3.9x4.9mm_P1.27mm

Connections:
5V_A: C29.1, D1.1, D2.1, D3.1, D4.1, D5.1, D6.1, D7.1, D8.1, J5.9, J6.5, U3.7, U3.8, U4.8, U5.8, U6.8, U7.8
5V_DIG: C32.1, J5.8
AIN_1_AC: C1.2, R1.1
AIN_3_AC: C2.2, R3.1
AIN_5_AC: C3.2, R5.1
AIN_7_AC: C4.2, R7.1
BCLK: J5.2, U1.7, U2.7
DAIN_R1: D5.2, J6.1, R9.1
DAIN_R2: D6.2, J6.2, R11.1
DAIN_R3: D7.2, J6.3, R13.1
DAIN_R4: D8.2, J6.4, R15.1
FILT_IN_1: C9.1, R2.2, U4.3
FILT_IN_3: C10.1, R4.2, U5.3
FILT_IN_5: C11.1, R6.2, U6.3
FILT_IN_7: C12.1, R8.2, U7.3
FILT_IN_R1: C17.1, R10.2, U4.5
FILT_IN_R2: C18.1, R12.2, U5.5
FILT_IN_R3: C19.1, R14.2, U6.5
FILT_IN_R4: C20.1, R16.2, U7.5
FN1_1: C5.1, R1.2, R2.1
FN1_3: C6.1, R3.2, R4.1
FN1_5: C7.1, R5.2, R6.1
FN1_7: C8.1, R7.2, R8.1
FN1_R1: C13.1, R9.2, R10.1
FN1_R2: C14.1, R11.2, R12.1
FN1_R3: C15.1, R13.2, R14.1
FN1_R4: C16.1, R15.2, R16.1
FOUT_1: C9.2, U1.12, U4.1, U4.2
FOUT_3: C10.2, U1.16, U5.1, U5.2
FOUT_5: C11.2, U2.12, U6.1, U6.2
FOUT_7: C12.2, U2.16, U7.1, U7.2
FOUT_R1: C17.2, U1.10, U4.6, U4.7
FOUT_R2: C19.2, U2.10, U6.6, U6.7
FOUT_R3: C20.2, U2.14, U7.6, U7.7
FOUT_R4: C18.2, U1.14, U5.6, U5.7
GND: C5.2, C6.2, C7.2, C8.2, C13.2, C14.2, C15.2, C16.2, C21.2, C22.2, C23.2, C24.2, C25.2, C26.2, C27.2, C28.2, C29.2, C30.2, C31.2, C32.2, J1.S, J2.S, J3.S, J4.S, J5.10, J5.11, J5.12, J5.MP, J6.6, U1.2, U1.4, U1.19, U1.20, U1.27, U1.29, U1.33, U2.2, U2.4, U2.19, U2.20, U2.29, U2.33, U3.3, U4.4, U5.4, U6.4, U7.4
JACK_1: C1.1, D1.2, J1.T
JACK_2: C2.1, D2.2, J2.T
JACK_3: C3.1, D3.2, J3.T
JACK_4: C4.1, D4.2, J4.T
LRCLK: J5.3, U1.6, U2.6
MCLK: J5.1, U1.8, U2.8
SCL: J5.7, U1.28, U2.28
SDA: J5.6, U1.30, U2.30
SDIN1: J5.5, U1.1, U2.1
SDOUT1: J5.4, U1.31
SDOUT2: J5.13, U2.31
U1_AVDRV: C25.1, U1.5
U1_VCOM: C26.1, U1.17
U2_AVDRV: C27.1, U2.5
U2_VCOM: C28.1, U2.17
V33_A: C21.1, C22.1, C23.1, C24.1, C30.1, C31.1, R17.1, R17.2, R18.1, R18.2, U1.3, U1.18, U1.21, U1.26, U2.3, U2.18, U2.21, U2.26, U2.27, U3.1, U3.2

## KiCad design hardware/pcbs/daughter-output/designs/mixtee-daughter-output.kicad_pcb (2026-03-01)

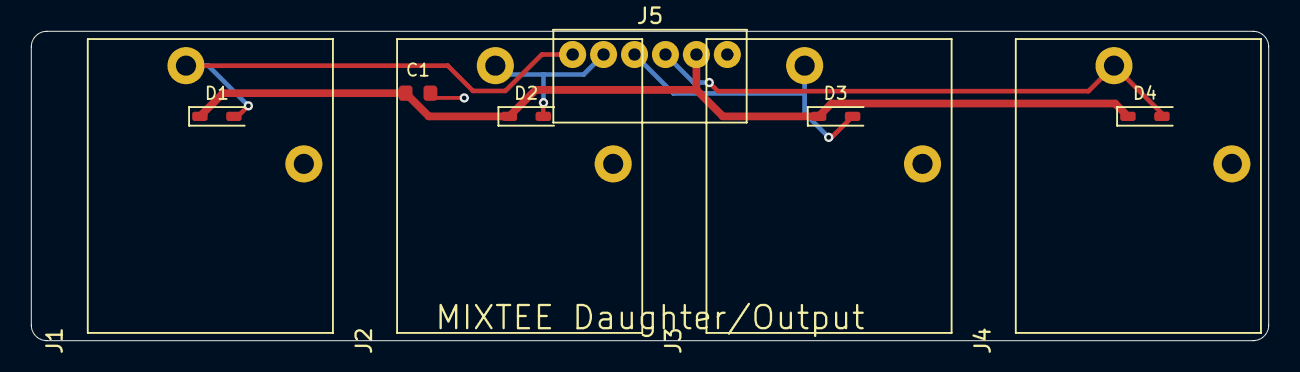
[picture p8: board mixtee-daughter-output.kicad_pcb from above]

Board: 2 copper layers, 80.0 x 20.0 mm, 10 parts (0 on the bottom side), 6 nets.

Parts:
C1: 100nF; C_0603_1608Metric
D1, D2, D3, D4: BAT54; D_SOD-323
J1, J2, J3, J4: 112BPC; Switchcraft_112BPC
J5: B6B-PH-K-S; JST_PH_B6B-PH-K_1x06_P2.00mm_Vertical

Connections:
+5VA: C1.1, D1.1, D2.1, D3.1, D4.1, J5.5
AIN1: D1.2, J1.T, J5.1
AIN2: D2.2, J2.T, J5.2
AIN3: D3.2, J3.T, J5.3
AIN4: D4.2, J4.T, J5.4
GND: C1.2, J1.S, J2.S, J3.S, J4.S, J5.6

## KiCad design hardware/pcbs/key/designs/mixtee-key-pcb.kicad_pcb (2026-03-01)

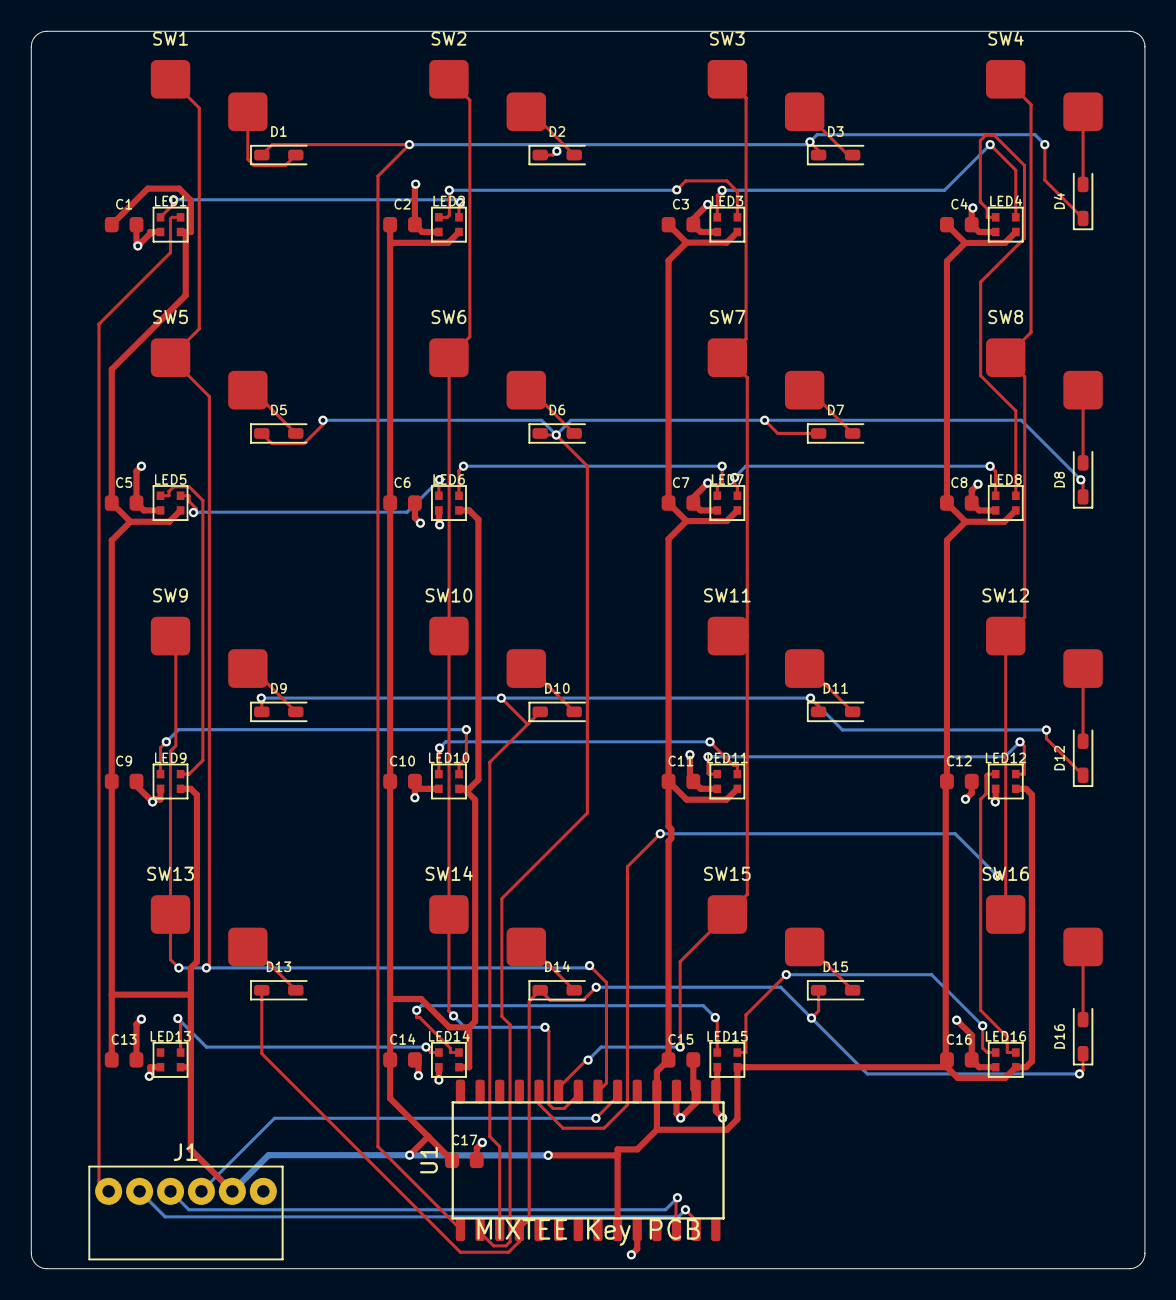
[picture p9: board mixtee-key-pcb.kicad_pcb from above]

Board: 2 copper layers, 72.0 x 80.0 mm, 67 parts (0 on the bottom side), 45 nets.

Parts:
C1, C2, C3, C4, C5, C6, C7, C8, C9, C10, C11, C12, C13, C14, C15, C16, C17: 100nF; C_0603_1608Metric
D1, D2, D3, D4, D5, D6, D7, D8, D9, D10, D11, D12, D13, D14, D15, D16: 1N4148; D_SOD-123
J1: B6B-PH-K-S; JST_PH_B6B-PH-K_1x06_P2.00mm_Vertical
LED1, LED2, LED3, LED4, LED5, LED6, LED7, LED8, LED9, LED10, LED11, LED12, LED13, LED14, LED15, LED16: WS2812B-2020
SW1, SW2, SW3, SW4, SW5, SW6, SW7, SW8, SW9, SW10, SW11, SW12, SW13, SW14, SW15, SW16: CPG135001S30; Kailh_Choc_V1_Hotswap
U1: MCP23017; SOIC-28W_7.5x17.9mm_P1.27mm

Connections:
5V: C1.1, C2.1, C3.1, C4.1, C5.1, C6.1, C7.1, C8.1, C9.1, C10.1, C11.1, C12.1, C13.1, C14.1, C15.1, C16.1, C17.1, J1.5, LED1.3, LED2.3, LED3.3, LED4.3, LED5.3, LED6.3, LED7.3, LED8.3, LED9.3, LED10.3, LED11.3, LED12.3, LED13.3, LED14.3, LED15.3, LED16.3, U1.9, U1.18
COL0: SW1.1, SW5.1, SW9.1, SW13.1, U1.21
COL1: SW2.1, SW6.1, SW10.1, SW14.1, U1.22
COL2: SW3.1, SW7.1, SW11.1, SW15.1, U1.23
COL3: SW4.1, SW8.1, SW12.1, SW16.1, U1.24
GND: C1.2, C2.2, C3.2, C4.2, C5.2, C6.2, C7.2, C8.2, C9.2, C10.2, C11.2, C12.2, C13.2, C14.2, C15.2, C16.2, C17.2, J1.6, LED1.2, LED2.2, LED3.2, LED4.2, LED5.2, LED6.2, LED7.2, LED8.2, LED9.2, LED10.2, LED11.2, LED12.2, LED13.2, LED14.2, LED15.2, LED16.2, U1.10, U1.15, U1.16, U1.17
INT: J1.4, U1.20
NEO_D0: LED1.1, LED2.4
NEO_D1: LED2.1, LED3.4
NEO_D2: LED3.1, LED4.4
NEO_D3: LED4.1, LED8.4
NEO_D4: LED7.4, LED8.1
NEO_D5: LED6.4, LED7.1
NEO_D6: LED5.4, LED6.1
NEO_D7: LED5.1, LED9.4
NEO_D8: LED9.1, LED10.4
NEO_D9: LED10.1, LED11.4
NEO_D10: LED11.1, LED12.4
NEO_D11: LED12.1, LED16.4
NEO_D12: LED15.4, LED16.1
NEO_D13: LED14.4, LED15.1
NEO_D14: LED13.4, LED14.1
NEO_DIN: J1.1, LED1.4
ROW0: D1.1, D2.1, D3.1, D4.1, U1.1
ROW1: D5.1, D6.1, D7.1, D8.1, U1.2
ROW2: D9.1, D10.1, D11.1, D12.1, U1.3
ROW3: D13.1, D14.1, D15.1, D16.1, U1.4
SCL: J1.3, U1.12
SDA: J1.2, U1.13
SW1_D: D1.2, SW1.2
SW2_D: D2.2, SW2.2
SW3_D: D3.2, SW3.2
SW4_D: D4.2, SW4.2
SW5_D: D5.2, SW5.2
SW6_D: D6.2, SW6.2
SW7_D: D7.2, SW7.2
SW8_D: D8.2, SW8.2
SW9_D: D9.2, SW9.2
SW10_D: D10.2, SW10.2
SW11_D: D11.2, SW11.2
SW12_D: D12.2, SW12.2
SW13_D: D13.2, SW13.2
SW14_D: D14.2, SW14.2
SW15_D: D15.2, SW15.2
SW16_D: D16.2, SW16.2

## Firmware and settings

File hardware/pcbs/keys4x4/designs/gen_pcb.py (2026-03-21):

"""
MIXTEE Keys4x4 PCB - KiCad PCB Generator

Board: 72 x 72 mm, 2-layer
Instances: 1 (one unique Keys4x4 PCB in system)

Components (68 total):
  - 16x Kailh CHOC hotswap sockets (CPG135001S30) — SW1..SW16
  - 16x WS2812B-2020 NeoPixels — LED1..LED16
  - 16x 100nF decoupling caps (0603) for NeoPixels — C1..C16
  - 16x 1N4148 diodes (SOD-123) anti-ghosting — D1..D16
  -  1x MCP23017 I2C GPIO expander (SOIC-28) — U1
  -  1x 100nF decoupling cap for MCP23017 — C17
  -  1x 6-pin JST-PH connector (B6B-PH-K-S) — J1

Key matrix: 4x4 via MCP23017
  - Port A (GPA0-3) = columns, inputs with internal pull-ups
  - Port B (GPB0-3) = rows, active-low scan outputs
  - 1N4148 diodes: cathode toward row (prevents ghosting)

NeoPixel chain: serpentine order for shortest routing
  LED1->LED2->LED3->LED4->LED8->LED7->LED6->LED5->
  LED9->LED10->LED11->LED12->LED16->LED15->LED14->LED13

JST-PH 6-pin connector to main board:
  Pin 1: NeoPixel DIN   (Teensy pin 6)
  Pin 2: I2C SDA         (Teensy pin 18)
  Pin 3: I2C SCL         (Teensy pin 19)
  Pin 4: MCP23017 INT    (Teensy pin 22, optional)
  Pin 5: 5V
  Pin 6: GND

Board layout (top view, F.Cu side):

  ┌──────────────────────────────────────────────────────────────────┐
  │  SW1(9,9)    SW2(27,9)    SW3(45,9)    SW4(63,9)              │ y=0
  │                                                                │
  │  SW5(9,27)   SW6(27,27)   SW7(45,27)   SW8(63,27)            │
  │                                                                │
  │  SW9(9,45)   SW10(27,45)  SW11(45,45)  SW12(63,45)           │
  │                                                                │
  │  SW13(9,63)  SW14(27,63)  SW15(45,63)  SW16(63,63)           │
  │                         [U1 on B.Cu center]  [J1]             │ y=72
  └──────────────────────────────────────────────────────────────────┘
  x=0                                                          x=72
"""

import uuid
import math
import os


# ---------------------------------------------------------------------------
# Board parameters
# ---------------------------------------------------------------------------

BOARD_W = 72.0   # mm
BOARD_H = 80.0   # mm (extra 8mm for MCP23017 + connector strip)
CORNER_R = 1.0   # mm, corner radius

# Switch grid: 4x4, 18mm pitch, centered on board
GRID_COLS = 4
GRID_ROWS = 4
PITCH = 18.0
GRID_ORIGIN_X = 9.0   # (72 - 3*18) / 2
GRID_ORIGIN_Y = 9.0

# NeoPixel chain order (serpentine): switch indices 1-16
# Row 0 L->R, Row 1 R->L, Row 2 L->R, Row 3 R->L
CHAIN_ORDER = [1, 2, 3, 4, 8, 7, 6, 5, 9, 10, 11, 12, 16, 15, 14, 13]

# Component offsets from switch center (x, y)
LED_OFFSET = (0.0, 3.5)       # NeoPixel below switch center, within cell
CAP_OFFSET = (-3.0, 3.5)      # Cap left of NeoPixel
DIODE_OFFSET = (7.0, -1.0)    # Diode right of switch

# MCP23017 placement (bottom strip, rotated 90° so pins along X)
MCP_X = 36.0
MCP_Y = 73.0
MCP_ROTATION = 90   # pins along X axis

# MCP23017 decoupling cap
MCP_CAP_X = 28.0
MCP_CAP_Y = 73.0   # left of MCP

# JST-PH connector (bottom strip, left of MCP)
CONN_X = 5.0
CONN_Y = 75.0
CONN_ROTATION = 0

# Layers
F_CU = "F.Cu"
B_CU = "B.Cu"
F_SILK = "F.SilkS"
B_SILK = "B.SilkS"
F_MASK = "F.Mask"
B_MASK = "B.Mask"
F_FAB = "F.Fab"
F_CRTYD = "F.CrtYd"
EDGE_CUTS = "Edge.Cuts"


# ---------------------------------------------------------------------------
# Net definitions
# ---------------------------------------------------------------------------

def build_nets():
    """Build the complete net dictionary {code: name}."""
    nets = {0: ""}  # unconnected
    nets[1] = "GND"
    nets[2] = "5V"
    nets[3] = "SDA"
    nets[4] = "SCL"
    nets[5] = "INT"
    nets[6] = "NEO_DIN"
    # Inter-LED chain nets: NEO_D0..NEO_D14
    for i in range(15):
        nets[7 + i] = f"NEO_D{i}"
    # Column nets: COL0..COL3
    for i in range(4):
        nets[22 + i] = f"COL{i}"
    # Row nets: ROW0..ROW3
    for i in range(4):
        nets[26 + i] = f"ROW{i}"
    # Switch-to-diode junction nets: SW1_D..SW16_D
    for i in range(16):
        nets[30 + i] = f"SW{i+1}_D"
    return nets

NETS = build_nets()


# ---------------------------------------------------------------------------
# Component-to-net mapping
# ---------------------------------------------------------------------------

def build_comp_nets():
    """Build {ref: {pad: net_code}} for all components."""
    cn = {}

    for n in range(1, 17):
        row = (n - 1) // GRID_COLS
        col = (n - 1) % GRID_COLS

        # Switch SWn: pad 1 = column, pad 2 = switch-diode junction
        cn[f"SW{n}"] = {
            "1": 22 + col,      # COL{col}
            "2": 30 + (n - 1),  # SW{n}_D
        }

        # Diode Dn: pad 1 (K) = row, pad 2 (A) = switch-diode junction
        cn[f"D{n}"] = {
            "1": 26 + row,      # ROW{row}
            "2": 30 + (n - 1),  # SW{n}_D
        }

        # Decoupling cap Cn: pad 1 = 5V, pad 2 = GND
        cn[f"C{n}"] = {"1": 2, "2": 1}

    # NeoPixels: chain order determines DIN/DOUT nets
    for p, sw_idx in enumerate(CHAIN_ORDER):
        din_net = 6 + p           # p=0 -> NEO_DIN(6), p=1 -> NEO_D0(7), etc.
        dout_net = 7 + p if p < 15 else 0  # last LED DOUT unconnected
        cn[f"LED{sw_idx}"] = {
            "1": dout_net,  # Pin 1 = DOUT
            "2": 1,         # Pin 2 = GND
            "3": 2,         # Pin 3 = VDD
            "4": din_net,   # Pin 4 = DIN
        }

    # MCP23017 U1 (SOIC-28)
    cn["U1"] = {
        "1": 26,   # GPB0 -> ROW0
        "2": 27,   # GPB1 -> ROW1
        "3": 28,   # GPB2 -> ROW2
        "4": 29,   # GPB3 -> ROW3
        "5": 0,    # GPB4 NC
        "6": 0,    # GPB5 NC
        "7": 0,    # GPB6 NC
        "8": 0,    # GPB7 NC
        "9": 2,    # VDD -> 5V
        "10": 1,   # VSS -> GND
        "11": 0,   # NC (CS for SPI mode)
        "12": 4,   # SCL
        "13": 3,   # SDA
        "14": 0,   # NC
        "15": 1,   # A0 -> GND (addr 0x20)
        "16": 1,   # A1 -> GND
        "17": 1,   # A2 -> GND
        "18": 2,   # ~RESET -> 5V (not reset)
        "19": 0,   # INTB NC
        "20": 5,   # INTA -> INT
        "21": 22,  # GPA0 -> COL0
        "22": 23,  # GPA1 -> COL1
        "23": 24,  # GPA2 -> COL2
        "24": 25,  # GPA3 -> COL3
        "25": 0,   # GPA4 NC
        "26": 0,   # GPA5 NC
        "27": 0,   # GPA6 NC
        "28": 0,   # GPA7 NC
    }

    # MCP23017 decoupling cap C17
    cn["C17"] = {"1": 2, "2": 1}

    # JST-PH 6-pin connector J1
    cn["J1"] = {
        "1": 6,   # NEO_DIN
        "2": 3,   # SDA
        "3": 4,   # SCL
        "4": 5,   # INT
        "5": 2,   # 5V
        "6": 1,   # GND
    }

    return cn

COMP_NETS = build_comp_nets()


# ---------------------------------------------------------------------------
# Helpers
# ---------------------------------------------------------------------------

def gen_uuid():
    return str(uuid.uuid4())


def switch_xy(n):
    """Board (x, y) for switch n (1-indexed) center."""
    row = (n - 1) // GRID_COLS
    col = (n - 1) % GRID_COLS
    return GRID_ORIGIN_X + col * PITCH, GRID_ORIGIN_Y + row * PITCH


def arc_points(cx, cy, r, start_deg, end_deg, steps=8):
    points = []
    for i in range(steps + 1):
        angle = math.radians(start_deg + (end_deg - start_deg) * i / steps)
        points.append((cx + r * math.cos(angle), cy + r * math.sin(angle)))
    return points


# ---------------------------------------------------------------------------
# Board outline
# ---------------------------------------------------------------------------

def board_outline():
    """Generate board outline with rounded corners."""
    r = CORNER_R
    w, h = BOARD_W, BOARD_H
    lines = []

    # Straight edges
    edges = [
        (r, 0, w - r, 0),       # top
        (w, r, w, h - r),       # right
        (w - r, h, r, h),       # bottom
        (0, h - r, 0, r),       # left
    ]
    for x1, y1, x2, y2 in edges:
        lines.append(
            f'  (gr_line (start {x1} {y1}) (end {x2} {y2}) '
            f'(layer "{EDGE_CUTS}") (stroke (width 0.05) (type solid)) '
            f'(uuid "{gen_uuid()}"))'
        )

    # Corner arcs
    corners = [
        (r, r, 180, 270),           # top-left
        (w - r, r, 270, 360),       # top-right
        (w - r, h - r, 0, 90),      # bottom-right
        (r, h - r, 90, 180),        # bottom-left
    ]
    for cx, cy, start, end in corners:
        s_a = math.radians(start)
        m_a = math.radians((start + end) / 2)
        e_a = math.radians(end)
        sx, sy = cx + r * math.cos(s_a), cy + r * math.sin(s_a)
        mx, my = cx + r * math.cos(m_a), cy + r * math.sin(m_a)
        ex, ey = cx + r * math.cos(e_a), cy + r * math.sin(e_a)
        lines.append(
            f'  (gr_arc (start {sx:.4f} {sy:.4f}) (mid {mx:.4f} {my:.4f}) '
            f'(end {ex:.4f} {ey:.4f}) (layer "{EDGE_CUTS}") '
            f'(stroke (width 0.05) (type solid)) (uuid "{gen_uuid()}"))'
        )

    return "\n".join(lines)


# ---------------------------------------------------------------------------
# Footprint generators
# ---------------------------------------------------------------------------

def fp_choc_hotswap(ref, x, y, rotation, nets):
    """Kailh CHOC V1 hotswap socket (CPG135001S30).

    Pads (from switch center, default orientation):
      Pad 1: (0, -5.9mm)  — SMD 2.55x2.5mm
      Pad 2: (5.0, -3.8mm) — SMD 2.55x2.5mm
    Mounting holes (NPTH):
      Center: (0, 0) 3.2mm
      Sides: (-5.22, 0), (5.22, 0) 1.7mm
    """
    pad_lines = []
    pads = {"1": (0.0, -5.9), "2": (5.0, -3.8)}
    for name, (px, py) in pads.items():
        net_code = nets.get(name, 0)
        net_name = NETS.get(net_code, "")
        pad_lines.append(
            f'    (pad "{name}" smd roundrect (at {px} {py}) (size 2.55 2.5) '
            f'(layers "{F_CU}" "{F_MASK}") (roundrect_rratio 0.15) '
            f'(net {net_code} "{net_name}") (uuid "{gen_uuid()}"))'
        )

    # NPTH mounting holes omitted for routing — add back for manufacturing

    return f"""  (footprint "mixtee-footprints:Kailh_Choc_V1_Hotswap"
    (layer "{F_CU}")
    (uuid "{gen_uuid()}")
    (at {x} {y} {rotation})
    (property "Reference" "{ref}" (at 0 -8.5 {rotation}) (layer "{F_SILK}") (uuid "{gen_uuid()}") (effects (font (size 0.8 0.8) (thickness 0.12))))
    (property "Value" "CPG135001S30" (at 0 3 {rotation}) (layer "{F_FAB}") (uuid "{gen_uuid()}") (effects (font (size 0.8 0.8) (thickness 0.12))))
    (property "Footprint" "mixtee-footprints:Kailh_Choc_V1_Hotswap" (at 0 0 {rotation}) (layer "{F_FAB}") (uuid "{gen_uuid()}") (effects (font (size 1 1) (thickness 0.15)) hide))
{chr(10).join(pad_lines)}
  )"""


def fp_ws2812b_2020(ref, x, y, rotation, nets):
    """WS2812B-2020 NeoPixel LED (2x2mm).

    Pin layout (top view):
      Pin 1 (DOUT) — top-left    (-0.65, -0.475)
      Pin 2 (GND)  — bottom-left (-0.65,  0.475)
      Pin 3 (VDD)  — bottom-right (0.65,  0.475)
      Pin 4 (DIN)  — top-right    (0.65, -0.475)
    """
    pads = {
        "1": (-0.65, -0.475),   # DOUT
        "2": (-0.65,  0.475),   # GND
        "3": ( 0.65,  0.475),   # VDD
        "4": ( 0.65, -0.475),   # DIN
    }
    pad_lines = []
    for name, (px, py) in pads.items():
        net_code = nets.get(name, 0)
        net_name = NETS.get(net_code, "")
        pad_lines.append(
            f'    (pad "{name}" smd rect (at {px} {py}) (size 0.5 0.55) '
            f'(layers "{F_CU}" "{F_MASK}") '
            f'(net {net_code} "{net_name}") (uuid "{gen_uuid()}"))'
        )

    return f"""  (footprint "LED_SMD:WS2812B-2020"
    (layer "{F_CU}")
    (uuid "{gen_uuid()}")
    (at {x} {y} {rotation})
    (property "Reference" "{ref}" (at 0 -1.5 {rotation}) (layer "{F_SILK}") (uuid "{gen_uuid()}") (effects (font (size 0.6 0.6) (thickness 0.1))))
    (property "Value" "WS2812B-2020" (at 0 1.5 {rotation}) (layer "{F_FAB}") (uuid "{gen_uuid()}") (effects (font (size 0.6 0.6) (thickness 0.1))))
    (property "Footprint" "LED_SMD:WS2812B-2020" (at 0 0 {rotation}) (layer "{F_FAB}") (uuid "{gen_uuid()}") (effects (font (size 1 1) (thickness 0.15)) hide))
{chr(10).join(pad_lines)}
    (fp_line (start -1.1 -1.1) (end 1.1 -1.1) (stroke (width 0.12) (type solid)) (layer "{F_SILK}") (uuid "{gen_uuid()}"))
    (fp_line (start 1.1 -1.1) (end 1.1 1.1) (stroke (width 0.12) (type solid)) (layer "{F_SILK}") (uuid "{gen_uuid()}"))
    (fp_line (start 1.1 1.1) (end -1.1 1.1) (stroke (width 0.12) (type solid)) (layer "{F_SILK}") (uuid "{gen_uuid()}"))
    (fp_line (start -1.1 1.1) (end -1.1 -1.1) (stroke (width 0.12) (type solid)) (layer "{F_SILK}") (uuid "{gen_uuid()}"))
  )"""


def fp_sod123(ref, x, y, rotation, nets):
    """1N4148 diode in SOD-123 package.
    Pad 1 = Cathode (-1.1, 0), Pad 2 = Anode (1.1, 0)."""
    net1 = nets.get("1", 0)
    net2 = nets.get("2", 0)
    return f"""  (footprint "Diode_SMD:D_SOD-123"
    (layer "{F_CU}")
    (uuid "{gen_uuid()}")
    (at {x} {y} {rotation})
    (property "Reference" "{ref}" (at 0 -1.5 {rotation}) (layer "{F_SILK}") (uuid "{gen_uuid()}") (effects (font (size 0.6 0.6) (thickness 0.1))))
    (property "Value" "1N4148" (at 0 1.5 {rotation}) (layer "{F_FAB}") (uuid "{gen_uuid()}") (effects (font (size 0.6 0.6) (thickness 0.1))))
    (property "Footprint" "Diode_SMD:D_SOD-123" (at 0 0 {rotation}) (layer "{F_FAB}") (uuid "{gen_uuid()}") (effects (font (size 1 1) (thickness 0.15)) hide))
    (pad "1" smd roundrect (at -1.1 0 {rotation}) (size 1.0 0.7) (layers "{F_CU}" "{F_MASK}") (roundrect_rratio 0.25) (net {net1} "{NETS.get(net1, '')}") (uuid "{gen_uuid()}"))
    (pad "2" smd roundrect (at 1.1 0 {rotation}) (size 1.0 0.7) (layers "{F_CU}" "{F_MASK}") (roundrect_rratio 0.25) (net {net2} "{NETS.get(net2, '')}") (uuid "{gen_uuid()}"))
    (fp_line (start -1.8 -0.6) (end 1.8 -0.6) (stroke (width 0.12) (type solid)) (layer "{F_SILK}") (uuid "{gen_uuid()}"))
    (fp_line (start -1.8 0.6) (end 1.8 0.6) (stroke (width 0.12) (type solid)) (layer "{F_SILK}") (uuid "{gen_uuid()}"))
    (fp_line (start -1.8 -0.6) (end -1.8 0.6) (stroke (width 0.12) (type solid)) (layer "{F_SILK}") (uuid "{gen_uuid()}"))
  )"""


def fp_c0603(ref, x, y, rotation, nets, layer=None):
    """0603 capacitor. Pads at (-0.8, 0) and (0.8, 0), size 0.9x1.0."""
    if layer is None:
        layer = F_CU
    mask = F_MASK if layer == F_CU else B_MASK
    silk = F_SILK if layer == F_CU else B_SILK
    net1 = nets.get("1", 0)
    net2 = nets.get("2", 0)
    return f"""  (footprint "Capacitor_SMD:C_0603_1608Metric"
    (layer "{layer}")
    (uuid "{gen_uuid()}")
    (at {x} {y} {rotation})
    (property "Reference" "{ref}" (at 0 -1.3 {rotation}) (layer "{silk}") (uuid "{gen_uuid()}") (effects (font (size 0.6 0.6) (thickness 0.1))))
    (property "Value" "100nF" (at 0 1.3 {rotation}) (layer "{F_FAB}") (uuid "{gen_uuid()}") (effects (font (size 0.6 0.6) (thickness 0.1))))
    (property "Footprint" "Capacitor_SMD:C_0603_1608Metric" (at 0 0 {rotation}) (layer "{F_FAB}") (uuid "{gen_uuid()}") (effects (font (size 1 1) (thickness 0.15)) hide))
    (pad "1" smd roundrect (at -0.8 0 {rotation}) (size 0.9 1.0) (layers "{layer}" "{mask}") (roundrect_rratio 0.25) (net {net1} "{NETS.get(net1, '')}") (uuid "{gen_uuid()}"))
    (pad "2" smd roundrect (at 0.8 0 {rotation}) (size 0.9 1.0) (layers "{layer}" "{mask}") (roundrect_rratio 0.25) (net {net2} "{NETS.get(net2, '')}") (uuid "{gen_uuid()}"))
  )"""


def fp_mcp23017(ref, x, y, rotation, nets):
    """MCP23017 SOIC-28 (MCP23017-E/SO).

    28 pins, 14 per side, 1.27mm pitch.
    Pad center-to-center across: 8.89mm (±4.445 from center).
    Pad size: 1.55mm (length, perpendicular to row) x 0.6mm (width, along row).
    Pins 1-14 on left, 15-28 on right (counter-clockwise).

    NOTE: KiCad .kicad_pcb (size sx sy) is in BOARD coordinates — it does NOT
    rotate with the footprint.  When the footprint is placed at 90°, we must
    swap the pad dimensions so that the 0.6mm (along-row) dimension aligns
    with the board axis carrying the 1.27mm pin pitch.
    """
    pad_lines = []
    half_span = 13 * 1.27 / 2  # 8.255mm from first to last pin

    # Pad size in footprint's unrotated frame: (1.55, 0.6)
    # Swap for 90°/270° rotation so the narrow dimension stays along pin pitch
    pad_length = 1.55  # perpendicular to pin row
    pad_width = 0.6    # along pin row (must be < 1.27mm pitch)
    if rotation in (90, 270):
        pad_sx, pad_sy = pad_width, pad_length   # (0.6, 1.55) on board
    else:
        pad_sx, pad_sy = pad_length, pad_width    # (1.55, 0.6) on board

    for pin in range(1, 29):
        if pin <= 14:
            # Left column, top to bottom
            px = -4.445
            py = -half_span + (pin - 1) * 1.27
        else:
            # Right column, bottom to top
            px = 4.445
            py = half_span - (pin - 15) * 1.27
        net_code = nets.get(str(pin), 0)
        net_name = NETS.get(net_code, "")
        pad_lines.append(
            f'    (pad "{pin}" smd roundrect (at {px:.3f} {py:.3f}) (size {pad_sx} {pad_sy}) '
            f'(layers "{F_CU}" "{F_MASK}") (roundrect_rratio 0.25) '
            f'(net {net_code} "{net_name}") (uuid "{gen_uuid()}"))'
        )

    body_half_w = 3.75
    body_half_h = half_span + 0.5

    return f"""  (footprint "Package_SO:SOIC-28W_7.5x17.9mm_P1.27mm"
    (layer "{F_CU}")
    (uuid "{gen_uuid()}")
    (at {x} {y} {rotation})
    (property "Reference" "{ref}" (at 0 {-body_half_h - 1.5} {rotation}) (layer "{F_SILK}") (uuid "{gen_uuid()}") (effects (font (size 1 1) (thickness 0.15))))
    (property "Value" "MCP23017" (at 0 {body_half_h + 1.5} {rotation}) (layer "{F_FAB}") (uuid "{gen_uuid()}") (effects (font (size 1 1) (thickness 0.15))))
    (property "Footprint" "Package_SO:SOIC-28W_7.5x17.9mm_P1.27mm" (at 0 0 {rotation}) (layer "{F_FAB}") (uuid "{gen_uuid()}") (effects (font (size 1 1) (thickness 0.15)) hide))
{chr(10).join(pad_lines)}
    (fp_line (start {-body_half_w} {-body_half_h}) (end {body_half_w} {-body_half_h}) (stroke (width 0.15) (type solid)) (layer "{F_SILK}") (uuid "{gen_uuid()}"))
    (fp_line (start {body_half_w} {-body_half_h}) (end {body_half_w} {body_half_h}) (stroke (width 0.15) (type solid)) (layer "{F_SILK}") (uuid "{gen_uuid()}"))
    (fp_line (start {body_half_w} {body_half_h}) (end {-body_half_w} {body_half_h}) (stroke (width 0.15) (type solid)) (layer "{F_SILK}") (uuid "{gen_uuid()}"))
    (fp_line (start {-body_half_w} {body_half_h}) (end {-body_half_w} {-body_half_h}) (stroke (width 0.15) (type solid)) (layer "{F_SILK}") (uuid "{gen_uuid()}"))
  )"""


def fp_jst_ph_6(ref, x, y, rotation, nets):
    """JST-PH B6B-PH-K 6-pin vertical through-hole connector.
    Pins at 2mm pitch, pin 1 at origin, pins going in +X."""
    pad_lines = []
    for i in range(6):
        pin = str(i + 1)
        net_code = nets.get(pin, 0)
        net_name = NETS.get(net_code, "")
        pad_lines.append(
            f'    (pad "{pin}" thru_hole circle (at {i * 2.0} 0) (size 1.75 1.75) '
            f'(drill 0.8) (layers "*.Cu" "*.Mask") '
            f'(net {net_code} "{net_name}") (uuid "{gen_uuid()}"))'
        )
    return f"""  (footprint "Connector_JST:JST_PH_B6B-PH-K_1x06_P2.00mm_Vertical"
    (layer "{F_CU}")
    (uuid "{gen_uuid()}")
    (at {x} {y} {rotation})
    (property "Reference" "{ref}" (at 5 -2.5 {rotation}) (layer "{F_SILK}") (uuid "{gen_uuid()}") (effects (font (size 1 1) (thickness 0.15))))
    (property "Value" "B6B-PH-K-S" (at 5 3 {rotation}) (layer "{F_FAB}") (uuid "{gen_uuid()}") (effects (font (size 1 1) (thickness 0.15))))
    (property "Footprint" "Connector_JST:JST_PH_B6B-PH-K_1x06_P2.00mm_Vertical" (at 0 0 {rotation}) (layer "{F_FAB}") (uuid "{gen_uuid()}") (effects (font (size 1 1) (thickness 0.15)) hide))
{chr(10).join(pad_lines)}
    (fp_line (start -1.25 -1.6) (end 11.25 -1.6) (stroke (width 0.12) (type solid)) (layer "{F_SILK}") (uuid "{gen_uuid()}"))
    (fp_line (start 11.25 -1.6) (end 11.25 4.4) (stroke (width 0.12) (type solid)) (layer "{F_SILK}") (uuid "{gen_uuid()}"))
    (fp_line (start 11.25 4.4) (end -1.25 4.4) (stroke (width 0.12) (type solid)) (layer "{F_SILK}") (uuid "{gen_uuid()}"))
    (fp_line (start -1.25 4.4) (end -1.25 -1.6) (stroke (width 0.12) (type solid)) (layer "{F_SILK}") (uuid "{gen_uuid()}"))
  )"""


# ---------------------------------------------------------------------------
# PCB assembly
# ---------------------------------------------------------------------------
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

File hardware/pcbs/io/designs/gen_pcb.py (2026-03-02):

"""
MIXTEE IO Board - KiCad PCB Generator

Board: 50 x 80 mm, 2-layer
Instances: 1
Orientation: Horizontal, under top panel (left side)

Components (32 total):
  ICs (4):
    U1  FE1.1s USB 2.0 hub (SSOP-28) + Y1 12MHz crystal (3225)
    U2  TPS2051 USB power switch port 1 (SOT-23-5)
    U3  TPS2051 USB power switch port 2 (SOT-23-5)
    U4  6N138 optocoupler MIDI IN (DIP-8)
  Caps (12):
    C1,C2   15pF crystal load (0603)
    C3      100nF FE1.1s VDD5 decoupling (0603)
    C4      100nF FE1.1s VDD33 decoupling (0603)
    C5      10uF  FE1.1s VDD33 bulk (0805)
    C6,C7   100nF TPS2051 input decoupling (0603)
    C8-C11  100nF Ethernet coupling (0603)
    C12     100nF 6N138 VCC decoupling (0603)
  Resistors (5):
    R1  220ohm MIDI IN series (0603)
    R2  470ohm MIDI RX pull-up (0603)
    R3  33ohm  MIDI OUT series (0603)
    R4  10ohm  MIDI OUT source (0603)
    R5  12kohm FE1.1s REXT (0603)
  Diode (1):
    D1  1N4148 MIDI IN protection (SOD-123)
  Connectors (10):
    J1  USB-A dual stacked (67298-4090, through-hole)
    J2  RJ45 MagJack w/ magnetics (through-hole)
    J3  3.5mm TRS MIDI IN (SJ-3523-SMT)
    J4  3.5mm TRS MIDI OUT (SJ-3523-SMT)
    J5  FFC 12-pin ZIF 1.0mm
    J6  6-pin header Ethernet ribbon (2.54mm)
    J7  4-pin header HP breakout input (2.54mm)
    J8  Headphone TRS jack (through-hole)
    J9  3-pin header HP amp output (2.54mm)
    VR1 Dual-gang 10kohm log pot (through-hole)

Layout (top view, y=0 = panel edge, y=80 = interior/FFC edge):

  x=0                                                     x=50
  ┌──────────────────────────────────────────────────────────┐
  │  J1 USB-A (12,8)          J2 RJ45 (38,10)               │ y=0
  │                                                          │
  │  U1 FE1.1s (14,24)    U2(30,22) U3(38,22)              │
  │  Y1(5,24) C1 C2       C6  C7    R5                     │
  │  C3 C4 C5                                               │
  │                        U4 6N138 (38,32)                 │
  │  J3 MIDI_IN (10,42)   R1 R2 D1  C12                    │
  │  J4 MIDI_OUT (30,42)  R3 R4                             │
  │                                                          │
  │  J8 HP jack (10,58)   VR1 pot (30,58)                   │
  │                        J7(42,58) J9(42,52)              │
  │                                                          │
  │  J5 FFC (12,76)        J6 ETH hdr (38,76)              │ y=80
  └──────────────────────────────────────────────────────────┘

FE1.1s pinout (SSOP-28) — NEEDS VERIFICATION against actual datasheet:
  Pins 1-14 left side (top to bottom), pins 15-28 right side (bottom to top)
  Pin 1:  VDD5_2    Pin 28: VDD5
  Pin 2:  DM0       Pin 27: GND_2
  Pin 3:  DP0       Pin 26: GND
  Pin 4:  VDD33     Pin 25: TEST_N
  Pin 5:  XO        Pin 24: BUS_PWR_N
  Pin 6:  XI        Pin 23: SUSP_N
  Pin 7:  REXT      Pin 22: CFG_SEL0
  Pin 8:  VDD33O    Pin 21: CFG_SEL1
  Pin 9:  DM4       Pin 20: PSELF
  Pin 10: DP4       Pin 19: PGANG_N
  Pin 11: DM3       Pin 18: PWREN_N
  Pin 12: DP3       Pin 17: OVCR_N
  Pin 13: DM2       Pin 16: DP1
  Pin 14: DP2       Pin 15: DM1
"""

import uuid
import math
import os


# ---------------------------------------------------------------------------
# Board parameters
# ---------------------------------------------------------------------------

BOARD_W = 50.0   # mm
BOARD_H = 80.0   # mm
CORNER_R = 1.0   # mm

# Layers
F_CU = "F.Cu"
B_CU = "B.Cu"
F_SILK = "F.SilkS"
B_SILK = "B.SilkS"
F_MASK = "F.Mask"
B_MASK = "B.Mask"
F_FAB = "F.Fab"
F_CRTYD = "F.CrtYd"
EDGE_CUTS = "Edge.Cuts"


# ---------------------------------------------------------------------------
# Net definitions
# ---------------------------------------------------------------------------

NETS = {
    0: "",
    1: "GND",
    2: "5V_DIG",
    3: "V33",
    4: "USB_UP_DP",
    5: "USB_UP_DM",
    6: "USB_DN1_DP",
    7: "USB_DN1_DM",
    8: "USB_DN2_DP",
    9: "USB_DN2_DM",
    10: "VBUS1",
    11: "VBUS2",
    12: "XTAL_IN",
    13: "XTAL_OUT",
    14: "REXT_N",
    15: "ETH_TXP",
    16: "ETH_TXN",
    17: "ETH_RXP",
    18: "ETH_RXN",
    19: "ETH_TXP_MJ",
    20: "ETH_TXN_MJ",
    21: "ETH_RXP_MJ",
    22: "ETH_RXN_MJ",
    23: "ETH_LED",
    24: "MIDI_RX",
    25: "MIDI_TX",
    26: "MIDI_IN_R",
    27: "MIDI_IN_OA",
    28: "MIDI_IN_OK",
    29: "MIDI_OUT_SRC",
    30: "MIDI_OUT_SINK",
    31: "HP_L",
    32: "HP_R",
    33: "5V_A",
    34: "HP_AMP_L",
    35: "HP_AMP_R",
    36: "HP_OUT_L",
    37: "HP_OUT_R",
}


# ---------------------------------------------------------------------------
# Component-to-net mapping
# ---------------------------------------------------------------------------
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

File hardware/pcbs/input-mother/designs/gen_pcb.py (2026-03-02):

"""
MIXTEE Input Mother Board - KiCad PCB Generator

Board: 80 x 40 mm, 4-layer (F.Cu, In1.Cu=GND, In2.Cu=V33_A, B.Cu)
Instances: 2 (Board 1-bottom: ch 1-8, Board 2-bottom: ch 9-16)
Orientation: Lower board in pair (daughter above), jacks at panel edge (y=40)

Components (71 total):
  Codecs (2):
    U1  AK4619VN (QFN-32, 5x5mm, 0.5mm pitch) — ch 1-4, I2C 0x10
    U2  AK4619VN (QFN-32, 5x5mm, 0.5mm pitch) — ch 5-8, I2C 0x11
  Op-amps (4):
    U4  OPA1678 dual (SOIC-8) — Sallen-Key ch 1,2
    U5  OPA1678 dual (SOIC-8) — Sallen-Key ch 3,4
    U6  OPA1678 dual (SOIC-8) — Sallen-Key ch 5,6
    U7  OPA1678 dual (SOIC-8) — Sallen-Key ch 7,8
  LDO (1):
    U3  ADP7118 (SOIC-8) — 5V -> 3.3V_A
  TS Jacks (4):
    J1-J4  Switchcraft 112BPC — L channels
  Connectors (2):
    J5  FFC 16-pin ZIF 1.0mm (to Main Board)
    J6  JST-PH 6-pin (to Daughter Board)
  ESD diodes (8):
    D1-D8  SOD-323 Schottky clamp
  AC coupling caps (4):
    C1-C4  10uF 0805 (L channel input coupling)
  Filter passives (32):
    R1-R16   1k 0603 (Sallen-Key resistors, 2 per channel)
    C5-C20   3.3nF/6.8nF 0603 (Sallen-Key caps, 2 per channel)
  Codec decoupling (8):
    C21-C24  100nF 0603 (AVDD/TVDD per codec, 2 each)
    C25-C28  2.2uF 0805 (AVDRV/VCOM per codec, 2 each)
  LDO caps (4):
    C29  100nF 0603 (LDO input)
    C30  1uF 0805 (LDO output)
    C31  10uF 0805 (LDO output bulk)
    C32  100nF 0603 (5V_DIG local decoupling)
  Pull-ups (2):
    R17  10k 0603 (U1 PDN pull-up to V33_A)
    R18  10k 0603 (U2 PDN pull-up to V33_A)

Layout (y=0 interior/FFC edge, y=30 panel edge):

  x=0                                                              x=80
  +--------------------------------------------------------------------+
  | U3(LDO,5,4)  J5(FFC-16,25,2)              J6(JST-PH-6,62,2)      | y=0
  | C29 C30 C31  C32                                                   |
  |    U1(AK4619,18,10)              U2(AK4619,58,10)                 |
  |  C21 C22 C25 C26              C23 C24 C27 C28                     |
  |                                                                    |
  |  U4(16,18) U5(26,18)          U6(56,18) U7(66,18)                | y~18
  |  R1-R4 C5-C8                  R9-R12 C13-C16                      |
  |  R5-R8 C9-C12                 R13-R16 C17-C20                     |
  |  D1-D4  C1-C4                 D5-D8                                |
  |  J1(10,30) J2(30,30)          J3(50,30) J4(70,30)                | y=30
  +--------------------------------------------------------------------+
"""

import uuid
import math
import os


# ---------------------------------------------------------------------------
# Board parameters
# ---------------------------------------------------------------------------

BOARD_W = 80.0   # mm
BOARD_H = 40.0   # mm  (increased from 30 to clear jack pads from filter zone)
CORNER_R = 1.0   # mm

# Layers
F_CU = "F.Cu"
IN1_CU = "In1.Cu"
IN2_CU = "In2.Cu"
B_CU = "B.Cu"
F_SILK = "F.SilkS"
B_SILK = "B.SilkS"
F_MASK = "F.Mask"
B_MASK = "B.Mask"
F_PASTE = "F.Paste"
F_FAB = "F.Fab"
F_CRTYD = "F.CrtYd"
EDGE_CUTS = "Edge.Cuts"


# ---------------------------------------------------------------------------
# Net definitions
# ---------------------------------------------------------------------------

NETS = {
    0: "",
    # Power
    1: "GND",
    2: "5V_A",
    3: "V33_A",
    4: "5V_DIG",
    # TDM bus (shared by both codecs on this board)
    5: "MCLK",
    6: "BCLK",
    7: "LRCLK",
    8: "SDIN1",         # Teensy -> both codecs
    9: "SDOUT1",        # U1 -> Teensy (FFC pin 4)
    10: "SDOUT2",       # U2 -> Teensy (FFC pin 13)
    # I2C
    11: "SDA",
    12: "SCL",
    # Codec internal rails
    13: "U1_AVDRV",     # U1 internal LDO output
    14: "U1_VCOM",      # U1 AVDD/2 reference
    15: "U2_AVDRV",     # U2 internal LDO output
    16: "U2_VCOM",      # U2 AVDD/2 reference
    # Audio input nets (from jacks, after AC coupling)
    17: "AIN_1_AC",     # Ch 1 after AC coupling cap
    18: "AIN_2_AC",     # Ch 2
    19: "AIN_3_AC",     # Ch 3
    20: "AIN_4_AC",     # Ch 4
    21: "AIN_5_AC",     # Ch 5
    22: "AIN_6_AC",     # Ch 6
    23: "AIN_7_AC",     # Ch 7
    24: "AIN_8_AC",     # Ch 8
    # Raw jack tip nets (before AC coupling)
    25: "JACK_1",
    26: "JACK_2",
    27: "JACK_3",
    28: "JACK_4",
    # Filter node 1 (between R1 and R2 in Sallen-Key)
    29: "FN1_1",
    30: "FN1_2",
    31: "FN1_3",
    32: "FN1_4",
    33: "FN1_5",
    34: "FN1_6",
    35: "FN1_7",
    36: "FN1_8",
    # Filter node 2 (op-amp output = filter output -> codec ADC)
    37: "FOUT_1",
    38: "FOUT_2",
    39: "FOUT_3",
    40: "FOUT_4",
    41: "FOUT_5",
    42: "FOUT_6",
    43: "FOUT_7",
    44: "FOUT_8",
    # Op-amp power
    45: "VOPA",         # 5V_A to op-amp VCC (same as 5V_A but separate for clarity)
    # Daughter board signals (via JST-PH-6)
    # R channels come from Daughter Board: pins 1-4 are AIN for R channels
    46: "DAIN_R1",      # Daughter board ch R1 (e.g. ch 2)
    47: "DAIN_R2",      # Daughter board ch R2 (e.g. ch 4)
    48: "DAIN_R3",      # Daughter board ch R3 (e.g. ch 6)
    49: "DAIN_R4",      # Daughter board ch R4 (e.g. ch 8)
    # Filter nodes for R channels (from daughter board, through filter)
    50: "FN1_R1",
    51: "FN1_R2",
    52: "FN1_R3",
    53: "FN1_R4",
    54: "FOUT_R1",
    55: "FOUT_R2",
    56: "FOUT_R3",
    57: "FOUT_R4",
}

# Alias: op-amp VCC is just 5V_A
# We'll use net 2 (5V_A) directly for op-amp power pins


# ---------------------------------------------------------------------------
# Component-to-net mapping
# ---------------------------------------------------------------------------
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

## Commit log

2026-02-28 Add I2C mux, GPIO expander, expand to 16 keys, upgrade power delivery
    Hardware architecture changes:
    - TCA9548A I2C mux (0x70) on main board isolates codec boards
    - MCP23017 GPIO expander (0x20) on Key PCB handles 4x4 key matrix
    - Key grid expanded from 3x4 (12) to 4x4 (16 keys)
    - Key cable simplified from 10-pin to 6-pin JST-PH
    - 7 Teensy GPIO pins freed (17 used, 8 spare)
    Power delivery upgrade (USB PD):
    - STUSB4500 PD sink controller for 5V/5A (fallback 3A)
    - TPS22965 load switch (5A, replaces TPS22918)
    - Polyfuse upgraded to 2.5A/5A
    - NeoPixel bulk cap upsized to 1000-2200uF
    - Brightness cap changed to 30% default (hardware sized for uncapped)
    Housekeeping:
    - Vendor docs moved to .reff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
    [bom.csv]
2026-03-01 Update docs, BOM, layout for 16-key/I2C-mux design; add journal
    Sync documentation with expanded hardware design: updated pin
    mapping, codec wiring, PCB architecture, enclosure, and features
    docs to reflect TCA9548A mux, MCP23017 expander, 16-key matrix,
    and USB-PD power delivery. Added connector parts list, PCB design
    rules, and UI layout (Affinity). Removed obsolete reference PDF.
    Added development journal for tracking PCB routing progress.
    [bom.csv]
2026-03-01 Add hardware/pcbs/ with per-board architecture docs
    New structure: hardware/pcbs/{main,input-mother,daughter-output,key}/
    each containing a README.md with board dimensions, components,
    connectors, and current status. PCB files will be added as boards
    are finalized.
2026-03-01 Add daughter-output KiCad project, Gerbers, and PCB workflow docs
    Daughter/Output board fully routed via FreeRouting autoroute with
    Specctra DSN/SES round-trip. 0 DRC errors, 0 unconnected nets.
    Includes gen_pcb.py generator, custom footprint library, Gerber
    export, and pcbs-workflow documentation.
    [mixtee-daughter-output-B_Cu.gbl, mixtee-daughter-output-B_Mask.gbs, mixtee-daughter-output-B_Silkscreen.gbo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]
2026-03-01 Add Key PCB KiCad project, Gerbers, and FreeRouting routing
    72x80mm 2-layer board with 67 components: 16 CHOC hotswap sockets,
    16 WS2812B NeoPixels, 16 decoupling caps, 16 anti-ghosting diodes,
    MCP23017 GPIO expander, and JST-PH 6-pin connector. All 139
    connections routed via FreeRouting autoroute with 0 DRC errors.
    [mixtee-key-pcb-B_Courtyard.gbr, mixtee-key-pcb-B_Cu.gbl, mixtee-key-pcb-B_Fabrication.gbr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]
2026-03-01 Split Main Board into Main Board + IO Board
    Move headphone amp (TPA6132A2), USB hub (FE1.1s), and MIDI I/O
    circuits onto a new dedicated IO Board (~50x80mm, 2-layer).
    PC USB-C relocates to back panel next to PWR USB-C.
    SD card slot moves to left zone (left of display) on top panel.
    12-pin 1.0mm FFC interconnects Main and IO boards.
    6 unique PCB designs, 10 physical boards.
    [bom.csv]
2026-03-01 Update panel layout images for IO Board split
2026-03-01 Move PC USB-C to top panel, add Power Board, update SD position
    Three design changes reflected across all docs:
    - PC USB-C moved from back panel to top panel (Main Board mount)
    - PWR USB-C moved to new Power Board (7th unique PCB, back panel)
    - SD card vertically aligned with bottom edge of display
    Updated: pcb-architecture.md, hardware.md, enclosure.md,
    connector-parts.md, ak4619-wiring.md, CLAUDE.md, bom.csv,
    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
    [bom.csv]
2026-03-01 Change Power Board to off-the-shelf STUSB4500 breakout module
    No custom PCB needed — purchased module (SparkFun PD Board or
    equivalent) handles USB PD negotiation. Wires 5V+GND to Main Board.
    Updated all docs to reflect 6 custom PCBs + 1 off-the-shelf module.
    [bom.csv]
2026-03-01 Add Ethernet, move IO Board to left, HP amp to breakout, power button to back panel
    - IO Board moved from right to left side of top panel
    - Added native Ethernet (DP83825I PHY) via RJ45 MagJack on IO Board
    - Replaced TPA6132A2 IC with off-the-shelf HP amp breakout module
    - Moved power button from top panel to back panel (screw-collar, next to PWR USB-C)
    - Updated Main-IO FFC pinout: Ethernet differential pairs replace HP signals
    - Added IO Board Stage 1 spec (hardware/pcbs/io/README.md)
    - Updated panel layout images for new arrangement
    - Cross-referenced all docs: pcb-architecture, pin-mapping, hardware, enclosure,
    connector-parts, ak4619-wiring, features, bom.csv, CLAUDE.md, main board RE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
    [bom.csv]
2026-03-02 Restructure docs into layered agent context
    Split flat docs/ into per-board documentation layers so agents load
    only board-relevant context (~13-30KB) instead of full doc set (~90KB).
    Each board gets connections.md (interface contract), architecture.md
    (implementation detail), and CLAUDE.md (agent guide). Design files
    moved into designs/ subdirectories. Shared docs trimmed with redirects.
    Renamed pcb-architecture.md to system-topology.md.
    [mixtee-daughter-output-B_Cu.gbl, mixtee-daughter-output-B_Mask.gbs, mixtee-daughter-output-B_Silkscreen.gbo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]
2026-03-06 Fix architecture diagram: TS5A3159 signal path, IO/Key cable topology, HP detect return
2026-03-09 Add display engine architecture with SD card update mechanism
    Device-agnostic LVGL display engine on ESP32-S3, binary widget protocol
    (COBS/CRC16 at 921600 baud), ui.json layout on SD card, and single SD
    card update for all firmware (FlasherX + esp-serial-flasher). Pins 9/10
    assigned to ESP32 EN/GPIO0 for bootloader control; display header
    expanded from 4-pin to 6-pin.
    [bom.csv]
2026-03-09 Name DESPEE explicitly as the standard display module across all docs
    Previously referred to generically as "ESP32-S3 custom display PCB" —
    now consistently named DESPEE with links to openaudiotools/despee.
    BOM updated from off-the-shelf module pricing to custom PCB ($15-20).
    [bom.csv]
2026-03-13 Move journal to docs/journal, add journal plugin GUIDE.md and @import
    Relocated journal/ → docs/journal/, replaced inline journal section in
    CLAUDE.md with @docs/journal/GUIDE.md import, added lock file pattern
    to .gitignore.
2026-03-21 Rename Key PCB to Keys4x4 PCB across all docs and board directory
    Renames hardware/pcbs/key/ to hardware/pcbs/keys4x4/ and updates all
    cross-references (20+ files). Avoids ambiguity between the board name
    and generic "key" (switches, keycaps). Journal entries left as-is.
    [bom.csv]
2026-03-21 Fix BOM/architecture discrepancies: VG buffer, op-amp counts, module boundaries
    - Move 2.5V virtual ground buffer from Main Board to Input Mother Boards
    (can't cross galvanic isolation boundary); remove Main Board ADP7118 LDO
    - Correct OPA1678 count: 17/16 → 26 (Board 1-top: 17, Board 2-top: 9)
    - ADP7118 count: 3 → 2 (1 per Input Mother Board, none on Main Board)
    - Precision resistors: 2 → 4 (1 matched pair per Input Mother Board)
    - Add missing MIDI IN jack to hardware.md BOM
    - Remove unnecessary Ethernet coupling caps (MagJack has integrated magnetics)
    - Split Power & Connectivity into separate sections in hardware.md
    - Replace duplicate hardware.md BOM tables with pointer to bom.cs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
    [bom.csv]
2026-03-21 Add journal entry 027: BOM architecture discrepancy review
2026-03-21 PHONEE module renaming, external module boundaries, and pending journal entries
    - Update HP board references to PHONEE across all docs
    - List PHONEE and DESPEE as external modules in BOM
    - Add journal entries 022 (state sync), 024-026 (PHONEE extraction), 028 (module BOM cleanup)
2026-03-21 Consolidate power docs into docs/power.md, fix budget and polyfuse issues
    Merged power documentation from hardware/pcbs/power/ (4 files), docs/hardware.md,
    and main/architecture.md into a single docs/power.md. Deleted the power board PCB
    directory since it's an off-the-shelf module. Fixed power budget math (about#18:
    2.67A→2.91A worst-case) and polyfuse location (about#17: Power Board→Main Board).
    Added "Why 5V?" info block explaining the voltage choice.
